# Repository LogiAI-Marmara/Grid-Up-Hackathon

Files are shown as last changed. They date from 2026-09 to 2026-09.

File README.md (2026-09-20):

# Grid-Up — Pano İçi Anomali Erken Uyarı Sistemi

**ADM & GDZ Elektrik — Grid Up Hackathon (2026)**  
*OG Hücreleri ve AG Dağıtım Panolarında Çok Kanallı Durum İzleme ve Uçtan Uca Anomali Erken Uyarı Platformu*

---

## 📌 Proje Özeti

Elektrik dağıtım şebekesindeki orta gerilim (OG) hücreleri ve alçak gerilim (AG) panolarında meydana gelen yangın, ekipman hasarı ve enerji kesintilerinin büyük bölümü (gevşek klemens, aşırı yük, faz dengesizliği, yoğuşma, yalıtım kaybı); **kritik arıza gerçekleşmeden önce ısınma, nem artışı ve akım dengesizlikleriyle sinyal verir.**

**Grid-Up**, pano içine yerleştirilen endüstriyel sınıf sensör modülü tasarımıyla başlayıp, saha gateway'i üzerinden şirket içi (**on-premise**) sunucuya ulaşan, çok katmanlı istatistiksel anomali tespit motoruyla arızayı kök nedeninde yakalayan ve operatörlere **SCADA (Modbus TCP)**, **Web İzleme Arayüzü** ile yerel ağdaki **Android SMS Gateway** üzerinden SMS bildirimi ileten uçtan uca, çalışan bir erken uyarı sistemidir.

> **Önemli Kısıtlar & Mimari İlkeler:**
> 1. **%100 On-Premise:** Şartname gereği **Public Cloud (AWS, Azure, GCP vb.) kesinlikle kullanılmamıştır.** Tüm veri saklama, analiz, arayüz ve alarm servisleri yerel ağda tek bir `docker-compose` komutuyla izole çalışır.
> 2. **Endüstriyel Donanım Tasarımı:** Şartname uyarınca fiziksel satın alma ve pano montajı yapılmamış; ancak TEDAŞ-MLZ/2003-06.B şartnamesine tabi **1600 kVA AG Dağıtım Panosu** referans alınarak −40…+85 °C endüstriyel sınıf bileşenlerle eksiksiz CAD (Fusion 360) ve EDA (KiCad) tasarım dokümantasyonu üretilmiştir.
> 3. **Gerçekçi Yazılım & Sentetik Veri:** Donanım üretilmediği için veri sentetik üreteçle fizik kurallarına uygun simüle edilmiş; yazılım tarafının tamamı (veri toplama, veritabanı, anomali motoru, REST API, Modbus TCP, alarm servisi, frontend) **gerçek ve çalışır durumdadır.**

---

## 🏛️ Uçtan Uca Sistem Mimarisi

Sistem, fiziksel pano içi donanımdan merkezi operasyon yüzüne kadar birbirine sıkı sözleşmelerle bağlı 3 ana katmandan oluşur:

```
┌──────────────────────── PANO İÇİ ─────────────────────────┐
│                                                           │
│  Sensörler: SHT31 (Sıcaklık/Nem) + MLX90640 (Termal Dizi) │
│  Akım: Enerji Analizörü (Modbus) veya Split-core CT ×4    │
│  Ark: ABB TVOC-2 (RS-485 Modbus Okuma)                    │
│                                │                          │
│                                ▼                          │
│               [ MODÜL: ESP32-S3-WROOM-1U-N8 ]             │
│               (230V İç İhtiyaç + Süperkapasitör)          │
│                                │                          │
│                                ▼                          │
│               Dış Anten (Panel SMA / 2.4 GHz)             │
└────────────────────────────────┼──────────────────────────┘
                                 │ Kablosuz (Wi-Fi)
                      ┌──────────▼──────────┐
                      │    SAHA GATEWAY     │ (Trafo binası içi, 230V)
                      └──────────┬──────────┘
                                 │ Mevcut Saha Altyapısı (HTTP)
        ═════════════════ ON-PREMISE SUNUCU ═════════════════
        │                                                   │
        │  ① Toplama Servisi (FastAPI :8000) ──► PostgreSQL │
        │                                            │      │
        │  ② Anomali Motoru (4 Katmanlı Medyan+MAD) ◄┘      │
        │         │                                         │
        │         ├──► ③ Okuma API'si (FastAPI :8080)       │
        │         │           │                             │
        │         │           ├─► ④ Web İzleme UI (nginx:80)│
        │         │           └─► ⑤ Modbus TCP (:5020/SCADA)│
        │         │                                         │
        │         └──► ⑥ Alarm Servisi                      │
        │                 ├─► Android SMS Gateway (LAN)     │
        │                 └─► Telegram (seçmeli, kapalı)    │
        ═════════════════════════════════════════════════════
```

Uçtan Uca Sistem Mimarisi
*Pano içi modülden saha gateway'ine, merkezi veritabanından analiz motoru, SCADA, web izleme arayüzü ve alarm servisine uçtan uca sistem mimarisi.*

---

## 📋 Teslimat Kalemleri Matrisi (T1 – T7)

Yarışma şartnamesindeki tüm teslimat kalemleri projemizde eksiksiz karşılanmıştır:

| Kod | Kalem | Karşılığı Olan Çıktılar & Konum |
|---|---|---|
| **T1** | **Kabin İçi Modül / Prototip Tasarımı** | [`docs/track-a/01-blok-sema.md`](docs/track-a/01-blok-sema.md) · [`02-bom.md`](docs/track-a/02-bom.md) · [`04-mekanik-yerlesim.md`](docs/track-a/04-mekanik-yerlesim.md) · [`06-montaj-proseduru.md`](docs/track-a/06-montaj-proseduru.md) · CAD Modelleri ([`cad/`](docs/track-a/cad/)) |
| **T2** | **Elektronik Tasarım Dokümantasyonu** | [`docs/track-a/03-pinout.md`](docs/track-a/03-pinout.md) · [`03-baglanti-semasi.svg`](docs/track-a/03-baglanti-semasi.svg) · KiCad EDA Projesi ([`eda/`](docs/track-a/eda/)) · [`02-pcb-yerlesimi.svg`](docs/track-a/02-pcb-yerlesimi.svg) |
| **T3** | **Yazılım Mimarisi** | [`docs/track-a/07-yazilim-akis.md`](docs/track-a/07-yazilim-akis.md) · [`08-sistem-mimarisi.svg`](docs/track-a/08-sistem-mimarisi.svg) · [`firmware/`](firmware/) · [`modul-sim/`](modul-sim/) · [`analiz/`](analiz/) · [`arayuz/`](arayuz/) |
| **T4** | **Monitoring (İzleme) Platformu** | [`arayuz/`](arayuz/) (Nginx üzerinde Web Dashboard, Isı Haritası, Canlı Metrikler) · [`modbus/`](modbus/) (SCADA Modbus TCP Sunucusu) |
| **T5** | **Ölçeklenebilirlik & Kaynak Kullanımı** | [`analiz/`](analiz/) (100 modül eşzamanlı ingest ve anomali tarama testi, kaynak tüketim raporu) · [`modul-sim`](modul-sim/) (`--modul 100`) |
| **T6** | **On-Premise / Özel Altyapı** | [`deploy/docker-compose.yml`](deploy/docker-compose.yml) (Public Cloud bağımsızlığı, tek komutla yerel orkestrasyon) |
| **T7** | **Alarm ve Acil Bildirim Mekanizması** | [`alarm/`](alarm/) (Android SMS Gateway yerel sunucu kipi, olay bazlı tekrar önleme, bekleyen kuyruğu ve kalıcı durum; Telegram bulut hizmeti olduğu için varsayılan kuralda yok — bkz. `alarm/README.md`) |

---

### 📐 Donanım ve Saha Tasarımı Çıktıları (T1 – T2)

PCB Yerleşimi
*ESP32-S3, MLX90640 termal dizi, SHT31, RAC05 güç modülü ve süperkapasitör içeren 110×70 mm 2 katmanlı endüstriyel modül PCB yerleşimi.*

Modül Bağlantı Şeması
*Besleme, I²C sensör hattı, RS-485 Modbus arayüzü ve anten bağlantı şeması.*

Pano İçi Mekanik Yerleşim Krokisi
*1600 kVA AG dağıtım panosu içinde modülün mekanik montaj konumu ve bara/klemens termal görüş açısı.*

Montaj Adımları Prosedürü
*Enerji kesintisi gerektirmeyen 7 adımlı standart pano içi montaj ve doğrulama prosedürü.*

---

## 📊 Sonuçlar ve Kanıt

Sistemin donanım maliyetleri ve bağımsız alt servislerin çalışır durumdaki test çıktıları aşağıda sunulmuştur:

### 1. Modül ve Pano Donanım Birim Maliyeti (T1 / T2)

TEDAŞ şartnamesine uygun endüstriyel sınıf (−40…+85 °C) bileşenlerle hazırlanan modül ve pano ölçeği maliyetleri:

| Senaryo | Birim Maliyet | Not |
|---|---|---|
| **Panoda analizör VARSA** (akım Modbus'tan okunur) | **$85,81 ≈ ₺4.175** | CT gerekmez — **hedef senaryo** |
| **Panoda analizör YOKSA** (4× split-core CT) | **$95,41 ≈ ₺4.642** | CT tanesi ~$2,40 (OEM liste fiyatı) |

| Ölçek | Tutar |
|---|---|
| **Demo (9 modül)** | **~$772 ≈ ₺37.575** |
| **100 modül (T5 senaryosu)** | **~$8.581 ≈ ₺417.500** |

*Komut: `python -c "import re; open('docs/track-a/02-bom.md', encoding='utf-8').read()"` (Bölüm 2.3, Kur: 1 USD = 48,66 TL, Fiyat tarihi: 2026-09-14).*

### 2. Doğrulama ve Test Sonuçları

Repodaki servislerin yerel ortamda koşturulan otomatik test ve doğrulama çıktıları:

| Servis / Bileşen | Test Kapsamı | Sonuç | Çalışma Süresi |
|---|---|---|---|
| **Sözleşmeler (`sozlesmeler/`)** | JSON Şema ve Enum sözlük tutarlılığı | **Başarılı (OK)** | 0.3s |
| **Modül Simülatörü (`modul-sim/`)** | 7 arıza senaryosu sinyal ve etiket doğrulaması | **39 passed** | 32.88s |
| **Alarm Servisi (`alarm/`)** | Teslim takibi, tekrar önleme, SMS Gateway, kalıcılık | **62 passed (OK)** | 0.087s |
| **İzleme Arayüzü (`arayuz/`)** | UI-01 – UI-08 Sözleşme ve veri akışı testleri | **8 passed** | 0.366s |
| **İzleme Arayüzü (`arayuz/`)** | UI-01 – UI-07 Kabul kriterleri ve hata izolasyonu | **21 passed** | 0.383s |
| **Toplama Servisi (`toplama/`)** | HTTP paket ingest API uç nokta testi | **5 passed** | 2.20s |

*Komutlar: `python sozlesmeler/dogrula.py`, `pytest modul-sim/tests/`, `python alarm/test.py`, `node --test arayuz/tests/test_arayuz_sozlesme.mjs`, `node --test arayuz/tests/test_arayuz_kabul.mjs`, `pytest toplama/tests/test_ingest.py`.*

---

## 🗂️ Repo Düzeni ve Katmanlar (İş İzleri)

Takım çalışması ve sözleşme sınırları 3 bağımsız iş izine bölünmüştür:

```
├── sozlesmeler/               # İzler arası ortak sözleşmeler (JSON şemaları ve Enum sözlüğü)
├── gridup-proje-karar-kaydi.md# Projenin üst karar kaydı
│
├── docs/                      # Jüriye sunulan nihai teknik dokümanlar
│   ├── track-a/               # İZ A: T1 & T2 donanım, mekanik, şema ve montaj dokümanları (01–09)
│   │   ├── cad/               # Fusion 360 modelleri (.f3d, .step) ve projeksiyon script'leri
│   │   └── eda/               # KiCad 10 şematiği (.kicad_sch), netlist ve sembol kütüphaneleri
│   ├── izb-karar-kaydi.md     # İZ B: Analiz katmanı ve dedektör mimarisi karar kaydı
│   └── operasyon-yuzu-dokumantasyonu.md # İZ C: Arayüz, alarm ve Modbus mimari dokümanı
│
├── modul-sim/                 # İZ A: 7 arıza senaryolu sentetik veri üreteci ve modül mantığı
├── toplama/                   # İZ A: FastAPI veri toplama servisi (:8000) ve PostgreSQL migrasyonları
├── firmware/                  # İZ A: ESP32-S3 sembolik firmware iskeleti (PlatformIO/C++)
│
├── analiz/                    # İZ B: İstatistiksel anomali tespit motoru, kör test ve Okuma API'si (:8080)
│
├── arayuz/                    # İZ C: Web tabanlı SCADA/Monitoring arayüzü (HTML5/Vanilla JS/Nginx :80)
├── modbus/                    # İZ C: SCADA entegrasyonu için Modbus TCP sunucusu (:5020)
├── alarm/                     # İZ C: Dayanıklı alarm dağıtım servisi (Android SMS Gateway, LAN)
└── deploy/                    # İZ C: On-Premise Docker Compose dağıtım yapılandırması
```

---

## 🚀 Hızlı Başlangıç (Tek Komutla Çalıştırma)

Tüm sistemi şirket içi (on-premise) ortamda ayağa kaldırmak için:

### 1. Ön Koşullar
- Docker ve Docker Compose (`docker compose version` ≥ 2.20)
- Python 3.11+ (Geliştirme ve birim testler için)

### 2. Tek Komutla Başlatma
```bash
# (İsteğe bağlı) SMS gateway adresi/kimlik bilgileri için ortam dosyası;
# yoksa da yığın kalkar, kritik alarmlar teslim edilene kadar kuyrukta bekler
cp deploy/.env.example deploy/.env

# Tüm servisleri arka planda ayağa kaldırın
docker compose -f deploy/docker-compose.yml up -d
```

### 3. Canlı Servis Portları ve Erişim

| Servis | Adres / Port | Açıklama |
|---|---|---|
| **Monitoring Dashboard** | `http://localhost:80` | Web arayüzü (Pano hiyerarşisi, canlı grafikler, termal ısı haritası) |
| **Toplama (Ingest) API** | `http://localhost:8000` | Gateway/Modül veri alım uç noktası (`POST /paket`, `GET /saglik`) |
| **Okuma API'si (Analiz)** | `http://localhost:8080` | İz B REST API (`/sahalar`, `/moduller`, `/anomaliler`, Swagger `/docs`) |
| **Modbus TCP Sunucusu** | `localhost:5020` | SCADA/RTU PLC entegrasyonu için Sözleşme ④ register haritası |
| **PostgreSQL Veritabanı** | `veritabani:5432` *(Docker ağı içi)* | Merkezi zaman serisi ve anomali deposu (güvenlik için dış host portu kapalıdır) |

### 4. Duman Testini Koşturma
Servislerin birbirleriyle uçtan uca haberleştiğini doğrulamak için:
```bash
python duman_testi_kosturucu.py
```

---

## 📡 Sözleşmeler ve Ortak Sözlükler

İzler arasındaki sınır ve entegrasyon `/sozlesmeler` altındaki standartlarla korunur:

- **① Ölçüm Kaydı (`olcum_kaydi.schema.json`):** Uzun-dar formatta zaman serisi ölçüm satırı (`modul_id, zaman, olcum_tipi, deger, kalite`).
- **② Modül Paketi (`modul_paketi.schema.json`):** Gateway'den sunucuya iletilen paket (`olcumler, termal_ozet, termal_kare, modul_durum`).
- **③ Anomali Çıktısı (`anomali.schema.json`):** Anomali motorunun tespit kaydı (`id, modul_id, skor, seviye, tip, gerekce, kanit, durum`).
- **④ Modbus Register Haritası (`sozlesme_4_modbus.json`):** Modül başına 20 register ayrılmış, SCADA uyumlu tamsayı haritası.
- **⑤ Okuma API'si:** İz C'nin İz B'den veri çektiği standart REST+JSON arayüzü.

### Simüle Edilen 7 Arıza Senaryosu
1. **Gevşek Klemens:** Akım sabitken tek noktada (klemens) temas direnci artışı ve aşırı ısınma.
2. **Aşırı Yük:** Tüm faz akımlarının anma değerini aşması ve genel kabin sıcaklığının yükselmesi.
3. **Faz Dengesizliği:** Faz akımları arasındaki dengesizlik ve nötr hattından akım akması.
4. **Nem Yükselmesi:** Pano içi bağıl nemin artması ve çiğ noktası yaklaşımıyla yoğuşma/yalıtım riski.
5. **Ark Olayı:** Optik ark koruma rölesinden (ABB TVOC-2) tetiklenme sinyalinin yakalanması.
6. **Sensör Arızası:** Ölçümün donması veya geçersiz değerler üretmesi (`kalite: supheli/yok`).
7. **Modül Sağlığı:** Şebeke enerjisi kesintisi (`besleme: yedek`), RF sinyal zayıflığı ve saat kayması.

---

## 🧪 Testler ve Doğrulama

Projeye dahil tüm bileşenler kapsamlı otomatik testlerle donatılmıştır:

```bash
# Şema ve sözleşme tutarlılık denetimi
python3 sozlesmeler/dogrula.py

# İZ A modül simülatörü ve toplama servisi testleri
pytest modul-sim/tests/ toplama/tests/

# İZ B anomali motoru ve kör test doğrulayıcı testleri
pytest analiz/tests/

# İZ C alarm servisi, Modbus sunucusu ve web arayüz sözleşme testleri
cd alarm && python3 -m unittest test && cd ..
python3 modbus/test_modbus_service.py
npm test --prefix arayuz                    # sözleşme + kabul testleri, node:test
sh arayuz/dogrulama/docker_dogrula.sh       # imaj + Nginx vekil yolu (Docker gerekir)

# Donanım EDA şematik bağlantı (netlist) doğrulaması ve mimari üreteci
python3 docs/track-a/eda/verify_netlist.py docs/track-a/eda/GridUp-Modul.net
python3 docs/track-a/eda/gen_mimari.py
```

---

## 👥 Takım (LogiAI Marmara)

- **Efe Özan (thozoz):** İZ A — Veri Yolu, Donanım Tasarım Dokümantasyonu, Sentetik Veri Simülatörü, Toplama Servisi.
- **İsmail Efe (ism00efe):** İZ B — Analiz Katmanı, İstatistiksel Anomali Motoru, Okuma API'si, Ölçeklenebilirlik Testi.
- **Onur Demir (onurdemir123456):** İZ C — Operasyon Yüzü, Web İzleme Arayüzü, Modbus TCP Sunucusu, Alarm Servisi, On-Prem Kompozisyon.

---
*Proje lisansı: [Apache License 2.0](LICENSE)*

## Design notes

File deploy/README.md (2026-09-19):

# Yerel entegrasyon

Depo kökünden tek komutla bütün zinciri başlatın:

```powershell
docker compose -f deploy/docker-compose.yml up -d --build --wait
```

PowerShell için `./baslat.ps1 -Build`, Windows komut istemi için `baslat.bat`
aynı kompozisyonu başlatır. Başlatıcılar bir servis sağlıklı duruma gelmezse
hata koduyla çıkar. Arayüz `http://localhost/`, okuma API'si
`http://127.0.0.1:8080`, toplama servisi `http://127.0.0.1:8000` ve Modbus TCP
`localhost:5020` üzerindedir. PostgreSQL yalnız Docker ağı içinden
`veritabani:5432` adresiyle erişilir. Telegram değişkenleri isteğe bağlıdır;
`deploy/.env` dosyası gerekmez. Alarm imleci kalıcı `gridup_alarm_durum`
volume'unda tutulur.

Entegrasyon duman testini depo kökünden çalıştırın:

```powershell
python duman_testi_kosturucu.py
```

Koşturucu kendi geçici Compose projesini ve `gridup_smoke` veritabanını kurar.
İZ A simülatöründen bir paketi toplama servisine gönderir ve İZ B okuma API'sinde
göründüğünü doğrular. Sonra İZ B'nin bilinen senaryo fikstürünü aynı test
veritabanına yazar; temiz modül, gevşek klemens, besleme kaybı ve seviye geçişi
kontrollerini `analiz.duman` ile çalıştırır. Her durumda yalnız kendi geçici
projesini ve volume'larını siler. Var olan `gridup` veritabanına bağlanmaz.

Sistemi durdurmak için:

```powershell
docker compose -f deploy/docker-compose.yml down
```

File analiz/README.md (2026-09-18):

# /analiz — İZ B, the analysis layer

Owns one question: **how does an anomaly come out of the data?**

Reads the measurement and thermal tables track A writes. Produces anomaly
episodes that track C reads. Touches no other track's code — decision K1's whole
point is that the only contact surface between A and B is a set of database
tables.

Authoritative specification: [`../docs/izb-karar-kaydi.md`](../docs/izb-karar-kaydi.md).
Every design decision below is from it; section numbers in the code refer to it.
The **integration-phase decisions** (episode model for contract ③, `modul_durum`,
binary thermal frames at every instant, the clock-drift table, the global
`/gecisler` feed) supersede the older documents where they differ; see
[Entegrasyon aşaması](#entegrasyon-aşaması--neler-değişti) below.

---

## What is here, and what is not

| Delivered |
|---|
| Package skeleton, config, entry point |
| Database layer, track B's own tables |
| Scan loop, cursor, manual rewind (K1) |
| Evaluation-window fetcher |
| All four detector layers (K2) |
| Score, severity, `gerekce` production |
| Episode lifecycle and journal (K3) |
| Fixtures: 7 scenarios + clean + hard negatives |
| **Read API — contract ⑤, including `/anomaliler/{id}/gecisler` and the global `/gecisler` feed** |
| **Label file format** (a contract track A must satisfy) |
| **Blind-test evaluation tool — four metrics** |
| **Load test and resource report (T5)** |
| **Smoke-test checks** (`analiz.duman`) — the entry point track C's runner calls |

Track B is complete; the integration-phase adaptation (items 6–14 of the
integration task) is on this branch.

---

## Quick start

```bash
cd analiz
pip install -e '.[api,test]'

createdb gridup
export GRIDUP_ANALIZ_VERITABANI_DSN=postgresql:///gridup

python -m analiz sema          # track A's migrations, then track B's
python -m analiz tara          # run the scan loop
python -m analiz durum         # cursor and episode state
python -m analiz geri-al -24h  # rewind, re-scan the last day
```

**Where the shared schema and vocabularies come from.** Track B defines none of
the shared tables and none of the shared enums. `python -m analiz sema` applies
`toplama/migrations/*.sql` (track A's, in file-name order) and then
`analiz/migrations/100_analiz.sql` (track B's own tables and indexes);
`analiz.sozlesme` imports `sozlesmeler/enums.py`. Both are found relative to
the repository root by default, and can be pointed elsewhere:

| Variable | Meaning | Default |
|---|---|---|
| `GRIDUP_TOPLAMA_MIGRASYON_DIZINI` | directory holding track A's `*.sql` | `<repo>/toplama/migrations` |
| `GRIDUP_SOZLESMELER_KOK` | directory that *contains* `sozlesmeler/` | `<repo>` |

On a checkout without `toplama/` and `sozlesmeler/` (this branch, before track
A's PR is on main), export them once — outside the repo — and point at the copy:

```bash
git archive origin/feature/track-a toplama/migrations sozlesmeler | tar -x -C /tmp/track-a
export GRIDUP_TOPLAMA_MIGRASYON_DIZINI=/tmp/track-a/toplama/migrations
export GRIDUP_SOZLESMELER_KOK=/tmp/track-a
```

The read API, as its own process:

```bash
python -m analiz.api --dsn postgresql:///gridup --port 8080
# or: python -m analiz sunucu --port 8080
# OpenAPI schema at /openapi.json, browsable docs at /docs
```

Everything end to end against the scenario set, leaving the database to inspect:

```bash
createdb gridup_dogrulama
python -m analiz.dogrulama --dsn postgresql:///gridup_dogrulama
```

Blind test (see [the protocol](#kör-test-protokolü)):

```bash
python -m analiz.kortest dondur      --dsn postgresql:///gridup --cikti cikti.json
python -m analiz.kortest degerlendir --etiket etiket.json --cikti cikti.json
```

Load test (T5):

```bash
python -m analiz.yuk --dsn postgresql:///gridup_yuk --moduller 10,50,100
```

Smoke-test checks against a live API (see [Duman testi](#duman-testi--iz-cnin-çağıracağı-giriş-noktası)):

```bash
python -m analiz.duman --api http://127.0.0.1:8080 --senaryolar duman.json
```

Tests (needs a PostgreSQL 14+ the current user can `createdb` on; the two
variables above if `toplama/` is not in the checkout):

```bash
python -m pytest -q
```

---

## Layout

```
analiz/
  sozlesme.py       re-exports sozlesmeler/enums.py; only B-specific helpers
  termal.py         the binary frame: int16 LE, 0.1 °C, 1536 bytes <-> 768 °C
  ayar.py           every threshold and window — configuration, not constants
  db.py             connection; applies toplama/migrations/*.sql then 100
  migrations/
    100_analiz.sql    anomali, anomali_gecis, tarama_imleci, B's indexes
  depo.py           the scan cursor                                     K1
  tarama.py         the scan loop                                       K1
  pencere.py        evaluation-window fetcher
  dedektor/
    istatistik.py     median, MAD, robust z, slope
    katman0_sensor.py sensor health — runs first, can veto a channel
    katman1_mutlak.py absolute limits, baseline-free
    katman2_taban.py  baseline deviation: magnitude and trend
    katman3_iliski.py relationships, and false-alarm suppression
    motor.py          runs the layers in order, merges findings
  skor.py           magnitude -> (severity, score)
  gerekce.py        the sentence the operator reads
  olay.py           episode lifecycle and the journal                   K3
  api.py            contract ⑤, served as its own process
  etiket.py         the label file format — the blind test's answer key
  kortest.py        blind-test evaluation: freeze, then four metrics
  yuk.py            load test and resource report                        T5
  fikstur.py        contract-shaped row writer
  senaryolar.py     the labelled set: 7 scenarios + clean + hard negatives
  dogrulama.py      end-to-end harness, and the turn-by-turn replay
  duman.py          smoke-test checks against a live API (track C calls it)
```

---

## The three decisions, as implemented

### K1 — periodic scan, cursor, rewindable

A background job. Every `tarama.periyot_sn` (default 30 s — see [T5](#t5--ölçeklenebilirlik-raporu)
for why it is not section 3.7's 10 s) it asks what has
arrived since its cursor, works out which modules those rows belong to,
evaluates **each of those modules once**, writes findings, advances the cursor.

Two implementation choices worth knowing about, both in `ayar.TaramaAyari`:

**The cursor tracks `alindi_zaman`, not `zaman`.** This is what makes section
3.6's "late data is caught for free" actually true. A module that loses its
uplink for five minutes and then sends 300 rows stamps them with *old*
measurement times; a cursor on `zaman` would already have moved past them and the
batch would be lost silently. Arrival time is monotonic per row, so a cursor on
it cannot skip. Tested in `test_tarama.py::test_tek_turda_gelen_hicbir_satir_dusmez`.

**The evaluation instant is per module, not per turn.** Derived from the newest
measurement that arrived for that module. Without this, a backlog and a
historical re-scan would both anchor their windows on the present and evaluate
empty windows — which would make the rewind feature silently useless, and rewind
is section 3.4's first argument for polling over push.

A module that has gone *silent* produces no rows and so can never appear in a
row-driven set. A separate sweep adds those modules, judged at the turn's own
instant. That is scenario 7.

### K2 — four layers, no machine learning

Run in order; the order is not cosmetic.

| | Looks at | Fires on |
|---|---|---|
| **0** sensor health | `kalite`, frozen values, impossible values, silence, clock drift, backup power, weak signal | `sensor_arizasi`, `modul_saglik` |
| **1** absolute limits | the value alone | `sicak_nokta`, `ortam_sicaklik_yuksek`, `nem_yuksek`, `faz_dengesizligi`, `ark` |
| **2** baseline deviation (fast, hours) | median + MAD magnitude, capped at `izle` (D2); trend is informational text only | `sicak_nokta`, `ortam_sicaklik_yuksek` |
| **2** normalized heating (slow, days–weeks, D1) | (hot spot − ambient) / current^n vs its own early-window level, mapped to FIST 4-13 bands | `akim_sicaklik_sapmasi` |
| **3** relationships | current↔temperature, phase↔phase, pixel↔frame, module↔module | `akim_sicaklik_sapmasi`, `faz_dengesizligi`, `sicak_nokta` |

**Post-review correction (decisions D1–D3, this PR):** layer 2's trend half
(the old `egilim_izle/uyari/kritik`-driven finding) no longer sets a severity
on its own — see [D2](#d2--severity-is-an-action-not-a-forecast) below — and a
second, slower evaluation now runs alongside the original 6-hour window for
exactly the multi-day fault the fast window structurally cannot see. Layer 3's
current-vs-temperature check no longer substitutes 0 °C for a missing ambient
channel (D3). Layer 0's physical-range check now runs before, not after, the
minimum-sample gate (D3).

Layer 0 runs first because everything after it assumes the numbers are real, and
its veto is **per channel** — a dead humidity sensor must not blind the thermal
detector on the same module. Layer 3 runs last because it is the only layer
allowed to take something back.

**The detector never judges a single sample.** Section 3.6 says it never looks at
"the current value", and `Seri.temsil()` is where that holds: layers judge the
median of the newest `pencere.temsil_ornek` samples. Judging the latest reading
would turn every noise spike into a work order — see the `gurultulu_*` modules in
the scenario set, which exist to catch exactly that regression.

**Baseline poisoning** (section 5's design note) is the failure mode that would
make layer 2 quietly useless: a sliding baseline absorbs a slow fault as fast as
it grows, learns it as the new normal, and goes silent exactly when it should
not. Three defences, all in `PencereGetirici._tabanlar` where the samples are
selected:

1. the baseline window is far longer than the detection window (14 d vs 6 h);
2. it stops `taban_bosluk_sn` short of the present, so a value is never judged
   against itself;
3. it is **frozen at onset** while an episode is open, and stretches inside past
   episodes are excluded.

**Layer 3 reduces false alarms rather than adding them.** On a hot afternoon
every panel on a site warms, layer 2 sees every module leave its band at once,
and alone it would raise one alarm per module. The module-to-module comparison
returns a suppression instead. The `ortak_isinma_*` modules test this.

Two departures from a literal reading of the record, both because the literal
version does not survive contact with real data:

- **Current-vs-temperature is posed as an I²R residual, not as "is the current
  flat?"** Over a six-hour window the current is never flat — a panel's load
  follows a daily profile, so a flatness test fires reliably at 4 a.m. and never
  in the afternoon. A joint dissipates I²R, so the rise the load explains is
  *computable*; what is left over needs R to have changed, which is the fault.
  It also gets the overload case right in the other direction: when the current
  really did double, I² explains more than the observed rise and the test stays
  correctly silent. `katman3_iliski._akim_sicaklik` has the full argument.
- **A specific diagnosis absorbs the generic finding it explains.** One loose
  terminal legitimately trips several tests; as separate episodes they are
  separate work orders for one repair. The survivor takes the *worse* of the two
  severities, so an absolute safety limit can never be quietly downgraded by a
  diagnosis. `motor._ozgulluk`.

No machine learning anywhere, for section 4.3's reasons — the decisive one being
that `gerekce` cannot be produced from a model score, and `gerekce` is mandatory.

### K3 — episode model plus journal

Section 6.2's arithmetic: a three-day fault at a 10 s period is 25,920 turns. A
row per turn would be 25,920 anomaly rows for one loose screw, and `durum` would
mean nothing because there would be no single row to acknowledge.

So the same `modul_id` + the same `tip`, not yet closed, is the **same episode** —
enforced by a partial unique index, not by convention, so two concurrent turns
cannot both open it. Repeated findings update it.

`gridup.anomali_gecis` is the journal: one permanent row per state or severity
transition, following ISA-18.2's split between an alarm status table and an alarm
journal. Not for display — for the audit trail. A severity change is a
transition; a score moving 0.81 → 0.83 inside `uyari` is not.

Episodes close after `olay.histerezis_sn` (default 30 min) without the condition.
Without hysteresis a value sitting on a threshold opens and closes an episode all
afternoon, and every open is an alarm.

---

## API kararları (sözleşmenin sessiz kaldığı yerler)

Contract ⑤ fixes the paths, the query parameter names and the field names. It
says nothing about pagination, error shapes or status codes. These are the
choices this implementation made; **track C needs all of them.**

### Sayfalama

`GET /anomaliler` pages by **keyset on `sira`**, not by offset:

```
GET /anomaliler?limit=50            -> {"veriler": [...], "sonraki": 1234, "limit": 50}
GET /anomaliler?limit=50&sonra=1234 -> the next page
```

`sonraki` is `null` on the last page. Section 7.2 puts a monotonic sequence on
the anomaly table precisely so the alarm service can ask for "everything after
the last id I handled" and be certain it missed nothing — offset paging cannot
make that promise, because an episode opening between two requests shifts every
later row by one and the caller silently skips an alarm.

`GET /moduller` uses `limit`/`ofset` and returns `toplam`. The module list is
bounded by the size of the fleet and does not change under the reader.

### Hata biçimi

One shape for every failure, so track C writes one handler:

```json
{"hata": {"kod": "bulunamadi", "mesaj": "Anomali bulunamadı: an_00412", "kimlik": "an_00412"}}
```

`kod` is a stable slug to branch on. `mesaj` is Turkish, because it can end up
in front of an operator. Extra keys are error-specific and additive.

| Kod | Durum | Ne zaman |
|---|---|---|
| `bulunamadi` | 404 | unknown module, anomaly or frame id |
| `gecersiz_zaman` | 400 | `bas` / `bit` is not ISO 8601 |
| `gecersiz_aralik` | 400 | `bit` precedes `bas` |
| `gecersiz_aralik_adi` | 400 | `aralik` outside the accepted set |
| `cok_fazla_nokta` | 400 | the series would exceed `azami_seri_noktasi` |
| `onaylanamaz` | 409 | acknowledging an episode that is not `acik` |
| `veritabani_erisilemez` | 503 | `/saglik` cannot reach the database |
| — | 422 | FastAPI enum/validation failure (e.g. an unknown `olcum_tipi`) |

### Diğer kararlar

**`durum` on `/moduller` is the MODULE's state**, with the vocabulary
`aktif | sessiz | pasif` — *not* the anomaly lifecycle's
`acik | onaylandi | kapandi`. The contract lists the column under that name and
the collision is the easiest thing to get wrong here. `sessiz` means no
measurement for longer than `katman0.sessizlik_sn`.

**The series endpoint refuses rather than truncates.** Over
`azami_seri_noktasi` (default 5000) it returns `cok_fazla_nokta` naming the
remedy. A chart quietly missing its last three days looks fine and is wrong, and
the caller cannot tell.

**A bucketed series carries `asgari` and `azami` beside `ort`.** `aralik` accepts
`10s | 1m | 5m | 15m | 1h | 1d`. A mean alone hides exactly the spike an operator
is looking for — a bucket averaging 46 °C may have touched 130.

**`/saglik` reports the scan cursor's lag**, not just liveness. Section 8 names a
detector falling behind its scan period as the real scaling limit, so a green
light over a stale anomaly table would be a lie. Watch `imlecler[].gecikme_sn`.

**`/saglik` also reports the data-delay metric, `veri_gecikmesi`.** Late
(backfilled) data is not an anomaly — see the clock-drift table below — so it is
exposed here instead: over rows that arrived in the last
`api.veri_gecikme_pencere_sn` (15 min), `azami_sn` / `p50_sn` / `p95_sn` of
`alindi_zaman − zaman`, `geciken_satir` above `katman0.saat_kaymasi_sn`, and the
modules responsible in `geciken_moduller[]`.

**`GET /moduller/{id}` carries `besleme` and `sinyal`** — the newest
`modul_durum` row's values (`sebeke | yedek`, dBm) and `durum_zaman`, when it
was reported. All three `null` for a module that has never sent a status packet.

**`GET /termal/kare/{id}` returns 768 °C numbers, as before.** Storage is
binary now (`bytea`, int16 LE, 0.1 °C, 1536 bytes); the API decodes. `birim`
is `"C"`.

**`GET /gecisler?sonra=<id>&limit=<n>` is the global transition feed:**

```json
{
  "veriler": [
    {"id": 1841, "anomali_id": "an_00412", "zaman": "2026-09-09T06:40:00Z",
     "alan": "seviye", "onceki": "izle", "yeni": "uyari", "aktor": "sistem"}
  ],
  "sonraki": 1841,
  "limit": 100
}
```

Keyset on the journal's own `id`, ascending, same pattern as `/anomaliler`:
pass the last `id` you handled as `sonra` and nothing between two polls can be
skipped. `alan` is only `durum` or `seviye`; `onceki` is `null` on an episode's
first transition; `aktor` is `sistem` for the detector and the operator identity
for an acknowledgement. One difference from `/anomaliler`, deliberate: `sonraki`
is the `id` of the last row returned (or `null` only when the page is empty), so
a poller stores it blindly and resumes from it — a feed has no last page.

**Timestamps are always UTC ISO 8601 with a literal `Z`.** Offsets are never
emitted.

**The anomaly body is exactly contract ③'s episode shape:** `id, sira,
modul_id, tip, seviye, maks_seviye, skor, ilk_gorulme, son_gorulme, durum,
gerekce, kanit`. The single-`zaman` shape is invalid since the integration
phase and the `zaman` alias this API used to emit is gone. Detector-internal
extras (`katman`, `kapanma_zaman`) travel inside `kanit`.

**Writes.** The API is read-only except `POST /anomaliler/{id}/onayla`, which
requires `aktor` and goes through `OlayDeposu` rather than issuing its own
UPDATE — so the episode tables keep exactly one writer and the acknowledgement
lands in the journal with who and when.

---

## Etiket dosyası formatı

> **İZ A için.** The blind-test tool cannot compute lead time without this file,
> and lead time is the project's headline claim. This section is the spec.

A blind set is data plus a label file. The data goes into the database; the label
file **stays with the producer** until the detector's output has been frozen
(section 4.4). It is JSON, UTF-8, and `analiz.etiket` parses it strictly.

```json
{
  "surum": 1,
  "tohum": 20260915,
  "uretim_zamani": "2026-09-15T09:40:00Z",
  "kapsam": { "bas": "2026-08-31T09:40:00Z", "bit": "2026-09-15T09:40:00Z" },
  "senaryolar": [
    {
      "senaryo_id": "senaryo_01",
      "modul_id": "TR041-P01-M1",
      "senaryo": "gevsek_klemens",
      "baslangic": "2026-09-08T14:00:00Z",
      "kritik_esik": "2026-09-10T03:00:00Z",
      "aciklama": "L2 çıkış klemensi gevşetildi"
    }
  ],
  "temiz_moduller": ["TR041-P01-M2", "TR052-P01-M1"]
}
```

| Alan | Zorunlu | Anlamı |
|---|---|---|
| `surum` | evet | Format version. Currently `1`. A reader refuses a version it was not built for rather than guessing. |
| `senaryolar[].modul_id` | evet | Which module the scenario was injected into. |
| `senaryolar[].senaryo` | evet | Which of the seven. Fixed vocabulary, below. |
| `senaryolar[].baslangic` | evet | When the injection began — the first moment anything was wrong. |
| `senaryolar[].kritik_esik` | hayır | When the fault reached its critical state. **Lead time is computed from this.** Omit only for a fault that does not escalate. |
| `senaryolar[].senaryo_id` | hayır | A label for the report. Defaults to `senaryo_01`, `senaryo_02`, … |
| `senaryolar[].beklenen_tip` | hayır | Pins the accepted anomaly `tip`(s). Normally omitted — see below. |
| `temiz_moduller` | evet | Modules deliberately left untouched. May be empty only if the set genuinely has none, and then the false-alarm rate cannot be measured at all. |
| `kapsam` | hayır | Observation window. The denominator of the per-module-day false-alarm rate. |
| `tohum`, `uretim_zamani`, `aciklama` | hayır | Provenance. |

**`senaryo` vocabulary** — section 7.6's seven, and no others:

```
gevsek_klemens | asiri_yuk | faz_dengesizligi | nem_yukselmesi |
ark_olayi | sensor_arizasi | modul_saglik
```

### İki nokta İZ A'nın dikkatine

**1. `kritik_esik` olmadan kazanılan süre hesaplanamaz.** Lead time is the
subtraction between the moment the detector first opened an episode and the
moment the fault became critical. The first number is in our database; the
second is known **only to the generator**. If it is not written down the metric
cannot exist, however good the detector is — and section 2.5 makes that metric
the project's actual product. For a ramp injection the end of the ramp is a
perfectly good answer; for an instantaneous event it is the event itself.

**2. `beklenen_tip` yazmayın — gerek yok.** Track A knows it injected a loose
terminal. Whether that surfaces as `akim_sicaklik_sapmasi` (the diagnosis) or
`sicak_nokta` (the observation) is track B's business, and both are correct
detections of the same screw. The mapping from scenario to acceptable `tip`
lives in `etiket.SENARYO_TIPLERI`, on this side. If track A pinned a single
expected `tip`, the evaluation would be measuring whether track B's naming
matched track A's guess about track B's naming, which is not a property of the
detector. `beklenen_tip` exists only for a set deliberately testing one specific
classification.

### Ayrıca

- Parsing is strict. An unknown scenario name, a missing field, a naive
  timestamp, a `kritik_esik` before its `baslangic`, or a module listed both
  clean and injected are all **errors**, never skipped rows. A half-parsed label
  file yields a detection rate computed over whatever survived parsing — which
  looks like a result, is not one, and is wrong in the flattering direction.
- Timestamps are UTC ISO 8601. A naive timestamp is rejected rather than assumed
  to be UTC: an unstated timezone shifts every lead time by the offset, silently
  and by hours.
- The fixture set emits this exact format (`senaryolar.etiket_uret`), so a real
  blind set drops straight into the tool with nothing to adapt.

---

## Kör test protokolü

Section 4.4, as commands:

```bash
# 1-2. track A generates the data and keeps the label file.
#      track B loads only the data.

# 3. the detector runs, and its output is FROZEN.
python -m analiz tara --tur 500
python -m analiz.kortest dondur --dsn postgresql:///gridup --cikti cikti.json

# 4. the key is opened and the four metrics are computed.
python -m analiz.kortest degerlendir --etiket etiket.json --cikti cikti.json
```

Freezing is a separate command on purpose. Section 4.4's second trap is that a
set stops being blind the moment a result is seen and the detector is re-tuned
against it. A frozen output file makes "this is what the detector said before
anyone looked at the answers" a checkable artefact rather than a promise.
Nothing in the freeze path reads the labels.

**The four metrics are reported together, always.** Any one alone is misleading:
a detector that alarms on everything scores a perfect detection rate, and one
that never fires a perfect false-alarm rate.

| Metrik | Nasıl hesaplanır |
|---|---|
| Tespit oranı | Per scenario, whether an episode of an accepted `tip` appeared on that module. |
| **Kazanılan süre** | `kritik_esik` − the earliest matching episode's `ilk_gorulme`. Positive means we warned that far ahead. |
| Yanlış alarm | Episodes on `temiz_moduller` ÷ (clean modules × observation days). |
| Sensör ayrımı | Share of `sensor_arizasi` / `modul_saglik` scenarios classified as such **and** producing no grid-fault episode. |

Judgement calls, each covered by a test:

- An extra episode on a genuinely faulty module is a **second true symptom, not
  a false alarm** — overload heats the cabinet as well as the busbar. False
  alarms are counted on the clean modules, where section 4.4 puts them.
- A scenario with no `kritik_esik` contributes to detection but is **excluded
  from the lead-time median** rather than counted as zero.
- With no clean modules the false-alarm rate is **undefined, not perfect**.
- Lead time uses the earliest matching episode **by measurement time**, not by
  episode id: the id is the order rows were written; the claim is about when we
  could first have told someone.
- A late detection yields a **negative** lead time rather than an absolute
  value, so a detector that is consistently late cannot look like one that is
  early.

### Kazanılan süre neden tur tur oynatmayı gerektirir

`dogrulama.kos` runs a couple of turns at the end of the fixture window. That is
enough to prove each scenario is found and **useless for saying when**: every
episode opens at the last measurement, so lead time reads ≈0 for everything.

`dogrulama.oynat` replays the loop turn by turn across the data the way the clock
passes in the field, so an episode opens on the turn where the evidence first
crossed a threshold — which is when a real deployment would have spoken. Any
lead-time number produced without it is meaningless.

---

## Entegrasyon aşaması — neler değişti

Integration task items 6–14, in the order they touch the code. The question the
phase answers is "does data flow end to end"; detector thresholds and trend
logic were not changed.

**No second copy of the contract (6, 6a, 7).** `migrations/000_sozlesme.sql` is
gone; `sema_kur` applies track A's `toplama/migrations/*.sql` and then
`100_analiz.sql`, which now also carries the three indexes track B needs on
track A's tables (`olcum_alindi_zaman_idx`, `termal_ozet_alindi_zaman_idx`,
`modul_durum_alindi_zaman_idx`). `sozlesme.py` imports `sozlesmeler/enums.py`
and defines only `AKIM_FAZLARI`, `SICAKLIK_KANALLARI`, `en_yuksek_seviye`. It
refuses to import if the shared `Tip` lacks `asiri_yuk`, naming the follow-up
(the `ASIRI_YUK = "asiri_yuk"` line in `sozlesmeler/enums.py`, to be applied
once main contains track A's PR). `asiri_yuk` is in the `anomali.tip` CHECK and
in `etiket.SENARYO_TIPLERI["asiri_yuk"]`; the detector does not yet emit it.

**Module status (8).** `gridup.modul_durum` (one row per packet: `besleme`,
`sinyal`, `yazilim_surumu`, `alindi_zaman`) is read into the window as
`Pencere.durumlar`. Layer 0 produces `modul_saglik` for:

| Cause | Rule | Configuration (`katman0`) |
|---|---|---|
| `besleme` | newest `besleme_yedek_ardisik` rows say `yedek` | `besleme_yedek_ardisik=2`, `besleme_seviye=uyari` |
| `sinyal` | median of newest `sinyal_ornek` rows below the floor | `sinyal_zayif_dbm=-100`, `sinyal_ornek=5`, `sinyal_seviye=izle` |

`kanit.neden` names the cause (`sessizlik | saat_kaymasi | besleme | sinyal`);
the engine keeps one episode per `tip`, so when several fire the worst wins and
`neden` says which. A `modul_durum` arrival is a "re-evaluate this module"
signal in the scan loop's range query, so a module sending only status is
still evaluated (`test_8_yalnizca_durum_gonderen_modul_yeniden_degerlendirilir`).

**Clock drift vs late data (9).** Per sample, gap = `alindi_zaman − zaman`:

| Observed in the window | Meaning | Output |
|---|---|---|
| a gap below `−ileri_tarih_tolerans_sn` (5 s) — measured after it was received | certain drift, clock ahead | `modul_saglik`, `kanit.yon = ileri` |
| **minimum** gap above `saat_kaymasi_sn` (120 s) — no reading is fresh | drift, clock behind | `modul_saglik`, `kanit.yon = geri` |
| minimum near zero, maximum high | late (backfilled) data | nothing; `/saglik` → `veri_gecikmesi` |

The previous rule judged the *maximum* gap and so called every backlog a broken
clock, contradicting section 3.6's "late data is caught for free". The fixture
set now has a backfilled hard negative (`gec_veri_01`) beside the drift scenario.

**Evidence frame at the event's time (10).** `kanit.kare_id` is the newest
frame at or before the module's evaluation instant, inside the detection
window — never a frame later than the instant, including on a historical
re-scan (`test_10_gecmis_yeniden_taramada_olayin_kendi_karesi_baglanir`). A
module with no frame in its window gets no `kare_id` rather than a stale one.

**Binary frame (11).** `termal_kare.piksel_verisi` is `bytea`: int16 signed,
little-endian, 0.1 °C, row-major, 768 values, exactly 1536 bytes. `termal.py`
is the codec; `GET /termal/kare/{id}` decodes; the fixtures encode. A full
frame now arrives at every measurement instant (30 s), same period as
`termal_ozet`; `/moduller/{id}/termal/son` reports the frame at the summary's
instant.

**Module detail (12), global feed (13).** See "API kararları" above.

**Smoke-test checks (14).** Next section.

---

## Duman testi — İZ C'nin çağıracağı giriş noktası

> **İZ C için.** The runner is yours: start the simulator, the collector, the
> detector and this API, then call this. The checks are ours. Exit 0 means every
> check passed; 1 means at least one failed (each failure is one line on
> stdout); 2 means the input was bad or the API could not be reached.

```bash
pip install -e 'analiz'                       # no extra dependency: stdlib HTTP
python -m analiz.duman --api http://127.0.0.1:8080 --senaryolar duman.json
# options: --azami-imlec-gecikme-sn 600   fail if the scan cursor is further behind
#          --json rapor.json              also write the report as JSON
#          --zaman-asimi-sn 30            per-request timeout
```

**Input — which module carries which scenario.** JSON, UTF-8. This is the
runner's knowledge (it told the simulator what to inject), so it is an input
to the checks, not something they infer:

```json
{
  "surum": 1,
  "bas": "2026-09-16T06:00:00Z",
  "moduller": {
    "TR041-P01-M2": "temiz",
    "TR041-P01-M1": ["gevsek_klemens", "seviye_gecisi"],
    "TR063-P02-M3": "besleme_kaybi"
  }
}
```

| Field | Required | Meaning |
|---|---|---|
| `surum` | yes | Format version, `1`. |
| `bas` | no | Only episodes with `ilk_gorulme ≥ bas` count. Set it to the run's start so a database that has seen earlier runs cannot pollute the result; omit for a fresh database. UTC, literal `Z`. |
| `moduller` | yes | `modul_id` → one scenario name or a list. `temiz` cannot be combined with another. |

**Scenario vocabulary and what each asserts** (everything through contract ⑤):

| Name | Passes when |
|---|---|
| `temiz` | the module has **no** episode of any type (since `bas`) |
| `gevsek_klemens`, `asiri_yuk`, `faz_dengesizligi`, `nem_yukselmesi`, `ark_olayi`, `sensor_arizasi`, `modul_saglik` | an episode whose `tip` is one the label format accepts for that scenario (`etiket.SENARYO_TIPLERI`). When it carries `kanit.kare_id`, `GET /termal/kare/{id}` must return 768 numbers — the frame decodes end to end |
| `besleme_kaybi` | a `modul_saglik` episode with `kanit.neden = besleme`, or the module detail reporting `besleme = yedek` |
| `sinyal_zayif` / `saat_kaymasi` / `sessiz` | a `modul_saglik` episode with `kanit.neden` = `sinyal` / `saat_kaymasi` / `sessizlik` |
| `seviye_gecisi` | one of the module's episodes has a `seviye` transition between two non-normal severities (e.g. `izle → uyari`), in its own journal **and** reachable through `GET /gecisler?sonra=<id-1>` |

Always run, regardless of input: `/saglik` answers with `durum = calisiyor`,
at least one scan cursor exists and is no further behind than
`--azami-imlec-gecikme-sn`, `veri_gecikmesi` is present, and `/gecisler`
answers. Required coverage for the phase — one clean module, one loose
terminal, one power loss, one severity transition, and the clean module having
opened nothing — is the first four rows of the table plus the global checks.

Scenario data comes from track A's simulator. The same checks pass on this
package's own fixture set (`tests/test_duman.py::FIKSTUR_SENARYOLARI` is a
complete example input), which is how they are tested here.

---

## Contract mismatches found on `feature/track-a`

Read-only inspection of PR #1, as found before the integration phase. Kept for
the record; the status of each is noted.

**1. `anomali.schema.json` has not caught up with the amendment in section 7.2 of
the İZ B record.** The schema still lists `zaman` as required and sets
`additionalProperties: false`. Section 7.2 replaces `zaman` with the pair
`ilk_gorulme` / `son_gorulme` and adds `maks_seviye`, and records that the lead
approved it. As things stand, a correctly-formed track B anomaly record **fails
validation** against the track A schema on two counts: a missing required
property, and three additional ones. Track B implements the amended shape,
because the decision record is authoritative for this track. The schema needs the
corresponding edit before the contract check can pass on both sides.

**2. (Resolved by the integration decisions: `gridup.modul_durum`, one row per
packet. Track B reads it — item 8.) `modul_durum.besleme` and `modul_durum.sinyal` are accepted and then
discarded.** Contract ② declares both, `modul_paketi.schema.json` requires them,
and `toplama/toplama/kayit.py` persists only `yazilim_surumu` and `son_gorulme`
into `gridup.modul`. There is no table holding either field, current or
historical. Consequence for this layer: scenario 7 is "besleme kaybı, sinyal
zayıflığı, saat kayması", and only the third is detectable. `modul_saglik` is
therefore implemented on silence and clock drift alone. Loss of supply — which
section 7.3 describes as the entire reason the module carries a backup store — is
not visible to the detector. Wiring it up is a few lines in
`katman0_sensor._modul_sagligi` once somewhere to read it from exists.

**3. (Still true on track A's side; the index now lives in `100_analiz.sql`.) No index supports the scan loop's main query.** `gridup.olcum` is indexed on
`(modul_id, olcum_tipi, zaman)` and on `zaman DESC`; the scan loop's range query
is on `alindi_zaman`, which track A never queries by. Without an index every turn
is a sequential scan of the partition. Track B's migration adds
`olcum_alindi_zaman_idx` — additive, changing no column and no constraint, so it
is safe on a shared schema.

**4. Item 3 of section 11.1 is now implemented, on track B's side.** The
monotonic sequence and time index the alarm service needs in order not to miss an
episode are `gridup.anomali.sira` (drawn from the same sequence as `id`, so their
orderings cannot disagree) and `anomali_son_gorulme_idx`.

**5. (Found during this review's local setup, not on track A's branch text
itself — recorded here because it fits this section, not because a code
change was made anywhere shared.) The exported `toplama/migrations/003_termal.sql`
this checkout's own setup instructions point at (`git archive
origin/feature/track-a toplama/migrations sozlesmeler`) still declares
`termal_kare.piksel_verisi JSONB`, while this file's own §11 ("Binary frame
(11)") and `fikstur.py`/`api.py` have always treated it as `bytea` (int16 LE).
A local, uncommitted patch to the exported copy (never to the shared
migration itself) was needed to run this delivery's test suite end to end
against a real database. Whether track A's actual current schema already
has the bytea column and this export is simply stale, or whether the
migration genuinely still says jsonb, was not otherwise determined — flagged
for track A to confirm, not fixed here.**

Nothing else diverged. Column names, types, enum values, the `[sutun, satir]`
pixel order, the 768-value row-major frame layout and the `kalite`/`deger`
relationship all match what this layer was built against.

**Since the integration phase** the schema and vocabularies are no longer
restated here at all, so this list cannot grow the same way: a divergence now
shows up as `tests/test_sozlesme.py` failing against track A's own files.

---

## Post-review corrections (D1–D5)

A technical review of PR #3 after it merged found real bugs and a design gap
in severity handling. This section records what changed, why, and — for D4 —
every threshold this package uses, its numeric value, where it comes from,
and where it is read. It does not touch `docs/izb-karar-kaydi.md`; these are
implementation corrections downstream of that record, not amendments to it.

### D1 — multi-time-scale detection

The original detection window (`PencereAyari.tespit_sn`, 6 hours) is right for
a sudden rise and structurally cannot see a fault that grows too slowly to
accumulate `Katman2Ayari.asgari_delta` worth of rise inside any given 6-hour
slice — a terminal drifting 45 → 60 °C over 10 days moves about 0.06 °C in any
six hours of that, which never clears the gate no matter how far the fault has
actually come by day 10.

A second, independent evaluation now runs alongside the fast one:
`Katman2YavasAyari` / `dedektor.katman2_taban._yavas_isinma`. It reads
`Katman2YavasAyari.pencere_sn` (21 days by default) of **daily SQL
aggregates** (`PencereGetirici._yavas_ozetler`, `date_trunc('day', ...)` +
`avg`/`max` — never raw samples pulled into Python), computes normalized
heating `(hot spot − ambient) / current^n` per day, fits a **Theil-Sen**
(median-of-pairwise-slopes) trend across those daily points — robust to a
single corrupted day-bucket, unlike an ordinary least-squares fit — and
compares the module's CURRENT normalized-heating level against ITS OWN level
from the EARLIEST few qualifying daily buckets in that same window.

**Why not a sliding baseline, and why an early-anchored one instead — the
crux of D1.** The existing 14-day sliding median/MAD
(`PencereAyari.taban_sn`/`taban_bosluk_sn`) is exactly the trap the slow path
exists to avoid: fed a 10-day linear drift, it absorbs the drift as the new
normal (verified as a regression test,
`tests/test_zaman_olcekleri.py::test_yavas_isinma_taban_cizgisi_yutulur` —
median ends up dragged toward the drifted value, robust z stays under the
fast path's own `izle` threshold). The slow path's reference is instead the
median of the OLDEST few qualifying buckets inside the SAME window being
evaluated, recomputed fresh every time rather than carried and updated turn
to turn. It cannot be poisoned by a fault developing WITHIN the window because
it never slides forward to re-absorb one. A fault already fully established
before the window even opens is a real, acknowledged limitation of any
window-based reference — not unique to this one — which is why the window
defaults to 21 days rather than the 14-day floor D1 asked for: more runway for
the early reference to predate a real fault's onset.

Missing ambient, missing/insufficient current data, or layer 0 having vetoed
either channel: the slow path is skipped for that module that turn, silently
— no default substituted (see D3 for why that specific failure mode matters).

**Performance.** An unbounded per-turn re-run of this query measurably broke
the T5 budget (see T5 below) — recomputing a days-scale trend every 30 s buys
nothing, so `PencereGetirici` now caches each module's slow-path result in
process memory and only re-queries after `Katman2YavasAyari.yenileme_sn` (1
hour default) has passed for that module.

### D2 — severity is an action, not a forecast

`izle` = keep watching, `uyari` = plan maintenance, `kritik` = act now.
Severity must read off the PRESENT, load-normalized condition; a forecast may
only appear as *text* inside `gerekce`, never as the reason a `Bulgu` carries
the severity it does.

- **Layer 2's own-history deviation** (`_sapma`, robust z) is capped at
  `izle` (`skor.esikle_tavanli`) — being unusual for ITS OWN history is not,
  alone, grounds for more. `Katman2Ayari.z_uyari`/`z_kritik` are kept to
  shape the score curve within the capped band, not removed.
- **Layer 2's trend** (`_egilim`, the OLS slope) no longer produces its own
  finding or severity at all. It survives as `_egilim_bilgisi`: text folded
  into an already-firing magnitude finding's `gerekce`, gated by the same
  `asgari_delta`/`asgari_egilim_ornek` as before. `egilim_izle` is now purely
  the "worth mentioning" floor; `egilim_uyari`/`egilim_kritik` only word the
  sentence and play no part in `esikle`.
- **Excess heating over ambient, load-normalized** (layer 3's
  `_akim_sicaklik`, and the slow path above) is mapped onto FIST 4-13's own
  bands: 1–10 K not reported, 11–20 → `izle`, 21–40 → `uyari`, >40 → `kritik`.
- **Difference vs a similar component** (phase-to-phase, pixel-vs-frame,
  module-vs-peers) is the same FIST 4-13 category, bands 1–3 K not reported,
  4–15 K → `uyari`, >15 K → `kritik`. Applied where the units allow it
  (Kelvin comparisons); phase-to-phase stays a current fraction and is NOT
  force-converted — see the threshold table below for the honest sourcing on
  each.
- **A configurable persistence delay** (`OlayAyari.bekleme_sn`, `olay.py`)
  now gates OPENING a new episode: a qualifying condition must recur across
  MEASUREMENT-time-advancing turns for `bekleme_sn` (15 minutes default,
  measured against detector/turn time — see `OlayDeposu._acilmaya_hazir`'s
  docstring for why turn time and not measurement time) before a fresh
  episode opens; an already-open episode is unaffected. The arc
  (`OlayAyari.bekleme_muaf`) is exempt and opens immediately, unchanged —
  the TVOC-2 is SIL-2 and has already decided.

### D3 — two fixes

1. **Layer 3's current-vs-temperature check** (`_akim_sicaklik`) used to
   credit a missing ambient channel with 0 °C, which (combined with an
   extreme current ratio) could report a critical `akim_sicaklik_sapmasi` for
   a module carrying nothing but a pure overload with no ambient sensor.
   It now returns no finding at all when the ambient channel is absent or
   layer-0-vetoed. Acceptance test A6
   (`tests/test_zaman_olcekleri.py::test_a6_...`) reproduces the scenario.
2. **Layer 0's physical-range check** used to run after the minimum-sample
   early return, so a channel with fewer than `Katman0Ayari.asgari_ornek`
   samples — one of them physically impossible — was waved through as merely
   "unjudged". The range check now runs first, unconditionally.
   `tests/test_katmanlar.py::test_kanal_sagligi_aralik_disi_az_ornekle`.

### D5 — new labelled scenarios

`senaryolar.py` gained one slow-developing loose-terminal scenario
(`senaryo_08_gevsek_klemens_yavas`, days-scale, current and ambient steady —
the same fault as scenario 1, driven by `Uretec.uret`'s new `yavas_bozucu`
hook rather than the fast `bozucu` one) and two hard negatives: ambient
rising over days with the surface following it (load-normalized heating
stays flat), and a sustained ~40% load increase over days with the
temperature rise consistent with I² (`asiri_yuk`'s own fault, not a loose
terminal — must never surface as `akim_sicaklik_sapmasi`). These are the
labelled/regression set (section 2.7); metrics from it are reported as
"labelled set", never "blind test" — see the [Kör test protokolü](#kör-test-protokolü)
section for the difference.

### D4 — threshold traceability

Every threshold, window and exponent in `ayar.py`, its default, its basis,
and where it is used. Basis is one of: **FIST 4-13** (U.S. Bureau of
Reclamation, infrared inspection of electrical equipment), **vendor
example** (a manufacturer's published model, not a standard), or
**engineering default, unverified** (a deliberate, documented choice with no
external citation — never invented as one).

**`VeritabaniAyari`**

| Field | Value | Basis | Used in |
|---|---|---|---|
| `sorgu_zaman_asimi_ms` | 30000 | engineering default, unverified | every DB cursor |

**`TaramaAyari` (K1, the scan loop)**

| Field | Value | Basis | Used in |
|---|---|---|---|
| `periyot_sn` | 30 s | engineering default — set from T5's own measurement, not a spec value | `tarama.py` |
| `emniyet_payi_sn` | 1 s | engineering default, unverified | `tarama.py._aralik_sonu` |
| `ilk_imlec_geri_sn` | 3600 s | engineering default, unverified | cold-start cursor |
| `azami_aralik_sn` | 6 h | engineering default, unverified | catch-up cap |

**`PencereAyari` (evaluation windows)**

| Field | Value | Basis | Used in |
|---|---|---|---|
| `tespit_sn` (fast detection window) | 6 h | decision record's worked example (section 5) | all four layers |
| `taban_sn` (fast baseline window) | 14 days | engineering default — "far longer than the detection window" per the poisoning defence, section 5 | `katman2_taban._sapma` |
| `taban_bosluk_sn` | 6 h | engineering default, unverified | poisoning defence part 2 |
| `asgari_taban_ornek` | 20 | engineering default, unverified | layer 2 cold-start gate |
| `komsu_sn` | 6 h | engineering default, unverified | layer 3 module-vs-module |
| `temsil_ornek` | 5 | engineering default, unverified | "representative value" median everywhere |

**`Katman0Ayari` (sensor health)**

| Field | Value | Basis | Used in |
|---|---|---|---|
| `kalite_orani` | 0.5 | engineering default, unverified | quality-flag test |
| `asgari_ornek` | 6 | engineering default, unverified | minimum-sample gate |
| `donuk_ardisik` | 12 | engineering default — "two minutes at the contract's 10 s cadence" | frozen-sensor test |
| `donuk_tolerans` | 1e-6 | sensor quantisation floor, unverified | frozen-sensor test |
| `sessizlik_sn` | 900 s | engineering default, unverified | silence finding |
| `saat_kaymasi_sn` | 120 s | engineering default, unverified | clock-drift finding |
| `ileri_tarih_tolerans_sn` | 5 s | NTP-scatter allowance, unverified | future-dated test |
| `besleme_yedek_ardisik` | 2 | engineering default, unverified | backup-power finding |
| `sinyal_zayif_dbm` | −100 dBm | LoRa/NB-IoT link-budget rule of thumb, unverified as a citation | weak-signal finding |
| severities (`kalite`/`donuk`/`aralik_disi`/`sessizlik`/`besleme` = `uyari`; `saat_kaymasi`/`sinyal` = `izle`) | — | engineering default — "a sensor fault is a maintenance ticket, not a grid emergency" | layer 0 |

**`Katman1Ayari` (absolute limits) — audited, not changed by D2**

| Field | Value | Basis | Used in |
|---|---|---|---|
| `termal_izle`/`uyari`/`kritik` | 70 / 90 / 130 °C | decision record cites TEDAS spec + material limits; 130 °C is the record's own worked-scenario insulation limit — **not independently verified against the TEDAS document by this review** | layer 1 hot-spot |
| `ortam_izle`/`uyari`/`kritik` | 45 / 55 / 65 °C | engineering default, unverified | layer 1 ambient |
| `nem_izle`/`uyari`/`kritik` | 75 / 85 / 95 % | engineering default (condensation risk), unverified | layer 1 humidity |
| `faz_izle`/`uyari`/`kritik` | 10 / 20 / 30 % | NEMA-style imbalance percentage, unverified as a specific citation | layer 1 phase |
| `faz_asgari_akim` | 20 A | engineering default, unverified | phase-imbalance noise floor |
| `ark_esik` | 0.5 | pass-through of the TVOC-2's own certified decision, not this system's threshold | arc finding |

**`Katman2Ayari` (fast baseline deviation)**

| Field | Value | Basis | Used in |
|---|---|---|---|
| `z_izle`/`z_uyari`/`z_kritik` | 3.5 / 6.0 / 10.0 | robust-z convention (comparable to a standard-deviation count); **D2: capped at `izle`, `uyari`/`kritik` now only shape the score curve** | `_sapma` |
| `asgari_mad` | 0.3 | ~1 sensor quantisation step, unverified | MAD floor |
| `egilim_izle`/`uyari`/`kritik` | 0.5 / 1.5 / 4.0 °C/h | engineering default, unverified; **D2: no longer set severity — `izle` is a "worth mentioning" floor, `uyari`/`kritik` only word the sentence** | `_egilim_bilgisi` |
| `asgari_delta` | 5.0 | engineering default, unverified | trend total-rise gate |
| `asgari_egilim_ornek` | 8 | engineering default, unverified | trend sample-count gate |

**`Katman2YavasAyari` (slow path, new in D1)**

| Field | Value | Basis | Used in |
|---|---|---|---|
| `pencere_sn` | 21 days | D1 asked for "at least 14 days"; 21 chosen for early-reference runway, engineering default | slow window |
| `kova_sn` | 24 h | engineering default — thermal lag itself is hours long, an hourly bucket mostly re-measures it | SQL bucket width |
| `asgari_akim` | 5 A | mirrors `Katman3Ayari.akim_asgari` | normalized-heating noise floor |
| `yuk_ustel` (n) | 2 | I²R, physics-derived | normalization exponent |
| `asgari_kova` | 10 | engineering default, unverified | slow-path cold-start gate |
| `temsil_kova` | 3 | mirrors `PencereAyari.temsil_ornek` | robust current/reference level |
| `asiri_isinma_izle`/`uyari`/`kritik` | 11 / 21 / 40 °C | **FIST 4-13**, same bands as `Katman3Ayari.aciklanamayan_*` | slow-path severity |
| `yenileme_sn` | 3600 s | engineering default — see T5 below for the measurement that set it | `PencereGetirici`'s slow-path cache |

Note on `yuk_ustel`: ABB publishes a vendor thermal model using **n = 1.6**
for some busbar/connector geometries — a vendor example, not a standard, and
not adopted here. 2 (the I²R physics model, also used by layer 3) is the
default.

**`Katman3Ayari` (relationships)**

| Field | Value | Basis | Used in |
|---|---|---|---|
| `sicaklik_artis_esigi` | 10 °C | aligned to FIST 4-13's own "not reported" floor below | worth-checking gate |
| `aciklanamayan_izle`/`uyari`/`kritik` | 11 / 21 / 40 °C | **FIST 4-13** ("excess heating over ambient") — corrected in D2 from the previous unsourced 8/15/30 | `_akim_sicaklik` |
| `akim_asgari` | 5 A | engineering default, unverified | I² ratio noise floor |
| `faz_sapma_izle`/`uyari`/`kritik` | 0.08 / 0.15 / 0.25 (fraction) | **engineering default, unverified — deliberately NOT converted to FIST's Kelvin bands**: this is a current-imbalance fraction, not a temperature difference, and forcing a Kelvin citation onto it would misrepresent the source | `_faz_faz` |
| `notr_orani` | 0.20 | engineering default, unverified | neutral-current corroboration |
| `piksel_ayrisma_izle`/`uyari`/`kritik` | 6 / 8 / 15 °C | **FIST 4-13 shape** (1–3 not reported / 4–15 uyari / >15 kritik), `izle`/`uyari` raised above FIST's literal 4 K specifically for noise-floor robustness — verified against this project's own noisy-healthy fixture during validation; `kritik` at FIST's literal 15 K. Corrected from the previous unsourced 8/15/25 | `_komsu_piksel` |
| `piksel_kararlilik_orani` | 0.6 | engineering default, unverified | hot-pixel stability gate |
| `modul_ayrisma_izle`/`uyari`/`kritik` | 6 / 8 / 15 °C | same as `piksel_ayrisma_*` above, same reasoning | `_modul_modul` |
| `asgari_komsu` | 2 | engineering default, unverified | peer-count gate |
| `komsu_kapsami` | "saha" | operational choice, not a threshold | peer scope |
| `ortak_hareket_delta` | 3.0 °C | engineering default, unverified | common-movement suppression |
| `ortak_hareket_orani` | 0.6 | engineering default, unverified | common-movement suppression |

**`OlayAyari` (episode lifecycle)**

| Field | Value | Basis | Used in |
|---|---|---|---|
| `histerezis_sn` | 30 min | decision record, section 6.5 ("about 30 minutes") | closing hysteresis |
| `bekleme_sn` (new in D2) | 15 min | engineering default — comfortably above the 30 s scan period, comfortably below the hours-to-weeks fault timescales this system targets | opening delay-on |
| `bekleme_muaf` | `{ark}` | section 3.5 — the TVOC-2 is SIL-2 and has already decided | delay-on exemption |

**`ApiAyari`** — no detection thresholds; page sizes and pool bounds are
operational, not physical, and not included above.

---

## T5 — ölçeklenebilirlik raporu

```
python -m analiz.yuk --moduller 10,50,100 --tur 10
```

**Donanım:** 4 fiziksel / 4 mantıksal çekirdek, 16.5 GB RAM,
Intel(R) Xeon(R) Processor @ 2.10GHz, cgroup CPU sınırı yok.
PostgreSQL 16 aynı makinede.

Scan period **30 s** (the default), 15 days of baseline history per module,
detection window sampled at the contract's 10 s cadence, 15% of each fleet
carrying an injected fault.

```
 modül  veri satırı   tur ort      p95  satır/tur  çekirdek-sn  ms/modül    bellek  doluluk  mod/çekirdek  yetişiyor
    10      311,610    2.029s   2.705s        270         2.08       208    164.0M       9%           144       evet
    50    1,558,050   11.177s  14.541s       1350        11.45       229    464.5M      48%           131       evet
   100    3,116,100   19.449s  22.687s       2700        19.89       199    758.6M      76%           151       evet
```

`çekirdek-sn` is CPU core-seconds per turn, **detector process plus PostgreSQL
backends**. The queries run in separate server processes and their cost never
appears in the detector's own `cpu_times()`, so a CPU figure that counted only
the Python side would be roughly half the real bill.

### Sonuç: 100 modül 30 saniyelik periyotta yetişiyor

p95 turn duration 22.7 s against a 30 s period — **76% duty, with headroom but
not a lot of it.** Section 7.7's 100-module target is met on default settings.

At the previous 10 s default the same fleet did not keep up: 19.9 core-seconds
of work per turn against a 10 s budget is ~199% duty, and the detector falls
permanently behind. That is why the default moved (see `ayar.TaramaAyari`).

### Kapasite: çekirdek başına ~151 modül

Stated per core rather than as a duration, because a turn duration is only true
of the machine it was measured on:

| | |
|---|---|
| modül başına çekirdek zamanı | **199 ms** (10/50/100 modülde 208 / 229 / 199 ms) |
| 30 sn periyotta çekirdek başına kapasite | **~151 modül** |
| 10 sn periyotta çekirdek başına kapasite | ~50 modül |

Per-module cost is flat across a tenfold range in fleet size (208 → 229 → 199
ms), which is what the design predicts: the work is a per-module window fetch
and a per-module baseline, and neither depends on how many other modules exist.
That flatness is what makes the capacity figure usable — it extrapolates because
the underlying cost does not change with scale.

Carrying it to other hardware is one ratio: a core 1.5× faster carries ~1.5×
as many modules.

### Tek çekirdek — varsayım değil, ölçüm

The previous run showed process CPU close to wall time, which *suggests* serial
work but does not establish it: the detector's process CPU excludes the
PostgreSQL backends it waits on, so a turn that was half Python and half SQL on
two different cores would show the same ratio. So the harness measures
system-wide CPU across the window instead.

```
Ortalama meşgul çekirdek: 1.16 / 4   (sistem geneli CPU ÷ duvar saati)
Tur içi paralellik:       1.02×      (19.89 çekirdek-sn ÷ 19.45 sn duvar saati)
```

**1.02× means essentially nothing overlaps.** The detector is one process, one
thread, evaluating modules in a loop; while a query runs, Python waits. Three of
the four cores on this box are idle during a turn.

The consequence for scaling advice is the point: **adding cores does not shorten
a turn.** A 16-core machine runs this at the same speed as a 4-core one. What
buys capacity is a longer period, or more detector processes.

### Nerede gidiyor

At 100 modules, ~6.7 s of the 19.4 s is SQL and the remaining ~12.7 s is Python:

| | ms/tur |
|---|---|
| pencere: ölçüm serileri | 2417 |
| taban çizgisi (medyan + MAD) | 2309 |
| pencere: son ölçüm | 1613 |
| pencere: termal özet | 353 |
| olay yazımı (33 çağrı) | 27 |
| tur aralık sorgusu | 4.8 |

The Python side is dominated by materialising the evaluation window: 6 hours at
10 s across 9 channels is ~19,000 samples per module, and each becomes a `Nokta`.
The detector layers themselves are cheap by comparison.

**İndeks etkisi.** The range query that opens every turn — a sequential scan over
3.1 million rows without it — costs **4.8 ms** at 100 modules. That is
`olcum_alindi_zaman_idx` doing its job; it is the index track A's migrations do
not have, because track A never queries by `alindi_zaman` (mismatch 3 above).

### Sınırı ötelemenin yolları

Not implemented — this delivery measures, it does not tune. In rough order of
return:

1. **Shard modules across processes.** The measured 1.02× says this is the only
   lever that uses the hardware already present. The cursor is per named cursor
   and the layers are pure functions of a window, so two detectors on disjoint
   module sets share nothing but the tables. Four processes on this box would
   carry ~600 modules at 30 s.
2. **Raise the period further.** Configuration (`tarama.periyot_sn`), and
   section 3.5 already argues the events we detect run on scales of minutes to
   hours. 60 s doubles capacity to ~300 modules per core.
3. **Stop building `Nokta` objects for the whole window.** The layers consume
   medians, slopes and endpoints; most of that could be computed in SQL, as the
   baseline already is. This is the largest single cost.
4. **Drop the `son ölçüm` query** (1.6 s/turn) in favour of `modul.son_gorulme`,
   which the contract maintains for exactly this question. Track B reads from
   `olcum` instead because `son_gorulme` only exists if track A's collector wrote
   it, and track B has to run standalone — so this one is a trade, not a free win.

---

## Düzeltme — P1'in kazanılan süre notu yanlıştı

The first delivery's README said, under "Extension points", that lead time could
not be computed because it "needs the injection's true onset — precisely what a
blind set withholds".

**That was wrong.** A blind set withholds the labels *while the detector runs*,
not while the evaluation runs. Section 4.4's protocol is explicit: the output is
frozen at step 3, the key is opened at step 4, and every metric is computed then
with the labels in hand. Lead time is computable and is now computed —
`kortest.SenaryoSonucu.kazanilan_sure_sn`.

What the earlier note got right, buried under the wrong conclusion, is that the
onset and critical times have to **come from the generator**, because nothing in
our database knows when an injected fault became critical. That is why
`kritik_esik` is a required part of the label format rather than something the
tool infers.

Measured on the labelled fixture set, with the loop replayed turn by turn: median
lead time **+4.0 hours**, from +5.8 h (overload) down to −0.1 h for the arc. The
negative one is correct and worth keeping visible — an arc is instantaneous, and
no monitoring system can warn ahead of it. The TVOC-2 trips in under a
millisecond and we relay the record.

---

## Conventions

Turkish for identifiers that mirror the contract (`olcum_tipi`, `seviye`, `tip`,
`kalite`, `durum`) because those values are on the wire, and for module names to
match the rest of the repository. English for comments. Turkish for `gerekce`,
because an operator reads it.

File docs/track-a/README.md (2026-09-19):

# İZ A — Veri Yolu ve Saha Tarafı · Donanım Tasarım Dokümantasyonu

Bu klasör, Grid Up Hackathon'unda **İZ A**'nın donanım tarafındaki teslimat karşılığıdır:
**T1** (kabin içi modül tasarımı, bileşen seçimi) ve **T2** (elektronik tasarım dokümantasyonu:
kart yapısı, giriş-çıkış bağlantıları, bağlantı şemaları, temel bileşenler).

> **Tasarım dokümanıdır, ürün değildir.** Hackathon kapsamında fiziksel donanım üretilmez ve
> satın alınmaz (karar kaydı §1.4). Bu belgeler modülün nasıl inşa edileceğini tanımlar; veri
> sentetik olarak üretilir, yazılım tarafı gerçek ve çalışır durumdadır.

---

## Dokümanlar

| # | Doküman | İçerik | Karşıladığı teslimat |
|---|---|---|---|
| 1 | [Modül blok şeması](01-blok-sema.md) | Sensörler, mikrodenetleyici, radyo, besleme, yedek depo; arayüzler | T1, T2 |
| 2 | [Bileşen listesi (BOM) ve birim maliyet](02-bom.md) | Parça, adet, işlev, yaklaşık fiyat, modül birim maliyeti + [kart yerleşimi](02-pcb-yerlesimi.svg) | T1, T2 · değerlendirme kriteri 8 |
| 3 | [Bağlantı ve pinout tablosu](03-pinout.md) | Hangi bileşen hangi arayüzle bağlı (I²C, SPI/UART, RS-485, besleme) + [bağlantı şeması](03-baglanti-semasi.svg) | T2 |
| 4 | [Mekanik yerleşim ve görüş hattı](04-mekanik-yerlesim.md) | Kutu ölçüsü, panodaki konum, kadraj krokisi ([yerleşim](04-yerlesim-krokisi.svg) · [kutu](04-kutu-krokisi.svg)), sabitleme | T1, T2 |
| 5 | [Saha koşulları gerekçesi](05-saha-kosullari.md) | Sıcaklık, nem, IP, manyetik alan, kısa devre darbesi, yabancı cisim | T1, T2 · kriter 3 |
| 6 | [Montaj prosedürü](06-montaj-proseduru.md) | 7 adım, süre, "kesinti yok" gerekçesi + [adım akışı](09-montaj-adimlari.svg) | T1 · kriter 3 |
| 7 | [Modül yazılım akış diyagramı](07-yazilim-akis.md) | Uyan → oku → özetle → paketle → gönder; kod: `/modul-sim` (Python, test edilmiş) + [`/firmware`](../../firmware/README.md) (ESP32-S3 C++, derlenir) | T3 (modül kısmı) |
| 8 | [**Sistem mimarisi / uçtan uca veri akışı**](08-sistem-mimarisi.svg) | Pano içi → saha gateway → on-prem sunucu: üç izin gerçek servisleri, sözleşme ①–⑤ şeridi, ortak sözlük, hedef/gerçek durum notu | Demo beklentisi "sistem mimarisi", T4/T6/T7 bağlamı · kriter 4 |
| — | [**Kaynakça**](KAYNAKCA.md) | Dokümanlarda geçen her dış teknik değerin kaynağı, doküman no/sayfa/URL ve **doğrulama durumu** (okundu / özet / atıf / seçim) | — |

---

## Çizim kaynakları (elle SVG yok)

- **Fusion 360 zinciri** [`cad/`](cad/README.md): `02-pcb-yerlesimi`, `04-kutu-krokisi`, `04-yerlesim-krokisi` —
  modeller (`.f3d` / `.step`), model script'leri, projeksiyon/kesit üreteci ve SVG kompozisyon script'leri.
- **KiCad zinciri** [`eda/`](eda/README.md): `03-baglanti-semasi` — `gen_sch.py` → `.kicad_sch` → `kicad-cli` ERC +
  netlist (`verify_netlist.py`, 103 kontrol) → SVG (`build.py`).
- **Mimari üreteci** [`eda/gen_mimari.py`](eda/gen_mimari.py): `08-sistem-mimarisi` — kutu içerikleri repodaki servislerden,
  PIL ile metin taşma denetimi.
- `09-montaj-adimlari` elle çizilmiş tek SVG'dir (06 §6.1 tablosuna bağlı).

Elle düzenleme yerine script'i değiştirip yeniden üretin.

---

## İzlenebilirlik — her doküman hangi karara dayanıyor

Bu tablo, "bu doküman neden böyle yazılmış" sorusunun cevabıdır. Atıflar
[`gridup-proje-karar-kaydi.md`](../../gridup-proje-karar-kaydi.md) bölümlerinedir.

| Doküman | Dayandığı kararlar | Bağlayıcı şartlar |
|---|---|---|
| 1. Blok şema | §7.1 ölçüm kümesi · §7.3 besleme · §7.4 haberleşme | **Genişleme payı** ifadesi (§7.1 satır 237) |
| 2. BOM | §7.5 kutu ve bileşen sınıfı · §7.1 kapsama | Bileşenler −40…+85 °C endüstriyel sınıf (§7.5 satır 318) |
| 3. Pinout | §7.1 (akım: CT veya analizör) · §7.4 | Analizör varsa akım için ek sensör gerekmez |
| 4. Mekanik yerleşim | §7.5 kutu/konum/sabitleme · §7.1 kapsama hesabı | **Sabitleme metni** (§7.5 satır 331) · **IR pencere** (§7.5 satır 323) |
| 5. Saha koşulları | §2.3 TEDAŞ Tablo 1 · §2.2 kısa devre dayanımı · §7.5 | Şartnameye atıflı olmak zorunda |
| 6. Montaj prosedürü | §7.5 satır 343–351 | 7 adım birebir, kesinti yok, ~15–20 dk |
| 7. Yazılım akışı | §7.2 örnekleme · §7.4 veri politikası | Diyagram **koddan** türetilir, tahminle değil |

### Karar kaydının birebir şart koştuğu ifadeler (atlanamaz)

1. **Genişleme payı** (§7.1 satır 237): *"modül ek ölçüm kanalları için genişletilebilir arayüz taşır"*
   — PD/akustik fark katmanı ertelendiği için zorunlu.
2. **Enerji hasadı varyantı** (§7.3 satır 284): yardımcı besleme devresi olmayan sahalar için
   alternatif olarak konumlandırılacak.
3. **Sabitleme metni** (§7.5 satır 331–333): yeni delik açılmadan; mıknatıs yalnız konumlandırma için.
4. **Kızılötesi pencere** (§7.5 satır 323): cam/plastik IR'yi geçirmez → sensör kutunun yüzeyinde,
   dışa bakar halde.
5. **Mıknatıs + CT uyarısı** (§7.5 satır 337): güçlü mıknatıs akım trafolarının yakınına konmaz.
6. **Örnekleme tablosu** (§7.2): akım 1–5 sn (10 sn ort.), termal özet 10–30 sn, tam kare yalnız
   anomali anında, ortam/nem 30–60 sn, ark olay bazlı. **Entegrasyon kararıyla (17 Eyl, madde 2)
   değişti:** paket ve termal 30 sn, tam kare her pakette; karar kaydı henüz güncellenmedi, kod ve
   [7. doküman §7.2–7.3](07-yazilim-akis.md) yeni değeri taşır.
7. **Ark tespiti iddiası yok** (§7.1 satır 230): ark algılamayı biz yapmıyoruz; TVOC-2 kaydını
   okuyoruz. "Tespit" diye yazmak yanlış beyan olur.

---

## Ortak sözlüklere bağlılık

Bileşen adları, ölçüm tipleri, birimler ve zaman biçimi
[`/sozlesmeler`](../../sozlesmeler) altındaki sözleşmelerle aynı olmak zorundadır:

- `olcum_tipi`: `ortam_sicaklik`, `nem`, `akim_l1`, `akim_l2`, `akim_l3`, `akim_notr`,
  `termal_maks`, `termal_ort`, `ark_olay`
- `kalite`: `iyi`, `supheli`, `yok`
- `modul_durum.besleme`: `sebeke` | `yedek`
- `modul_id`: `{saha}-{pano}-{modul}` → örn. `TR041-P01-M1`
- Zaman: UTC, ISO 8601 (`YYYY-MM-DDTHH:MM:SSZ`)
- Birimler: DB'de gerçek birimde ondalıklı (°C, A, %)

Dokümanlarda bir modülden söz edilirken bu kimlik biçimi kullanılır; hiyerarşi (saha → pano →
modül) kimliğin içinde taşındığı için hem izleme arayüzündeki ağaç hem de 100 modüllük yük
testindeki gruplama kendiliğinden oluşur.

**Sözleşme değişikliği bu klasörün yetkisinde değildir.** Bir değişiklik gerekiyorsa takım
liderine iletilir ve üç ize birden duyurulur (§0 değişiklik kuralı).

---

## Termal dizi seçiminin karar kaydıyla bağı

Termal sensör olarak **MLX90640 (110°×75° görüş açılı, BAA kodu)** seçilmiştir.

- §7.1 satır 232: *"Pano derinliği 450 mm; kapak içine konan sensör hedefe ~40 cm mesafededir.
  Geniş açılı versiyon bu mesafeden kabaca **114 × 61 cm** görür."* — kaydın kendi hesabı 400 mm
  varsayımıyla tutarlıdır (40 cm'de tan hesabı 1143 × 614 mm verir).
- **Gerçek model bunu kesinleştirdi:** Fusion 360 montajında kutu 50 mm + klips 5 mm olduğundan
  sensör → montaj plakası **377 mm**'dir. NH ayırıcı ön yüzü ise baralar üzerinde durur ve öne
  çıkar: plakadan 221,5 mm (mesnet izolatörü 50 mm + bara grubu 30 mm + NH derinliği 141,5 mm;
  kaynaklar [4. doküman §4.3](04-mekanik-yerlesim.md)'te) → sensör → NH **155,5 mm**. Buna göre kapsama
  **1077 × 579 mm** (plaka) ve **444 × 239 mm** (NH) olur.
- MLX90640'ın geniş açılı varyantı tam olarak **110° × 75°**'dir (Melexis datasheet, device
  marking: `A` = 110°, `B` = 55°).

Yani karar kaydındaki hesap, bu parçanın geniş açılı varyantını zaten varsaymıştır. Kayıt mesafeyi
*"~40 cm"* diye **yaklaşık** vermişti; model kesin ölçüyü verdi ve kapsama buna göre küçüldü.
**Çelişki yok, sözleşme değişikliği yok** — parça seçimi (110°×75°) **değişmemiştir**: dar açılı
varyant (55°×35°) 377 mm'de yalnızca ~39 × 24 cm görür ve klemens sırasını hiç kapsamaz.

**Kapsama sınırı (dürüstçe):** Pano 160 × 150 cm olduğundan tek sensör tamamını görmez. Plaka
düzleminde kritik genişliğin **%90**'ını, NH gibi öne çıkan yüzeylerde ise yalnızca **%37**'sini
kapsar. Kritik bölgenin tamamını kaplamak için plaka düzleminde **2**, NH düzleminde **9 modül**
gerekir (§7.1 satır 232 ve §7.5 satır 339). Karar kaydının *"1 modül baz senaryo"* ifadesi, tek
modülün **en kritik noktaya hizalanması** olarak uygulanır.

---

## Terimler

- **Modül:** panonun içine yerleştirilen, bu dokümanlarda tanımlanan elektronik kutu.
- **Saha gateway'i:** trafo binası içinde, modüllerden veriyi toplayıp merkeze ileten ara cihaz.
  Bu dokümanların kapsamı **dışındadır** (İZ C).
- **Merkez / on-prem sunucu:** şirket içi sunucu; toplama servisi, anomali motoru, arayüz,
  Modbus sunucusu ve alarm servisi burada çalışır (İZ B ve İZ C).
- **Tedarikçi / distribütör adları:** yalnız fiyat ve teknik veri **kaynağı** olarak geçer;
  hackathon kapsamında sipariş verilmez.

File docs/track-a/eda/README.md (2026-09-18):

# EDA kaynağı ve şema üreteçleri

`docs/track-a/03-baglanti-semasi.svg` bu klasördeki **KiCad şematiğinden** üretilir: gerçek bir `.kicad_sch`
(ERC'den geçmiş, netlist'i 03-pinout §3.1 ile otomatik doğrulanmış) → `kicad-cli` → gömülebilir SVG.
`cad/` klasörüyle aynı felsefe: **elle çizim yok, kaynak model var.** (Önceki elle yazılmış SVG git geçmişinde: `f5bf9be` ve öncesi.)

`docs/track-a/08-sistem-mimarisi.svg` bu klasördeki **`gen_mimari.py`** ile üretilir (karar kaydı §8 mimari + §9 sözleşmeler;
Pano → Gateway → On-prem zinciri; T3 + T4 + T6 + T7). Kutu içerikleri üç izin repodaki gerçek servislerinden alınmıştır
(toplama/, analiz/README.md, PR #2 operasyon-yuzu-dokumantasyonu.md, modul-sim/). Kutular `box()` yardımcısıyla
içerikten boyutlanır; her metin Arial metriğiyle (PIL) ölçülür, kutudan taşan varsa üretim hata verir. Düzenleme
script'te yapılır, SVG'ye elle el değmez.

## Dosyalar

| Dosya | İçerik |
|---|---|
| `gen_sch.py` | Şema üreteci. Sembolleri KiCad kütüphanesinden (`share/kicad/symbols`) okuyup `lib_symbols`'a gömer, `extends` sembolleri düzleştirir; pin uçlarını kütüphane geometrisinden hesaplar; tel / etiket / güç sembolü / NC / not yerleşimi burada. Kütüphanede olmayan MLX90640 için özel sembol (`GridUp.kicad_sym`). |
| `GridUp-Modul.kicad_sch` / `.kicad_pro` | Üretilen şema (tek sayfa, özel 340 × 300 mm kâğıt; SVG'de çerçeve atılır) ve proje. `sym-lib-table` / `fp-lib-table` proje-yerel (`${KICAD10_SYMBOL_DIR}` / `${KICAD10_FOOTPRINT_DIR}`); KiCad GUI'de doğrudan açılır. |
| `GridUp-Modul.net` | `kicad-cli sch export netlist` çıktısı (mutlak yol ve zaman damgası temizlenmiş, deterministik) — doğrulamanın girdisi, commit'li. |
| `verify_netlist.py` | Netlist'i beklenen bağlantılarla karşılaştırır: 103 kontrol (GPIO atamaları, güç rayları, D1/D2 yönü, süperkap zinciri + boost, 120 Ω, EN RC, V_bias, CT kanalları). Tek başına: `python verify_netlist.py GridUp-Modul.net`. |
| `svg_min.py` | kicad-cli SVG'sini gömülebilir yapar (2 MB → ~280 KB): çizgi-font yollarını atar, KiCad'in yazdığı gizli `<text>`'i Arial/Helvetica ile görünür yapar (renk = grubun stroke rengi), viewBox'ı içeriğe kırpar, koordinatları yuvarlar, tarih damgasını siler (deterministik). |
| `build.py` | Zincir: `gen_sch.py` → ERC → netlist + `verify_netlist.py` → SVG → `svg_min.py`. |
| `gen_mimari.py` | 08 üreteci: bölge / kutu / ok yardımcıları + taşma denetimi → `../08-sistem-mimarisi.svg`. Tek başına: `python gen_mimari.py [CIKTI]`. |
| `erc-raporu.txt` | Son ERC çıktısı (`--severity-all`): 0 hata, 0 uyarı. |
| `../03-baglanti-semasi.svg` | Çıktı (dokümandaki şema). `build.py --out=PATH` ile başka yere de yazılabilir. |

## Üretim zinciri

```
gen_sch.py → GridUp-Modul.kicad_sch → kicad-cli sch erc → kicad-cli sch export netlist → verify_netlist.py
                                     → kicad-cli sch export svg (çerçevesiz, atlama yaylı) → svg_min.py → ../03-baglanti-semasi.svg
```

```
python build.py                    # KiCad 10 (winget KiCad.KiCad) varsayılan yolda; yoksa --kicad-cli=PATH
```

## Şema içeriği (03-pinout.md §3.1–3.6 ile birebir)

- **U1 ESP32-S3-WROOM-1U** (kütüphane sembolü `ESP32-S3-WROOM-1`, aynı pinout): I²C GPIO8/9; CT GPIO4–7 (ADC1_CH3–6);
  besleme algılama GPIO1 (ADC1_CH0); UART1 GPIO17/18 + DE/RE GPIO21; genişleme GPIO10/11; USB D∓ ve UART0 servis
  başlığına; EN 10 k + 1 µF + reset; strapping / flash pinleri NC.
- **U2 MLX90640** (0x33, 100 nF), **U3 SHT31-DIS** (0x44, ADDR → GND, nRESET → 3V3), 2× 4,7 kΩ pull-up.
- **CT ön ucu ×4**: klemens → R_burden + V_bias (2× 100 k + 10 µF) → 1 kΩ / 100 nF RC → CT_L1…CT_N.
- **U4 MAX3485**: RO/DI ↔ UART1, RE+DE ↔ GPIO21, A/B → klemens + 120 Ω.
- **Besleme**: L/N/PE → F1 + MOV → **U5 RAC05-05SK/277** → 5V_RAW (100 k / 47 k → VSENSE) → **D1** Schottky (OR) → +5V rayı
  → **U6 AP7361C-33E** (1 A, dropout ≈0,3 V; SOT-223, layout: tab altı ≥ 1 cm² bakır + termal via — 04 §4.6) → +3V3; yedek yolu **R_şarj → C32 + C33 (2× Eaton HV1030 10 F / 2,7 V seri, R53/R54 dengeleme) → U7 TPS61099 boost 4,6 V → D2 → +5V**
  (float ≈4,7 V = 5 V − D1, 02-bom §2.5; +85 °C derate 4,6 V = 2,3 V/hücre; ~50 J → ~5 dk @ 50 mA). PWR_FLAG'ler yalnız ERC için (dış kaynaklar; SW pini kütüphanede power_in).
- Anten: SMA panel konnektörü (U.FL pigtail RF, şemada net değil). Genişleme 2×5: 3V3 / 5V / GND / SDA / SCL / GPIO10 / 11.

## Yerleşim ve okunurluk (gömme için tasarım)

- **Sinyal akışı soldan sağa:** sol sütun girişler — CT ön ucu üstte (ESP üst pinleri IO4–7), I²C sensörler altta
  (IO8–9) → besleme telleri kesişmeden ESP'ye girer; orta ESP32-S3; sağ sütun çıkışlar (servis başlığı, RS-485,
  anten, genişleme); altta besleme zinciri.
- **Ana hatlar tel:** I²C bus (SDA/SCL dikey), CT_L1…N (kesişmesiz merdiven), UART1 ↔ MAX3485 (çip `mirror x` ile
  aynalı → pin sırası ESP ile aynı, tek kesişme). Güç netleri sembol; VSENSE, V_BIAS, 5V_RAW ve servis/genişleme
  başlıkları etiket (aynı ad = aynı net). Kaçınılmaz kesişmeler `--draw-hop-over` ile atlama yayı.
- **Renk kodu** (tel + etiket): 3V3 kırmızı, 5 V/230 V koyu kırmızı, GND/PE gri, I²C mavi, UART/RS-485 mor, analog
  turuncu; her blok açık tonlu dolgu + renkli başlık; lejant sağ üstte.
- **Yazı boyutu:** etiket 2,0 mm, not 1,8, başlık 2,2, pin adı 1,6; içerik ~305 × 252 mm → dokümana 1200 px
  genişlikte gömülünce etiket ≈ 8 px, not ≈ 7 px (eski elle SVG: 8–9,5 px). Çerçeve/başlık bloğu export'ta atılır,
  viewBox içeriğe kırpılır.
- **Elle SVG'den KiCad'e geçiş gerekçesi:** elle SVG'de metin kutularından taşmalar ve doğrulanmamış bağlantılar
  vardı; KiCad şematik tek doğruluk kaynağı (03-pinout §3.1 → `verify_netlist.py`), ERC + netlist kanıtı, her
  değişiklik script'te ve deterministik. Eksisi: KiCad sembol dili (NC pinler dahil büyük ESP32 dikdörtgeni), not
  yerleşimi daha az özgür, 21 KB → ~280 KB.

## Kurallar / notlar

- Net adları KiCad kısıtı gereği boşluksuz (`CT_L1`, `DE_RE`, `5V_RAW`); mm cinsinden 1,27 grid.
- Kavramsal şema — üretim çizimi değildir (karar kaydı §1.4); pasif değerler tipik başlangıç değerleri.
- Ayak izleri (footprint) sembol eşleşmesi için atanmıştır, PCB tasarımı yoktur (`02-pcb-yerlesimi.svg` Fusion'dandır).
- Font: SVG çıktısı Arial/Helvetica (`svg_min.py`); KiCad GUI kendi fontunu kullanır.

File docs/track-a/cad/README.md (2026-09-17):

# CAD kaynakları ve çizim üreteci

`docs/track-a` altındaki üç kroki (`02-pcb-yerlesimi.svg`, `04-kutu-krokisi.svg`, `04-yerlesim-krokisi.svg`)
elle çizilmez; **Fusion 360 modellerinden** üretilir. Bu klasör kaynak modelleri ve üretim zincirini taşır.

## Modeller

| Dosya | İçerik | Koordinat |
|---|---|---|
| `GridUp-Kutu.f3d` / `.step` | Modül kutusu 120 × 80 × 50: gövde (2 mm duvar, R4), kapak 4 mm, IR yuva Ø23 / pencere Ø15, vent M6, LED, 4 × M3 köşe direği Ø7, 4 × PCB dikmesi Ø6, alt yüz soldan sağa RS-485 PG7 / SMA / CT PG7 / 230 V PG7 (PCB klemens sırasıyla hizalı), DIN klips, oval M5 yuvalar, mıknatıs cepleri | X sağ, Y yukarı, Z ön yüz normali (kapak Z 46–50) |
| `GridUp-PCB.f3d` / `.step` | Kart 110 × 70 × 1,6 + 36 parça gövdesi (ön: MLX90640 TO-39, SHT31, LED, pasifler / arka: ESP32, RAC05 31,7 × 26,7 × 21,8, 2× süperkap HV1030 Ø10,5 × 31,5 yatık, boost + L, klemensler — **230 V giriş klemensi 3 kutup L/N/PE 5,08 = 15,24 mm**, MAX3485, …); M3 delikler (7,7) vb.; köşelerde Ø8 direk boşluğu; 1 mm izolasyon yarığı | kart köşesi orijin; **PCB koordinatı = kutu koordinatı − 5 mm** |
| `GridUp-Kutu-Montaj.f3d` / `.step` | Kutu + PCB (PCB kutuda (5, 5, 39,4)); yan kesit ve iç görünüş buradan | kutu koordinatı |
| `GridUp-Pano.f3d` / `.step` | 1600 kVA AG pano 1600 × 1500 × 450 (2 mm sac, 20 mm montaj plakası, 22 mm kapak), 36 NH ayırıcı + klemens + T1/kontrol/kumanda/modem blokları, montaj kapak iç yüzünde (IR merkezi 650, 692,5) | X sağ, Y yukarı, Z öne; kapak iç yüzü Z = 0, plaka Z = −430 |

`.f3d` dosyaları thozoz hub / Default Project'teki bulut belgelerinin arşivleridir (montaj arşivi referansları içermez;
tam geometri için `.step`).

## Üretim zinciri

```
model_*.py  →  Fusion belgesi  →  proj.py + cfg_*.json  →  views/*-views.json  →  compose_*.py + svgkit.py  →  SVG
```

1. **Model script'leri** (`model_kutu.py`, `model_pcb.py`, `model_montaj.py`, `model_pano.py`): Fusion API ile geometriyi
   sıfırdan kurar. Fusion içinde çalışır (MCP `fusion_mcp_execute` script veya *Utilities → Scripts*). Türkçe karakter
   içeren gövde adları `chr()` ile verilir (MCP metni latin-1 okuyor).
2. **`proj.py`**: aktif tasarımdan ortografik projeksiyon. Kenarlar + silindir siluetleri; görünürlük
   `Component.findBRepUsingRay` ile parça parça test edilir (gizli çizgi ayıklama); `clip` ile yarım-uzay,
   `section` ile `TemporaryBRepManager.planeIntersection` kesit poligonları. Görünüşler `cfg_*.json` içinde
   (`d` bakış vektörü, `u` yukarı, `include/exclude(_prefix)`, `clip`, `section`). Çıktı mm cinsinden polyline
   listesi (`y` aşağı). Fusion'da:
   ```python
   globals()['CFG_PATH'] = r'<repo>/docs/track-a/cad/cfg_kutu.json'
   exec(compile(open(r'<repo>/docs/track-a/cad/proj.py', encoding='utf-8').read(), 'proj.py', 'exec'), globals())
   ```
   Hangi cfg hangi belgede: `cfg_kutu` → GridUp-Kutu, `cfg_pcb` → GridUp-PCB, `cfg_montaj` → GridUp-Kutu-Montaj,
   `cfg_pano` → GridUp-Pano (montajı açmadan önce *referansları güncelle*).
3. **`compose_*.py`** (Fusion gerekmez, düz Python 3): `views/*.json` + etiket/ölçü/not → SVG.
   ```
   python compose_kutu.py ../04-kutu-krokisi.svg
   python compose_pcb.py  ../02-pcb-yerlesimi.svg
   python compose_pano.py ../04-yerlesim-krokisi.svg
   ```
   `views/` klasörü commit'lidir; Fusion'a erişim olmadan da SVG yeniden üretilebilir (etiket düzeltmesi vb.).

## Kurallar

- Ölçüler mm; SVG ölçekleri: kutu 1 mm = 4 birim, PCB 1 mm = 8, pano 1 mm = 1.
- Font Arial/Helvetica; ayraç " / "; LF satır sonu (`newline=''`).
- Kutu ↔ PCB senkronu: ön yüz özellikleri (IR pencere, vent, LED) kutu koordinatında tanımlı; PCB'de aynı parça
  −5 mm. PCB dikmeleri kutu (12,12)/(108,12)/(12,68)/(108,68) = PCB (7,7)/(103,7)/(7,63)/(103,63).
- Kavramsal tasarım — üretim çizimi değildir (karar kaydı §1.4).

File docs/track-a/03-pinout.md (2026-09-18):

# 3. Bağlantı ve Pinout Tablosu

**Teslimat karşılığı:** T2 (giriş-çıkış bağlantıları, bağlantı şemaları)
**Dayandığı kararlar:** §7.1 ölçüm kümesi · §7.4 haberleşme
**Biçim notu:** Karar kaydı satır 626 *"çizim olmak zorunda değil, tablo da olabilir"* der; ancak
organizatörün açılış sunumu (transkript 735 s) *"bir tasarımınız varsa bunun bağlantı şemalarını görmek
isteriz"* diyerek şemayı açıkça istedi. Bu nedenle tabloların yanında **bağlantı şeması** da verilmiştir.
Arayüz özeti ve blok şema için bkz. [1. doküman](01-blok-sema.md).

---

## 3.0 Bağlantı şeması

Modül bağlantı şeması — ESP32-S3 etrafında tüm hatlar

*(Şema §3.1 pin tablosunun birebir görsel karşılığıdır: sol sütunda CT ön ucu (üst) ve I²C sensörler (alt), ortada
ESP32-S3, sağ sütunda servis/RS-485/anten/genişleme, altta besleme zinciri. Ana hatlar tel (I²C bus, CT kanalları,
UART1 ↔ RS-485), güç netleri sembol, aynı adlı etiketler aynı net; tel kesişmeleri atlama yayıyla gösterilir.
Tabloda olmayan tek ekleme **GPIO1 besleme algılama** girişidir — aşağıdaki tabloya işlenmiştir. Pasif değerler tipik
başlangıç değerleridir; üretim çizimi değildir, §1.4. Parçaların kart üzerindeki yeri: [02-pcb-yerlesimi.svg](02-pcb-yerlesimi.svg).)*

*Kaynak: KiCad şematik [eda/GridUp-Modul.kicad_sch](eda/GridUp-Modul.kicad_sch) — [ERC 0 hata / 0 uyarı](eda/erc-raporu.txt),
[netlist](eda/GridUp-Modul.net) 103 kontrolle §3.1 ile birebir doğrulanmış; bu SVG `eda/build.py` ile o şemadan üretilir
(elle çizim yok). Üretim zinciri: [eda/README.md](eda/README.md).*

---

## 3.1 Arayüzler ve kullanılan pinler (öneri)

> **Durum:** Aşağıdaki pin atamaları **tasarım önerisidir**, PCB yerleşimi sırasında
> doğrulanacaktır. Pin numaraları Espressif datasheet'inden (ESP32-S3-WROOM-1U, v1.8)
> doğrulanmış **kısıtlara** uyacak şekilde seçilmiştir; atamanın kendisi bu dokümanın kararıdır.

| Arayüz | Sinyal | GPIO | Gerekçe / kısıt |
|---|---|---|---|
| **I²C (paylaşımlı)** | SDA | GPIO8 | Strapping değil, USB değil, flash değil — serbest |
| | SCL | GPIO9 | Aynı; I²C hattı iki sensör tarafından paylaşılır |
| **Akım kanalı A** | CT L1 | GPIO4 | **ADC1_CH3** — Wi-Fi ile birlikte kullanılabilir |
| **Akım kanalı B** | CT L2 | GPIO5 | **ADC1_CH4** |
| **Akım kanalı C** | CT L3 | GPIO6 | **ADC1_CH5** |
| **Akım kanalı D** | CT nötr | GPIO7 | **ADC1_CH6** |
| **Modbus hattı** | UART TX | GPIO17 | Datasheet: `U1TXD` |
| | UART RX | GPIO18 | Datasheet: `U1RXD` |
| | DE/RE (yön) | GPIO21 | RS-485 alıcı-verici yön kontrolü |
| **Besleme algılama** | 5 V sense | GPIO1 | **ADC1_CH0** — RAC05 çıkışı (OR diyotu öncesi) 100k/47k bölücüyle okunur; `modul_durum.besleme` = `sebeke`/`yedek` ayrımı bu pinden gelir (§7.3, sözleşme ②) |
| **Genişleme payı** | (ayrılmış) | GPIO10, GPIO11 | Kullanılmıyor; PD/akustik için ayrıldı (§7.1 satır 237) |
| **Anten** | U.FL | — | GPIO değil; `1U` varyantının harici konnektörü |
| **Besleme** | 3V3 / GND | — | Kart LDO çıkışı (AC/DC modül 5 V verir, LDO 3,3 V'a düşürür — §3.4) |
| **Reset** | EN | — | Kart üzerinde RC + buton |

### ⚠️ Kritik teknik kısıt — ADC2 Wi-Fi ile kullanılamaz

ESP32-S3'te **ADC2 kanalları, Wi-Fi aktifken kullanılamaz** (Wi-Fi radyosu ADC2'yi paylaşır).
Modülümüz sürekli Wi-Fi üzerinden veri gönderdiği için, 4 akım kanalının **tamamı ADC1'e**
atanmak zorundadır.

- ✓ ADC1_CH3…CH6 → GPIO4, GPIO5, GPIO6, GPIO7 (L1, L2, L3, nötr) — **seçilen**
- ✗ ADC2 kanalları — haberleşme aktifken güvenilir okunamaz, bu nedenle kullanılmaz

Bu kısıt, "analizör yoksa 4 split-core CT" senaryosunda tasarımı doğrudan belirler.
**Not:** Bu senaryoda harici bir ADC çipi (I²C/SPI üzerinden) kullanmak **değerlendirilmiş bir
alternatiftir**, ancak **BOM'da kalem olarak yer almaz** — seçilen tasarım ESP32-S3'ün dahili
ADC1 kanallarını kullanır. Harici ADC, analizörsüz senaryoda ölçüm kalitesi yetersiz kalırsa
başvurulacak yedek yoldur (prototip ölçümleriyle karar verilir).

### Kullanılmayan / kaçınılan pinler

| Pin | Neden kullanılmıyor |
|---|---|
| **GPIO0, GPIO3, GPIO45, GPIO46** | **Strapping pinleri** — açılış davranışını belirler. GPIO0/46 boot modu, GPIO3 JTAG kaynağı, GPIO45/46 VDD_SPI gerilimi. Sensör/aktüatör bağlanmaz. |
| **GPIO19, GPIO20** | USB D−/D+ — seri debug/olası firmware güncellemesi için ayrılır |
| **GPIO43, GPIO44** | U0TXD/U0RXD — seri konsol/debug için ayrılır |
| **GPIO26–GPIO32** | Modül içindeki QSPI flash / (varsa) PSRAM tarafından kullanılır, modül pinlerinde yoktur |
| **GPIO35–GPIO37 (modül pin 28–30)** | **Octal PSRAM'li varyantlarda** (ESP32-S3**R8**/**R16V**) bu pinler Octal SPI PSRAM'e bağlıdır ve başka amaçla kullanılamaz. **Bizim seçtiğimiz N8 varyantında PSRAM yoktur → bu pinler serbesttir.** Yine de NC bırakılır: gereksinim yok ve pin 28–30'a bağlanacak bir sinyal tanımlı değil |

> **Neden bunu yazma gereği duyduk:** Strapping pinine yanlışlıkla sensör bağlamak, cihazın
> açılış modunu bozar ve sahada "rastgele çalışmayan modül" olarak görünür — teşhisi zor bir hata
> türüdür. Bu yüzden yasak pinler açıkça listelenmiştir.

---

## 3.2 Sensör bağlantıları

| Bileşen | Arayüz | Adres / yapılandırma | Ortak hat |
|---|---|---|---|
| **MLX90640** (termal dizi) | I²C | **Adres 0x33** (datasheet) | SDA=GPIO8, SCL=GPIO9 |
| **SHT31** (sıcaklık+nem) | I²C | **Adres 0x44** (ADDR pini GND'ye; VDD'ye bağlanırsa 0x45) | SDA=GPIO8, SCL=GPIO9 |
| **Enerji analizörü** (varsa) | RS-485 | Modbus slave adresi + seri parametreler analizörden ayarlanır | A/B hattı → UART1 |
| **TVOC-2** (varsa) | RS-485 | Modbus slave adresi ayarlanır | Aynı A/B hattı → UART1 |
| **Split-core CT ×4** (analizör yoksa) | Analog | Burden direnci + yarımsal önyargı | ADC1_CH3…CH6 |

**Adres çakışması yok:** 0x33 (termal) ve 0x44 (SHT31) farklı adreslerdir, bu nedenle tek I²C
hattı ikisini taşıyabilir.

### I²C hattı gerekçesi

I²C, kısa mesafeli (kart üzeri) sensör bağlantısı için uygundur ve her iki sensör de I²C'dir.
**Tek hat kullanılmasının sebebi:** kablo ve pin tasarrufu; modül içindeki mesafe birkaç santim
olduğundan I²C'nin mesafe sınırı sorun değildir.

**Termal dizi için ayrı dikkat:** MLX90640 ham verisi 768 değerdir ve okuması birkaç ardışık
register transferi gerektirir. I²C hızı bu nedenle **400 kHz (fast mode)** veya üzeri
yapılandırılmalıdır; aksi halde 10–30 sn'lik termal özet çevrimi gecikebilir (§7.2).
Datasheet I²C hızını 1 MHz'e kadar desteklendiğini belirtir.

---

## 3.3 RS-485 / Modbus hattı

```
   Modül (master)                    Panodaki cihazlar (slave)
   ┌──────────────
   │  UART1       │
   │  TX  GPIO17 ────┐
   │  RX  GPIO18 ─┼───┤
   │  DE/RE GPIO21┼─┐ │
   └──────────────┘ │ │
                    │ │   ┌─────────────┐
              ┌─────▼─▼───┤ RS-485      │
              │  transceiver│ A/B  ─────────> Enerji analizörü
              ─────────────┘           │
                                        └────> TVOC-2
```

| Özellik | Değer / karar |
|---|---|
| Protokol | Modbus RTU |
| Fiziksel katman | RS-485, yarıçift yönlü (half-duplex) |
| Yön kontrolü | DE/RE pini (GPIO21) TX sırasında sürülür |
| Hat sonlandırma | Hattın iki ucunda 120 Ω sonlandırma direnci |
| Cihaz adresleri | Analizör ve TVOC-2 farklı Modbus slave adreslerine sahip olmalı |

**Neden RS-485:** Pano içi mesafe birkaç metre ve elektromanyetik gürültü yüksektir (baralar,
anahtarlama). RS-485 diferansiyel sinyalleşme kullandığından bu ortamda güvenilirdir.

**Neden ek sensör yerine okuma:** §7.1 satır 229 — panoda analizör varsa akım için yeni sensör
ve kablo gerekmez. Bu, brief'in "kablo kalabalığı" şikâyetine doğrudan cevaptır.

**Ark kanalı önemli not:** TVOC-2'den **yalnızca trip/diagnostik kaydı okunur.** Modül ark
algılamaz; ilgili register haritası `1SFC...TVOC-2_Modbus_Manual.pdf` dosyasındadır
(trip 100–149, diagnostik 200–225, hata 300+). Bu kanal hiçbir yerde "ark tespiti" olarak
adlandırılmaz (§7.1 satır 230).

---

## 3.4 Besleme bağlantısı

```
   230 V iç ihtiyaç
   devresi (ilgili sigorta)
        │
        ▼
   ┌────────────────┐  5 V   D1        5 V rayı                   3V3 rayı
   │ AC/DC modül    ├──────►|────────────┬──────┤ LDO 3.3 V ├────┬──► ESP32-S3
   │ RAC05-05SK/277 │                    │                       ├──► MLX90640 / SHT31
   └────────────────┘                    │ R_şarj 22 Ω           └──► RS-485, CT bias
                                          │
                                          ├──/\/\──┤ Süperkap ├─┐
                                          │   (2S, float ≈4,7 V) │
                                          │                      ▼
                                          │                 ┌──────────┐
                                          │                 │  BOOST   │
                                          │                 │ TPS61099 │→ 4,6 V
                                          │                 └────┬─────┘
                                          │                      │ (bobin 2,2 µH)
                                          └──────────────────────┤
                                                                 ▼
                                                              ►|── D2 ──► 5 V rayı

   kesintide: süperkap → BOOST (4,6 V) → D2 → 5 V rayı (→ LDO → 3V3)
   D1 = OR diyotu (Schottky): süperkaptan şebekeye ters akışı keser;
        şebeke algılama (GPIO1) D1 ÖNCESİNDEN ölçülür
```

| Hat | Kaynak | Hedef | Not |
|---|---|---|---|
| 230 V AC | Pano iç ihtiyaç devresi | AC/DC modül girişi | Yalnız ilgili yardımcı devrenin sigortası çekilir; abonelere giden elektrik kesilmez (§7.3) |
| 5 V DC | AC/DC modül | Kart rayı / süperkapasitör float şarjı | Şarj `R_şarj 22 Ω` üzerinden; float gerilimi ≈4,7 V (D1 sonrası ray) |
| 3V3 | Kart LDO regülatörü (BOM #12) | ESP32, sensörler, RS-485 | |
| Kesinti hattı | Süperkapasitör → **boost (TPS61099, 4,6 V)** → D2 | 5 V rayı (→ LDO) | Boost, süperkapı 1 V'a kadar sömürür; D2 yönü rayı besler |

**Kaçınılacak bağlantı:** Enerji hasadı (CT'den enerji çekme) **varyanttır**, ana tasarım değildir.
§7.3 satır 279'daki red gerekçeleri: akım yokken modül tamamen susar (tam da izlenmesi gereken
anda cihaz ölür), elde edilen güç birkaç yüz mW, CT ucu açık kalırsa tehlikeli gerilim oluşur,
tasarım yükü yüksektir.

---

## 3.5 Anten bağlantısı

| Öğe | Detay |
|---|---|
| Modül konnektörü | U.FL (ESP32-S3-WROOM-**1U**'nun harici anten konnektörü) |
| Kablo | U.FL → panel tipi SMA pigtail, kısa |
| Anten | Panel montajlı harici anten, panonun dış yüzünde |
| Kablo geçişi | Panonun **mevcut kablo giriş noktası** kullanılır (§7.4 satır 296) |

**Neden dış anten:** Pano metal muhafazadır; iç antenle sinyal dışarı çıkmaz ve bu, "modülden veri
gelmiyor" biçiminde **sessiz bir arıza** olarak görünür — fark edilmesi en zor arıza türüdür.

**Neden U.FL:** Modül seçimi (`1U`) zaten harici konnektör için yapılmıştır; anten kablosu
panonun dışına çıkarılırken modül kartında lehim/konektör karmaşası oluşmaz.

**Montaj notu:** Anten kablosu **menteşe yakınında kıvrım payı bırakılarak** yönlendirilir (§7.5).

---

## 3.6 Genişleme arayüzü (bağlayıcı şart)

§7.1 satır 237 zorunlu kılar: *"modül ek ölçüm kanalları için genişletilebilir arayüz taşır."*

| Ayrılan kaynak | Amaç |
|---|---|
| I²C hattına ek adres alanı | Yeni I²C sensör doğrudan eklenebilir (hattın kendisi zaten var) |
| GPIO10, GPIO11 | Dijital/UART genişleme |
| ADC1_CH9 (GPIO10) | Ek analog kanal |
| Yazılımda ayrılmış ölçüm kanalı | `olcum_tipi` enum'ı yeni değer kabul eder; ölçüm kaydı uzun formatta |

**Ekleme maliyeti neden düşük (§7.1 satır 236):** `olcum_tipi` ve `tip` enum olarak tanımlı,
ölçüm kaydı uzun (dar) formatta tutuluyor ve dedektör arayüzü sabit — bu nedenle yeni bir ölçüm
eklemek **şema değişikliği gerektirmez**. Ekleme maliyeti: üretece bir kanal, bir dedektör,
dokümana bir blok.

**Ertelenen fark katmanı:** PD (kısmi deşarj) — 17 mV/mA, 50 Ω yük, 1–60 MHz (§2.5) — ve
akustik (40 kHz bandı) adaylarından biri seçilecek. İkisi birlikte yapılmıyor: aynı arıza
sınıfına bakıyorlar, öğrenme yükü yüksek ve savunulamayan her kanal tüm sistemin güvenilirliğini
düşürür (§7.1 satır 240).

---

## 3.7 Bağlantı özeti (tek tablo)

| # | Bileşen | Arayüz | Pin(ler) | Yön | Not |
|---|---|---|---|---|---|
| 1 | MLX90640 | I²C | GPIO8 (SDA), GPIO9 (SCL) | Çift yönlü | 0x33, 3.3 V, <23 mA |
| 2 | SHT31 | I²C | GPIO8, GPIO9 (paylaşımlı) | Çift yönlü | 0x44 |
| 3 | CT L1 | ADC | GPIO4 (ADC1_CH3) | Giriş | Burden + önyargı |
| 4 | CT L2 | ADC | GPIO5 (ADC1_CH4) | Giriş | |
| 5 | CT L3 | ADC | GPIO6 (ADC1_CH5) | Giriş | |
| 6 | CT nötr | ADC | GPIO7 (ADC1_CH6) | Giriş | |
| 7 | RS-485 transceiver | UART | GPIO17 (TX), GPIO18 (RX), GPIO21 (DE/RE) | Çift yönlü | Modbus RTU |
| 8 | Genişleme | I²C/UART/ADC | I²C hattı + GPIO10, GPIO11 | — | Ayrılmış, boş |
| 9 | Anten | RF | U.FL konnektör | Çıkış | Panel SMA, dış |
| 10 | Besleme | Güç | 3V3, GND, EN | — | AC/DC 5 V → LDO 3V3; süperkapasitör kesintide |

---

## 3.8 Doğrulama listesi (PCB öncesi kontrol)

- [x] Strapping pinlerinden (GPIO0, 3, 45, 46) hiçbirine sensör/aktüatör bağlanmadı mı?
- [x] Akım kanallarının tamamı **ADC1**'de mi (Wi-Fi aktifken ADC2 çalışmaz)?
- [x] I²C adresleri çakışıyor mu (0x33 vs 0x44 — çakışma yok)?
- [x] I²C hattında pull-up dirençleri var mı (tipik 4,7 kΩ)?
- [x] RS-485 hattında 120 Ω sonlandırma var mı?
- [x] Anten kablosu için menteşe yakınında kıvrım payı bırakıldı mı?
- [x] Genişleme pinleri (GPIO10, GPIO11) boş bırakıldı mı ve dokümanda belirtildi mi?
- [x] Süperkapasitör **float** şarj devresine bağlı mı (ana kaynak değil)?
- [x] Güçlü mıknatıs akım trafolarından uzak mı (§7.5 satır 337 uyarısı)?

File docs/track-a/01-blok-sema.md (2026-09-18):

# 1. Modül Blok Şeması

**Teslimat karşılığı:** T1 (kabin içi modül tasarımı) · T2 (elektronik tasarım dokümantasyonu)
**Dayandığı kararlar:** §7.1 ölçüm kümesi · §7.3 besleme · §7.4 haberleşme
**Bağlayıcı şart:** Genişleme payı ifadesi — §7.1 satır 237

---

## 1.1 Blok şema

```mermaid
flowchart TB
    subgraph PANO["PANO İÇİ — modül kutusu"]
        subgraph SENSOR["Sensör katmanı"]
            T["Termal dizi<br/>MLX90640 (32×24, 110°×75°)<br/>I²C · 3.3 V · &lt;23 mA"]
            TH["Sıcaklık + nem<br/>SHT31<br/>I²C · 3.3 V"]
            EXT["Genişleme arayüzü<br/>(boş — PD / akustik için)"]
        end

        subgraph OLCUM["Ölçüm katmanı (pano tarafı)"]
            AN["Enerji analizörü<br/>(panoda mevcutsa)<br/>RS-485 / Modbus"]
            CT["Split-core CT ×4<br/>(analizör yoksa)<br/>L1 / L2 / L3 / nötr"]
            ARC["Ark dedektörü TVOC-2<br/>(panoda mevcutsa)<br/>RS-485 / Modbus"]
        end

        MCU["Mikrodenetleyici<br/>ESP32-S3-WROOM-1U-N8<br/>Wi-Fi + BLE · harici anten<br/>−40…+85 °C"]
        RX["RS-485 alıcı-verici<br/>(Modbus)"]

        subgraph GUC["Besleme"]
            PSU["AC/DC modül<br/>RECOM RAC05-05SK/277<br/>230 V → 5 V · −40…+90 °C*"]
            SC["Yedek depo<br/>2× süperkapasitör seri<br/>(float şarjlı)"]
            BST["Boost çevirici<br/>TPS61099 → 4,6 V<br/>(yalnız kesintide)"]
            LDO["3.3 V regülatör<br/>(LDO — MCU ve sensörler)"]
        end

        ANT["Dış anten konnektörü<br/>U.FL → panel SMA"]
    end

    subgraph DISI["PANO DIŞI"]
        GWA["Saha gateway'i<br/>(trafo binası içi)<br/>— İZ C kapsamı"]
    end

    T -->|"I²C 0x33"| MCU
    TH -->|"I²C"| MCU
    EXT -.->|"ayrılmış I²C/UART<br/>(genişleme payı)"| MCU
    AN -->|"RS-485"| RX
    ARC -->|"RS-485"| RX
    CT -->|"analog / burden"| MCU
    RX -->|"UART"| MCU

    PSU -->|"5 V"| LDO
    PSU -->|"float şarj"| SC
    SC -.->|"kesintide"| BST
    BST -.->|"D2 → 5 V rayı"| LDO
    LDO -->|"3.3 V"| MCU

    MCU -->|"U.FL kablosu"| ANT
    ANT -.->|"kablosuz (2.4 GHz)"| GWA

    classDef sensor fill:#e3f2fd,stroke:#1565c0,color:#000
    classDef olcum fill:#fff3e0,stroke:#ef6c00,color:#000
    classDef mcu fill:#c8e6c9,stroke:#2e7d32,color:#000
    classDef guc fill:#fce4ec,stroke:#ad1457,color:#000
    classDef disi fill:#eeeeee,stroke:#616161,color:#000
    class T,TH,EXT sensor
    class AN,CT,ARC olcum
    class MCU,RX mcu
    class PSU,SC,BST,LDO,ANT guc
    class GWA disi
```

> **Şemanın metin hali:** panonun içindeki modül kutusunda termal dizi ve sıcaklık/nem sensörü
> doğrudan mikrodenetleyiciye I²C ile bağlıdır. Akım ve ark verisi ya panoda bulunan enerji
> analizörü ve TVOC-2'den RS-485/Modbus ile, ya da analizör yoksa split-core CT'lerden analog
> olarak alınır. Mikrodenetleyici veriyi işler ve panonun dışına çıkarılan anten üzerinden saha
> gateway'ine gönderir. Modül, 230 V iç ihtiyaç devresinden beslenir; süperkapasitör float
> durumda şarjlı bekler ve yalnızca besleme kesildiğinde devreye girer.

> **\\* AC/DC modülün sıcaklık sınıfı — dipnot.** Datasheet 5 V çıkış için **tam yükte
> −40…+75 °C** verir; **+90 °C** yalnız **derating grafiğiyle** (düşük yükte) ulaşılır. Modülümüzün
> çekişi 5 W anma gücünün ~%15–40'ı olduğundan derating eğrisinde +85…+90 °C bölgesi
> kullanılabilir — şartname karşılanır. Bkz. [KAYNAKÇA.md §1.5](KAYNAKCA.md).

---

## 1.2 Blok blok gerekçeler

### Termal dizi — MLX90640 (32×24, 110°×75°)

**Ne yapar:** 768 pikselden aynı anda yüzey sıcaklığı okur. Fotoğraf değil, sıcaklık matrisi üretir.

**Neden bu ölçüm kritik:** Ortam sıcaklığı *"kabin ısındı"* der; termal dizi *"7 numaralı klemens
ısındı"* der. En yaygın arıza nedeni olan gevşek klemensi **nokta bazında** yakalayan tek ölçüm
budur ve projenin erken uyarı iddiasını gerçek kılan ölçüm budur (§7.1 satır 227).

**Neden 110°×75°:** Modül kapağa takılıp klemenslere **377 mm** (montaj plakası) / **155,5 mm** (NH
ayırıcı ön yüzü) mesafeden bakar; bu mesafelerde kapsama **1077 × 579 mm** ve **444 × 239 mm** olur
(§7.1 satır 232 kayıt hesaplamasını *"~40 cm, kabaca 114 × 61 cm"* diye yaklaşık vermişti; gerçek
model bunu kesinleştirdi — ayrıntı [4. doküman §4.3](04-mekanik-yerlesim.md)). Geniş açı, tan
hesabıyla 110°×75°'ye denk gelir. Dar açılı (55°×35°) varyant aynı mesafeden yalnızca ~39 × 24 cm
görür ve klemens sırasını hiç kapsamaz.

**Piksel ölçeği:** 377 mm'de piksel başına yaklaşık **3,4 × 2,4 cm**, 155,5 mm'de **1,4 × 1,0 cm**
düşer. Klemens adımı ~20–25 mm olduğundan, NH düzlemindeki piksel her klemensi kendi pikselinde
görür — *"gevşek klemensi nokta bazında yakala"* iddiasının dayanağı budur.

**Duyarlılık:** NETD 0,1 K RMS @1 Hz (komşu noktalar arasındaki 0,1 °C farkı ayırt eder). Mutlak
doğruluk ±1–2 °C'dir. Tespit için önemli olan **çözünürlük ve göreli fark**tır; *"bu klemens
komşularından 15 °C daha sıcak"* demek yeterlidir.

**⚠️ Bilinen sınırlama — yayma katsayısı (emissivity):** Kızılötesi ölçüm yüzeyin yayma katsayısına
bağlıdır. Cilalı bakırın yayma katsayısı çok düşüktür (~0,03), buna karşılık elektrik klemensleri
yaklaşık 0,60'tır. Bu nedenle **cilalı bakır baraların yüzey sıcaklığı bu yöntemle güvenilir
ölçülemez**; modül, yayma katsayısı uygun olan **klemens bağlantı noktalarını** hedefler ki bu
zaten projenin asıl hedef bölgesidir. Yayma katsayısı sensörün EEPROM'unda tutulmaz, yazılımda
belirtilir (Melexis datasheet §11.2.2.5.4).

### Sıcaklık ve nem — SHT31

**Ne yapar:** Kabin içi havanın sıcaklığını ve bağıl nemini ölçer.

**Neden gerekli:**
- **Referans çizgisi:** Kabinin ısınmasının anormal olup olmadığı ancak dış ortamla karşılaştırılarak
  anlaşılır (§7.1 satır 219). Bu ölçüm olmadan termal dizinin bulduğu sıcak noktanın "yaz günü
  normal" mi "arıza" mı olduğu ayırt edilemez.
- **Yoğuşma ve yalıtım riski:** Nem, ikinci arıza sınıfının (nem yükselmesi) doğrudan ölçümüdür (§7.1).

**Bileşen sınıfı:** −40…+125 °C, I²C, 3.3 V.

### Mikrodenetleyici — ESP32-S3-WROOM-1U-N8

**Ne yapar:** Sensörleri okur, örnekleme takvimini işletir, 768 değerlik termal kareyi özetler,
özet + kareyi paketler ve gönderir. Ayrıca RS-485 hattında Modbus master olarak analizör ve
TVOC-2'yi sorgular.

**`1U` — harici anten konnektörü:** Pano metal bir muhafazadır ve içindeki anten çalışmaz. Antenin
kablo ile panonun dışına çıkarılması gerekir; bu nedenle PCB anteni yerine harici konnektörlü
varyant seçilmiştir (§7.4 satır 296: *"Panodan çıkış: Dış anten"*).

**`N8` — PSRAM'siz varyant, sıcaklık sınıfı nedeniyle zorunlu:** ESP32-S3-WROOM-1U'nun PSRAM'li
varyantları (R8/R16V, Octal SPI PSRAM) **−40…+65 °C** aralığında çalışır; PSRAM'siz varyantlar
**−40…+85 °C**'dir. Karar kaydı bileşenler için −40…+85 °C endüstriyel sınıf şart koştuğundan
(§7.5 satır 318) PSRAM'siz varyant seçilmiştir. 768 değerlik termal kare yaklaşık 3 KB olduğundan
PSRAM'e ihtiyaç yoktur; kısıt ek maliyet getirmez.

**Neden gerekli:** Modül sensörleri kendi takviminde okur, MLX90640'ın 768 ham değerini
kalibre edip özetler, Modbus sorgularını yürütür, `modul_durum`'u (besleme, sinyal) üretir ve
paketi Wi-Fi ile gönderir; bunların hiçbiri pasif bir sensör düğümüyle yapılamaz. Karar kaydı
§7.4 satır 304'teki *"modülün anomaliyi kendi başına tanıması"* şartı entegrasyon kararıyla
kalktı (tam kare her pakette gider; [7. doküman §7.3](07-yazilim-akis.md)); işlemci gereksinimi
bundan bağımsızdır.

### Enerji analizörü / split-core CT — akım kanalı

**İki yol var, ikisi de geçerli:**

| | Panoda analizör varsa | Analizör yoksa |
|---|---|---|
| Yöntem | RS-485 / Modbus okuma | Split-core CT (pense tipi halka) |
| Ek sensör | **Gerekmez** | 4 adet (L1/L2/L3/nötr) |
| Ek kablo | **Gerekmez** — mevcut haberleşme hattı kullanılır | CT başına bağlantı |
| Gerekçe | §7.1 satır 229: *"Panoda analizör varsa akım için yeni sensör ve kablo gerekmez."* | Panoda analizör yoksa |

**Neden bu esneklik önemli:** Brief'in *"yeni eklenecek sensörler kablo kalabalığını kaotik hale
getirebilir"* şikâyetine doğrudan cevaptır. Analizör yolu, panoya **hiçbir yeni sensör eklemeden**
akım kanalını açar.

**Split-core tercihinin sebebi:** Pense gibi açılır, canlı panoya **elektrik kesmeden** takılır.
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

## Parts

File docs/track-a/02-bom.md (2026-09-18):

# 2. Bileşen Listesi (BOM) ve Modül Birim Maliyeti

**Teslimat karşılığı:** T1, T2 · **Değerlendirme kriteri 8** ("maliyet ve sağlanan fayda")
**Dayandığı kararlar:** §7.5 (bileşen sınıfı) · §7.1 (ölçüm kümesi)
**Bağlayıcı şart:** Bileşenler **endüstriyel sıcaklık sınıfı −40…+85 °C** (§7.5 satır 318)

> **Bu bir satın alma listesi DEĞİLDİR.** Hackathon kapsamında fiziksel donanım üretilmez ve
> satın alınmaz (§1.4). Bu tablo, *"bu iş hangi parçalarla yapılır, neden bunlar, ne kadar tutar,
> karşılığında ne kazanılır"* sorusunun cevabıdır. Distribütör adları yalnızca **fiyat ve teknik
> veri kaynağı** olarak geçer.

**Kur:** 1 USD = 48,66 TL (13.09.2026 serbest piyasa satış kuru — doğrulanmış)
**Fiyat tarihi:** 2026-09-14 · Fiyatlar **1 adet** (prototip) içindir.

---

## 2.1 Ana bileşenler

| # | Bileşen | Parça kodu | Adet | Birim $ | Birim ₺ | İşlevi | Sıcaklık sınıfı | Kaynak |
|---|---|---|---|---|---|---|---|---|
| 1 | **Termal dizi** | `MLX90640ESF-BAA-000-TU` | 1 | 28,62 | 1.393 | 32×24 nokta sıcaklık; nokta bazında erken tespit | −40…+85 °C | Mouser |
| 2 | **Mikrodenetleyici + radyo** | `ESP32-S3-WROOM-1U-N8` | 1 | 5,66 | 275 | Okuma, termal özet, paketleme, Modbus master, Wi-Fi/BLE, harici anten | −40…+85 °C | DigiKey |
| 3 | **Sıcaklık + nem** | `SHT31-DIS-B2.5KS` | 1 | 4,50 | 219 | Referans çizgisi + yoğuşma riski | −40…+125 °C | DigiKey |
| 4 | **AC/DC güç modülü** | `RECOM RAC05-05SK/277` | 1 | 10,25 | 499 | 230 V → 5 V, izoleli | −40…+90 °C *(5 V tam yükte +75 °C; +90 °C derating ile — yükümüz %15–40, sınır içi)* | Link Electronics |
| 5a | **Yedek depo — süperkapasitör** | `Eaton HV1030-2R7106-R` (10 F / 2,7 V) **×2 seri** | 2 | ~2,40 | ~117 | 5 F / 5,4 V (4,6 V derate) yedek depo; kesintide birkaç dk | −40…+65 °C; **−40…+85 °C** (2,3 V/hücre derate) | DigiKey / Mouser |
| 5b | **Yedek depo — boost çevirici** | `TPS61099` (WSON-6, 0,7–5,5 V giriş → 4,6 V çıkış) | 1 | ~3,48 | ~169 | Süperkapı 1 V'a kadar sömürür; 4,6 V → D2 → +5 V rayı → LDO. Bobin: **2,2 µH** (datasheet §7.3: L 0,7/2,2/2,86 µH) | −40…+125 °C (TJ) | DigiKey |
| 6 | **Anten + kablo** | Panel tipi harici anten + U.FL pigtail | 1 | ~5,00 | ~243 | Panodan dışarı sinyal | — | DigiKey / Data Alliance |
| 7 | **RS-485 alıcı-verici** | Yarıçift yönlü 3,3 V transceiver (MAX3485 sınıfı) | 1 | ~1,50 | ~73 | Modbus hattı fiziksel katmanı | Endüstriyel sınıf seçilecek | — |
| | | | | **63,81** | **3.105** | **Aktif bileşen ara toplamı** | | |

## 2.2 Destek kalemleri

| # | Kalem | Adet | Birim $ | Birim ₺ | Not |
|---|---|---|---|---|---|
| 8 | PCB (110 × 70 mm, 2 katman) | 1 | ~3,00 | ~146 | Kart yerleşimi: [02-pcb-yerlesimi.svg](02-pcb-yerlesimi.svg) (bkz. 2.2a) |
| 9 | Kutu (IP54, 120 × 80 × 50 mm) | 1 | ~8,00 | ~389 | Nihai ölçü — bkz. [4. doküman](04-mekanik-yerlesim.md) |
| 10 | Kızılötesi açıklık / pencere | 1 | ~3,00 | ~146 | Malzeme kararı [4. doküman](04-mekanik-yerlesim.md) |
| 11 | Klemens, kablo, konnektör | — | ~5,00 | ~243 | |
| 12 | Regülatör + pasif bileşenler | — | ~3,00 | ~146 | |
| | | | **22,00** | **1.071** | **Destek ara toplamı** |

**Fiyat güvenilirliği:** 1–4 ve 7 numaralı kalemler **distribütör liste fiyatıdır** (doğrulanmış).
5, 6 ve 8–12 numaralı kalemler **tahmindir** (~ işaretiyle gösterilmiştir) ve BOM kesinleştirilirken
tedarik araştırması gerektirir.

---

### 2.2a Kart yerleşimi (T2 "PCB/kart yapısı")

PCB yerleşimi — 110 × 70 mm, ön yüzden bakış

*(Fusion 360 modeli `GridUp-PCB.f3d`'den projeksiyon, 1 mm = 8 birim. Ön yüz kutu penceresine bakar: MLX90640, SHT31, LED ve pasifler;
arka yüzde ESP32, RAC05, süperkapasitör (2 × Ø10,5 × 31,5 mm maks. zarf, yatık), boost çevirici, klemensler
(230 V giriş klemensi **3 kutup L/N/PE, 5,08 mm adım → 15,24 mm**, X 84–99,25). 230 V birincil bölge sağ şeritte, ≥ 6 mm creepage
ve yarıkla ayrılmış. Kart kutu içinde (5, 5) mm ofsetlidir. **Koordinat konvansiyonu: model (kutu) koordinatı esas alınır** —
[04-kutu-krokisi.svg](04-kutu-krokisi.svg) ile aynı; SVG çizimleri `y` aşağı olduğu için görüntüde ters görünür. Örnek: MLX90640
kutu koordinatı (55, 37,5), IR pencere (60, 42,5). Hatlar
[03-baglanti-semasi.svg](03-baglanti-semasi.svg) ile aynıdır.)*

---

## 2.3 Modül birim maliyeti

| Senaryo | Birim maliyet | Not |
|---|---|---|
| **Panoda analizör VARSA** (akım Modbus'tan okunur) | **$85,81 ≈ ₺4.175** | CT gerekmez — **hedef senaryo** |
| Panoda analizör YOKSA (4× split-core CT) | $95,41 ≈ ₺4.642 | CT tanesi ~$2,40 (OEM liste fiyatı, düşük güvenilirlik) |

**Ölçek karşılığı (bilgi amaçlı):**

| Ölçek | Tutar |
|---|---|
| Demo (9 modül) | ~$772 ≈ ₺37.575 |
| 100 modül (T5 senaryosu) | ~$8.581 ≈ ₺417.500 |

> **Dikkat — tam sistem maliyeti bundan fazladır.** Bu tablo yalnız **modül** maliyetidir. Saha
> gateway'i, on-prem sunucu ve yazılım altyapısı ayrıca değerlendirilir (İZ C kapsamı). 100 modül
> birden fazla sahaya dağıldığı için saha başına en az bir gateway gerekir (§7.4 satır 306).

---

## 2.4 Maliyet ve sağlanan fayda (kriter 8'in karşılığı)

### Baskın kalem ve neden savunulabilir

**Termal sensör, aktif bileşen maliyetinin %45'i, toplam modül maliyetinin %33'üdür.**
Bu, "tek pahalı parça" eleştirisinin hedefidir — ve cevabı şudur:

| Yaklaşım | Maliyet | Sorun |
|---|---|---|
| **Termal dizi (seçilen)** | 1 sensör, $28,62 | — |
| Nokta sıcaklık sensörleriyle aynı kapsama | Her klemense bir sensör | Onlarca klemens × sensör + her birine kablo → **brief'in "kablo kalabalığı kaotik hale gelir" şikâyeti** (§7.1 satır 229) |
| Ölçüm yok, sadece akım | ~$0 | **Arızanın yerini söyleyemez** — *"akım arttı"* der ama *"hangi klemens"* diyemez |

**Kritik içgörü:** Projenin en yaygın arıza nedeni olan gevşek klemens, **akım sabitken** tek noktada
ısınma olarak kendini gösterir (§7.6 senaryo 1). Akım ölçümü bunu **görmez**. Termal dizi, bu
senaryoyu yakalayan tek ölçümdür. Yani $28,62'lik kalem, projenin **ana iddiasının maliyetidir**;
onu çıkarmak sistemi "akım izleme"ye indirger ve ayırt edici değeri ortadan kaldırır.

### Karşılığında ne kazanılıyor

| Kazanılan | Dayanak |
|---|---|
| Nokta bazında tespit (hangi klemens) | §7.1 satır 227 |
| Akım-sıcaklık korelasyonu: *akım artmadan sıcaklık artıyorsa bağlantı direnci artıyor* | §7.1 satır 228 — projenin en savunulabilir teknik iddiası |
| Kanıt niteliğinde tam kare (operatöre "görsel" kanıt) | §7.4 satır 298 |
| Genişleme payı sayesinde sonradan PD/akustik eklenebilir | §7.1 satır 237 |

### Analizör senaryosunun maliyet etkisi

Panoda **zaten analizör varsa** ($10 tasarruf ve 4 CT bağlantısı ortadan kalkar):

- Akım için **yeni sensör gerekmez** (§7.1 satır 229)
- Panoya **hiçbir yeni kablo** eklenmez — brief'in şikâyetine doğrudan cevap
- Modül kurulumu sadeleşir, montaj süresi kısalır

**Tasarım kararı:** Her iki senaryo da desteklenir; analizör varlığı sahaya göre değişebilir.
Bu esneklik **ek maliyet getirmez** çünkü yazılım aynı ölçüm tipini (`akim_l1`…) farklı kaynaktan
doldurur.

---

## 2.5 Yedek depo bileşen seçimi — **karara bağlandı**

Karar kaydı §7.3 satır 268 seçimi izime bırakmıştır (*"süperkapasitör **veya** küçük hücre"*).
**Seçim: süperkapasitör — Eaton HV serisi, 2 × 10 F seri (5 F / 5,4 V) + boost çevirici.**

### Aday karşılaştırması

| Aday | Sıcaklık aralığı | Sonuç |
|---|---|---|
| Panasonic EECF5R5H105 (1 F / 5,5 V) | **−25…+85 °C** | ✗ −40 °C şartını karşılamıyor |
| Panasonic NF / EEC-S5R5 (1–1,5 F) | −25…+70 °C | ✗ Aynı |
| Kamcap SE serisi | −25…+70 °C | ✗ Aynı |
| Eaton PM serisi (5,0 V / 1 F modül) | −40…+60 °C; genişletilmiş **−40…+85 °C** | △ Ama enerji yetersiz (aşağıya bak) |
| **Eaton HV serisi (2,7 V / 10 F hücre)** | −40…+65 °C; genişletilmiş **−40…+85 °C** | ✓ **Seçildi** |

**Gerçek durum:** *"5,5 V + −40…+85 °C"* kombinasyonu **tek parçada yoktur** — −40 °C'ye inen seriler
+85 °C'de gerilim derating ister. Bu yüzden seçim **enerji bütçesiyle** yapılmıştır.

### Kararı belirleyen hesap

E = ½C(V₁²−V₂²). Yedek modda (`dusuk_guc`) termal dizi ve radyo birlikte beslenemez; yalnızca
*"besleme kaybı"* paketi gönderilir → ~50 mA @ 3,3 V ≈ 165 mW.

> **Float gerilimi — devredeki gerçek değer.** Süperkap **5 V rayından**, `R_şarj = 22 Ω` üzerinden
> şarj olur ve **gerilim sınırlayıcı yoktur**; bu yüzden float gerilimi raya yaklaşır:
> 5 V − D1 (Schottky) ≈ **4,7 V**. Dolayısıyla **5,4 V (2S anma) ile hesaplanan 70 J devrede
> ulaşılamaz** — gerçekçi üst sınır **≈4,7 V ≈ 52 J ≈ ~5 dk**'dır. Tablonun ikinci satırı
> (+85 °C derate, 4,6 V → 50 J) bu gerçeğe zaten yakındır ve **kararın dayanağı odur**.

| Senaryo | Kullanılabilir enerji | 50 mA'da süre |
|---|---|---|
| ~~HV 2×10 F (5 F / 5,4 V) + boost~~ *(devrede ulaşılmaz — float 4,7 V)* | ~~70 J~~ | ~~~7 dk~~ |
| **HV 2×10 F, 4,7 V float (D1 sonrası ray) + boost** | **≈53 J** | **~5,3 dk** |
| **HV 2×10 F, +85 °C derate (4,6 V) + boost** | **50 J** | **~5 dk** |
| HV 2×10 F + LDO (3,6 V'ta durur) | 23 J *(4,7 V float)* | ~2,3 dk |
| Eaton PM 1 F + LDO | 8 J | ~50 sn |
| **Eaton PM 1 F, +85 °C derate (3,9 V) + LDO** | **1 J** | **~7 sn** ✗ |

**Üç sonuç:**
1. **HV, PM'den ~8,7× fazla enerji verir** — hücre voltajı 2,7 V olduğu için seri bağlandığında
   tüm pencere kullanılır; PM'in 5,4 V'lik modülü 3,6 V LDO dropout'una kadar iner.
2. **Boost şart:** LDO 3,6 V'ta dururken (~30 J, ≈90 sn) çöpe gider; boost süperkapı **1 V'a
   kadar** sömürür → **%74 daha fazla enerji** (4,7 V float'ta 23 J → 53 J).
3. **PM'in derating senaryosu çöker:** +85 °C'de PM 3,9 V'a derate olur, 3,6 V dropout'u kalır →
   pencere **0,3 V** → **~7 saniye.** Alarm paketini bile gönderemez. Bu, kararı tek başına verir.

**Karar kaydı §7.3 uyumu:** *"besleme kesildiğinde birkaç dakika yaşayıp 'besleme kaybı' alarmını
gönderebilmek"* — hedef 3–5 dk ≈ 30–50 J. Gerçek devre koşullarında (4,7 V float) HV + boost
**≈53 J ≈ 5,3 dk**; +85 °C'de **50 J ≈ 5 dk** — **karşılıyor**. PM 1 F (**8 J / 1 J**)
**karşılamıyor**.

**Ömür notu:** Ömür sürekli çalışma üzerinden hesaplanmaz — *"yılda kaç kesinti × birkaç dakika"*
üzerinden hesaplanır. Float durumda bekleyen depo, panonun bakım periyodundan uzun ömür verir
(§7.3 satır 282). Veri sayfası ömrü **1000 saat @ 65 °C** (tam anma geriliminde); bizim kullanım
(float + seyrek deşarj + derate) bunun çok altında.

**Kod tarafı etkisi:** Yok. `modul_durum.besleme` alanı `sebeke` | `yedek` değerlerini taşır; hangi
depo teknolojisinin kullanıldığı sözleşmeye yansımaz.

---

## 2.6 ⚠️ Tespit edilen kısıtlar (dokümana gerekçe olarak girecek)

| # | Kısıt | Sonuç |
|---|---|---|
| 1 | **MCU'nun PSRAM'li varyantı −40…+65 °C** — PSRAM'siz varyant −40…+85 °C | −40…+85 °C şartı için **PSRAM'siz N8 zorunlu**. Kısıt bedava: 768 değerlik kare ~3 KB, PSRAM gereksiz |
| 2 | **Standart 230 V AC/DC modüller −25 °C'de başlıyor** (RECOM RAC02, Mornsun LD03, Hi-Link HLK-PM01) | −40 °C için **277 VAC serisi** (RAC05-K/277, −40…+90 °C — 5 V tam yükte +75 °C, +90 °C derating ile) seçildi. Gerekçe dokümanda yazılır |
| 3 | **"5,5 V + −40…+85 °C" süperkapasitör yok** | Bkz. 2.5 — **HV serisi 2×10 F + boost** seçildi; enerji bütçesiyle gerekçelendi |
| 4 | **Termal sensör −40…+85 °C hedef sıcaklık −40…+300 °C** | ✓ Şartı karşılıyor |
| 5 | **Tedarik süresi:** MLX90640 Mouser'da *non-stocked*, **12–16 hafta** | Prototip üretimi planlanırsa erken sipariş gerekir. **Hackathon'u etkilemez** (fiziksel donanım üretilmiyor) |

---

## 2.7 Bileşen seçiminin gerekçeleri (özet)

| Bileşen | Neden bu | Reddedilen alternatif |
|---|---|---|
| **MLX90640 (110°×75°)** | Gerçek montaj derinliğinde (377 mm plaka / 155,5 mm NH yüzü) kapsama 1077 × 579 ve 444 × 239 mm; 32×24 = nokta başına ~3,4×2,4 cm (plaka) ve 1,4×1,0 cm (NH — klemens adımından küçük, nokta bazında tespit); −40…+85 °C | Dar açılı 55° varyant: 377 mm'de ~39×24 cm görür, klemens sırasını kapsamaz |
| **ESP32-S3-WROOM-1U-N8** | Harici anten konnektörü (`1U`) + −40…+85 °C (`N8`, PSRAM'siz); Wi-Fi/BLE dahili; I²C/UART/ADC mevcut | PSRAM'li varyant: −40…+65 °C'de kalır. PCB antenli varyant: metal panoda çalışmaz |
| **SHT31** | −40…+125 °C (ihtiyacın üzerinde), ±0,2 °C, I²C | — |
| **RECOM RAC05-05SK/277** | −40…+90 °C şartını karşılayan tek makul modül; 4,2 kVAC izolasyon; encapsulated | **5 V çıkışta tam yükte −40…+75 °C**; +90 °C'ye **yalnız derating grafiğiyle** (düşük yükte) çıkılır — bizim yük %15–40, sınır içinde. Standart 230 V modüller −25 °C'de başlar |
| **Süperkapasitör** | Float şarjlı bekler, döngü yükü yok, bakım yükü ~0 | **Ana kaynak olarak pil:** reddedildi — bakım gerektirir, termal dizi tüketimi pil ömrünü aylara indirir (§7.3 satır 280) |
| **Analizör okuma (varsa)** | Panoya yeni sensör/kablo eklemez — brief'in kablo kalabalığı şikâyetine cevap | Split-core CT: analizör yoksa kullanılır, pense tipi olduğu için kesintisiz takılır |
| **TVOC-2 okuma** | Ark algılama SIL-2 sertifikasyonu gerektirir; ark erken uyarıya uygun değil | Kendi ark dedektörümüzü yapmak: sertifikasyon + milisaniye ölçeği nedeniyle mümkün değil |

---

## 2.8 Sözleşmeye bağlılık kontrolü

- [x] Tüm bileşenler −40…+85 °C endüstriyel sınıfta mı (istisnalar gerekçeli mi)? → 2.5'te bir istisna var, gerekçeli
- [x] Ölçüm tipleri `olcum_tipi` enum'ıyla uyumlu mu? → [1. doküman §1.4](01-blok-sema.md)
- [x] `modul_durum.besleme` alanı `sebeke`/`yedek` değerlerini üretebiliyor mu? → Evet (süperkapasitör)
- [x] Genişleme payı hem donanımda hem BOM'da mı? → Ayrılmış pinler var, ek parça gerekmiyor
- [x] Anten panodan dışarı çıkabiliyor mu? → Evet, mevcut kablo girişi + U.FL pigtail

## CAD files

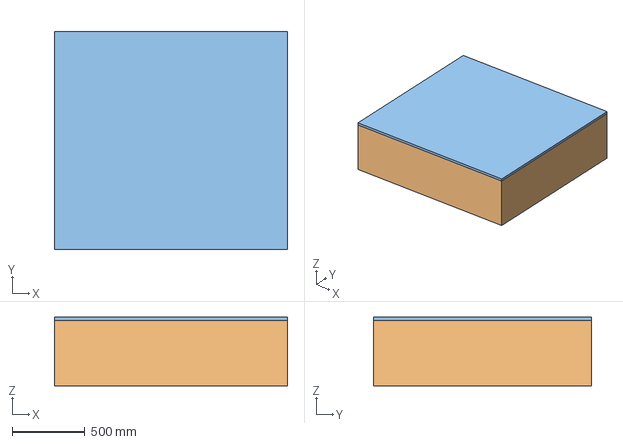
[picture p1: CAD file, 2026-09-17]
docs/track-a/cad/GridUp-Pano.step
1600.0 x 1500.0 x 472.0 mm

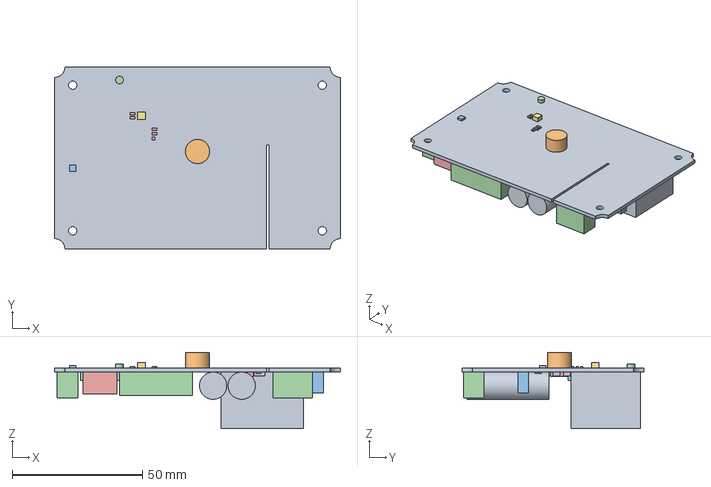
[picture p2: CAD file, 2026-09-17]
docs/track-a/cad/GridUp-PCB.step
110.0 x 70.0 x 29.4 mm

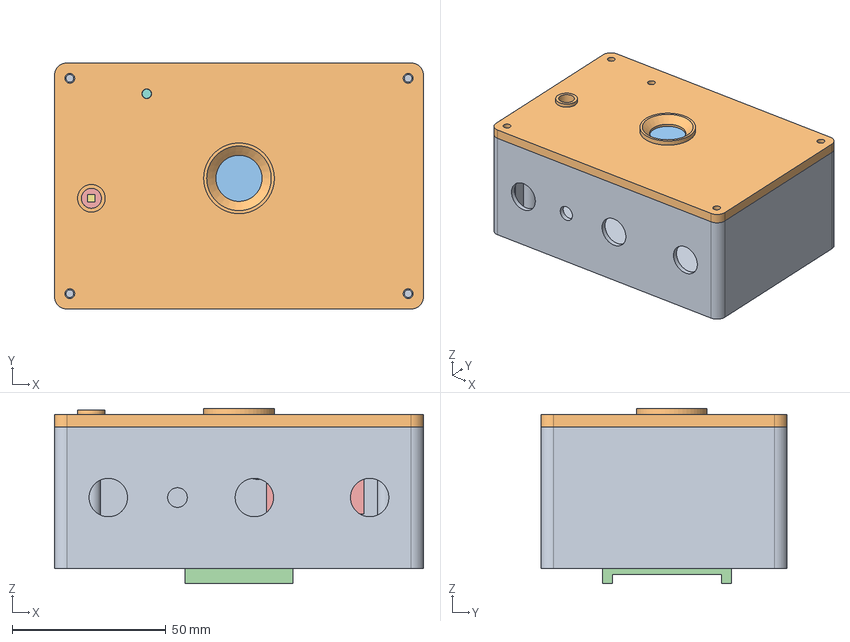
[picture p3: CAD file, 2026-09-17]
docs/track-a/cad/GridUp-Kutu-Montaj.step
120.0 x 80.0 x 57.0 mm

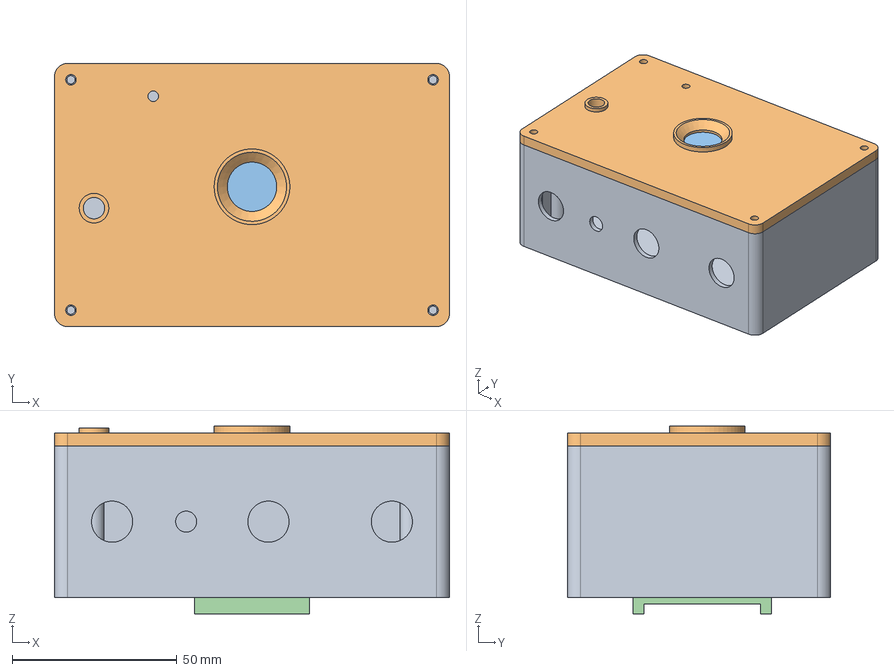
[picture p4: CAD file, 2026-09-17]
docs/track-a/cad/GridUp-Kutu.step
120.0 x 80.0 x 57.0 mm

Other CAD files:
docs/track-a/cad/GridUp-Kutu-Montaj.f3d
docs/track-a/cad/GridUp-Kutu.f3d
docs/track-a/cad/GridUp-PCB.f3d
docs/track-a/cad/GridUp-Pano.f3d

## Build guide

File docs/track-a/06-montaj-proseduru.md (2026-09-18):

# 6. Montaj Prosedürü

**Teslimat karşılığı:** T1 · **Değerlendirme kriteri 3** ("saha koşullarında uygulanabilirlik")
**Dayandığı kararlar:** §7.5 satır 341–351 (birebir 7 adım)
**Bağlayıcı şart:** Yedi adım, **kesinti yok** gerekçesi, tek teknisyen **~15–20 dakika**

---

## 6.0 Adım akışı

Montaj adımları — 7 adım, kesinti yok, tek teknisyen

*(Adım 1 ve 7 vurgulu: 1 = abonelere elektrik kesilmez, 7 = sessiz körlüğü önleyen zorunlu doğrulama.
Adım süreleri tahminidir; toplam ~15–20 dk.)*

---

## 6.1 Prosedür (karar kaydı satır 343–349, birebir)

§7.5 montaj prosedürünü yedi adım olarak sabitlemiştir. Aşağıda her adım, **sahada ne anlama
geldiği** ve **hangi riskin karşılandığı** ile birlikte verilmiştir.

| # | Adım | Sahada ne yapılır | Karşılanan risk |
|---|---|---|---|
| **1** | **Yardımcı devre sigortası çekilir** | Pano iç ihtiyaç devresinin sigortası çekilir. **Abonelere giden elektrik kesilmez.** | İş güvenliği + müşteri kesintisi önlenir |
| **2** | **Pano kapağı açılır** | Ön kapak açılır; iç klemens sıraları ve kablo yönlendirme alanı erişilebilir hale gelir | Fiziksel erişim |
| **3** | **Modül konumlandırılır, klemens sırasına hizalanır** | Modül, termal sensör klemenslere **dik bakacak** şekilde konumlandırılır; kadraj ayarı yapılır | Görüş hattı bütünlüğü (sessiz körlük) |
| **4** | **Besleme kablosu iç ihtiyaç klemensine bağlanır** | 230 V besleme, iç ihtiyaç devresinin klemensine bağlanır; PE panonun koruma iletkenine. Panoda analizör varsa RS-485 A/B çifti de bu adımda analizörün Modbus klemensine bağlanır (pano içi, kısa) | Enerji kaynağı (§7.3) |
| **5** | **Anten kablosu mevcut kablo giriş noktasından dışarı çıkarılır, anten dışa monte edilir** | U.FL pigtail panonun mevcut kablo girişinden geçirilir; panel anteni **dışa** monte edilir | Metal pano radyo kesintisi (sessiz arıza) |
| **6** | **Sigorta takılır, modül gateway'e kaydolur** | Yardımcı devre sigortası geri takılır; modül önyüklenip saha gateway'ine bağlanır. Kapaktaki durum LED'i (02 kart yerleşimi) gateway bağlantısı kurulunca sabit yeşil yanar; ilk paket merkeze `modul_id` ile düşer | Devreye alma |
| **7** | **Ekrandan kapsama doğrulanır** | Termal kadraj ekrandan kontrol edilir: klemens sırası görüş alanında mı? | **Montaj hatasının yakalanması** |

**Süre ve işgücü (satır 351, birebir):**
> **Tek teknisyen, ~15–20 dakika, kesinti yok.**

---

## 6.2 Neden kesintisiz — bu tasarımın ayırt edici iddiası

**Adım 1'in kritik yanı:** Yalnızca **yardımcı devrenin** sigortası çekilir. Abonelere giden
elektrik **kesilmez** (§7.3 satır 273).

**Şartname dayanağı:** TEDAŞ şartnamesinde panoda **üç ayrı yardımcı devre** tanımlıdır ve her
birinin **kendi sigortası** vardır (§7.3 satır 271):

| Yardımcı devre | Anma akımı | İşletme sınıfı |
|---|---|---|
| T.M. iç ihtiyaç devresi | 20 A | gG |
| İç ihtiyaç devresi | 6 A | gG |
| Ölçü devresi | 2 A | gG |

**Emsal — bu zaten yapılan bir şey:** Şartname panoda **modem kullanılabileceğini** belirtir ve
teknik çizimde **`Modem` kutusu** görünür (§2.2 not + EK-II/14 çizimi). Yani **iç ihtiyaç
devresinden beslenen bir haberleşme cihazı için mevcut ve kabul görmüş bir emsal vardır**
(§7.3 satır 271). Bu, jüriye verilecek en güçlü saha uygulanabilirliği cevabıdır.

**Neden bu kadar önemli:** Kesinti gerektiren bir kurulum, 5000 panoluk yaygınlaştırmada
savunulamaz — her panoyu ziyaret etmek ve müşteriyi kesmek gerekir. **Kesintisiz montaj**, projenin
ölçeklenebilirlik iddiasının (**T5**) ön koşuludur.

---

## 6.3 Adım 7 neden zorunlu — "sessiz körlük" riski

Adım 7, "iyi olur" değil **zorunlu** bir adımdır. Gerekçe §7.5 satır 335'te:

> *"termal sensörün değeri **nişan almasına** bağlıdır. Birkaç santim kayma veya hafif dönme,
> izlenen klemens sırasını kadraj dışına çıkarır ve sistem **sessizce kör olur** — fark edilmesi
> en zor arıza türü."*

**Bu neden en tehlikeli arıza türü:** Sistem çalışıyor görünür — veri akar, paketler gelir, arayüz
yeşil. Ama termal dizi artık klemenslere değil, panonun boş bir duvarına bakıyordur. Sonuç:
en önemli ölçüm kanalı **sessizce ölür** ve kimse fark etmez.

**Doğrulama yöntemi (Adım 7):** Montaj sırasında ekrandan termal görüntü canlı izlenir ve
klemens sırasının kapsama alanı içinde olduğu **teyit edilir**. Kapsama dışındaysa modül kaydırılır.

> **Not:** Bu, sistemin genel "sessizce ölmeme" felsefesiyle aynı çizgidedir — §7.6 senaryo 6
> (`sensor_arizasi`) ve senaryo 7 (`modul_saglik`) de aynı ilkeyi taşır: *sistemimiz sessizce
> ölmez* diyebilmek.

---

## 6.4 Montaj öncesi kontrol listesi

- [ ] Doğru yardımcı devre sigortası tespit edildi mi (20 A / 6 A / 2 A — hangisi kullanılacak)?
- [ ] Abonelere giden besleme çıkışlarının kesilmeyeceği teyit edildi mi?
- [ ] Modül konumu klemens sırasına **dik** olacak şekilde belirlendi mi?
- [ ] Güçlü mıknatıs akım trafolarından uzak mı (§7.5 satır 337)?
- [ ] Anten kablosu için **menteşe yakınında kıvrım payı** planlandı mı?
- [ ] Sabitleme **yeni delik açmadan** yapılabiliyor mu (DIN rayı / mevcut cıvata / kapak çerçevesi)?

## 6.5 Montaj sonrası kontrol listesi

- [ ] Modül saha gateway'ine kaydoldu mu (Adım 6)?
- [ ] **Termal kadraj doğrulandı mı** — klemens sırası görüş alanında mı (Adım 7)?
- [ ] Ortam sıcaklık/nem ölçümleri geliyor mu?
- [ ] Akım kanalı veri üretiyor mu (analizör Modbus veya CT)?
- [ ] `modul_durum` alanları anlamlı mı (`besleme: sebeke`, `sinyal` makul dBm aralığında)?
- [ ] Anten dışa monte edildi ve sinyal gücü yeterli mi?
- [ ] Kapak kapatıldığında kablolar sıkışmıyor mu?

---

## 6.6 Kapsam dışı

- Panonun enerjisiz bırakılması gerektiren işler — bu prosedür **kesintisiz** çalışır
- Yüksekte çalışma / iskele gerektiren özel kurulum — referans pano zemin tipidir
- Saha gateway'i kurulumu — İZ C kapsamı (§7.4)

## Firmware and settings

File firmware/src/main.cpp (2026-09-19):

// Grid-Up İZ A — pano içi modül firmware iskeleti (ESP32-S3-WROOM-1U-N8).
//
// Bu dosya modul-sim/modul_sim/modul.py'deki `Modul.ilerle()` akışının C++ karşılığıdır:
// aynı dokuz adım, aynı sırayla, aynı sabitlerle (include/ayar.h ↔ ayar.py). Simülatörde
// "dünya" ve "senaryo" sentetik olarak üretilir (adım 1–2); sahada fiziksel dünya okunur,
// o iki adım burada sensör okumasının içinde erir. Akış diyagramı: docs/track-a/07 §7.1.
//
// Politika (entegrasyon kararı madde 2, entegrasyon-gorev-dagilimi.md §2.4): her 30 sn'de
// bir paket; termal özet + 768 değerlik tam kare her ölçüm çevriminde, modül içi eşik yok.
// Tek istisna düşük güç modu (yedekte ≥ 3 dk): ölçüm çevrimi yapılmaz, yalnız modul_durum
// kalp atışı gider; modul.py adım 7 `if not b.dusuk_guc` ile aynı. Modül hüküm vermez;
// pakette seviye/tip yoktur (07 §7.4).
//
// Durum: PlatformIO'da derlenir. Fiziksel modül üretilmediği için (karar kaydı §1.4) donanım
// üzerinde doğrulanmadı; sensör sürücüleri üretici kütüphaneleri, Modbus register adresleri
// ayar.h'de varsayım olarak işaretli.

#include <Arduino.h>
#include <Wire.h>
#include <WiFi.h>
#include <HTTPClient.h>
#include <Adafruit_MLX90640.h>
#include <Adafruit_SHT31.h>
#include <ModbusMaster.h>
#include <time.h>
#include <math.h>

#include "ayar.h"
#include "pinler.h"

// ---------------------------------------------------------------------------
// Donanım nesneleri
// ---------------------------------------------------------------------------

static Adafruit_MLX90640 termalDizi;
static Adafruit_SHT31 kabinSensoru;
// Tek ModbusMaster örneği: RS-485 tek master, yarım dubleks; analizör ve TVOC-2 aynı hattan
// sırayla sorgulanır, `begin()` yalnız slave adresini değiştirir. Eşzamanlı sorgu tasarımda yok.
static ModbusMaster modbus;

static bool termalHazir = false;
static bool kabinHazir = false;

// ---------------------------------------------------------------------------
// Modül durumu (adım 9'un girdileri)
// ---------------------------------------------------------------------------

static uint32_t cevrimSayaci = 0;          // Modul._sayac
static uint32_t arkSayaci = 0;             // Modul._ark_sayaci: TVOC-2 kümülatif trip
static uint32_t sonTvocTrip = 0;
static bool arkBekleyen = false;           // trip görüldü ama paket gönderilemedi: satır sonraki pakete
static bool yedekte = false;               // şebeke kaybı görüldü mü
static uint32_t yedekBaslangicMs = 0;      // kaybın görüldüğü an (yedekte iken anlamlı)
static char yazBuf[20 * 1024];             // paket JSON'u (768 değer ≈ 5–6 KB)

// ---------------------------------------------------------------------------
// Yardımcılar
// ---------------------------------------------------------------------------

static float kirp(float v, float alt, float ust) {
    return v < alt ? alt : (v > ust ? ust : v);
}

static float yuvarla2(float v) { return roundf(v * 100.0f) / 100.0f; }

// UTC ISO 8601, literal Z (sözleşme ①/②). Saat SNTP ile kurulur; kurulmadıysa false.
static bool zamanYaz(char* hedef, size_t n) {
    time_t simdi;
    time(&simdi);
    struct tm t;
    gmtime_r(&simdi, &t);
    if (t.tm_year + 1900 < 2020) return false;   // SNTP henüz gelmedi
    strftime(hedef, n, "%Y-%m-%dT%H:%M:%SZ", &t);
    return true;
}

// Modbus yön pini: MAX3485 DE/RE, TX sırasında HIGH (03 §3.3).
static void modbusOnce() { digitalWrite(PIN_DE_RE, HIGH); }
static void modbusSonra() { digitalWrite(PIN_DE_RE, LOW); }

// ---------------------------------------------------------------------------
// Adım 3 — akım: CT ön ucu (analizör yoksa) veya Modbus analizör (varsa)
// ---------------------------------------------------------------------------

// Bir CT kanalının RMS akımı. V_bias etrafında salınan burden gerilimi 100 ms boyunca
// 2 kHz'de örneklenir, ortalama (bias) çıkarılır, RMS alınır, burden ve CT oranıyla ampere çevrilir.
static float ctRmsAmper(int pin) {
    const uint32_t bitis = millis() + CT_ORNEK_SURE_MS;
    double toplam = 0.0, kareToplam = 0.0;
    uint32_t n = 0;
    while (millis() < bitis) {
        const float mv = (float)analogReadMilliVolts(pin);
        toplam += mv;
        kareToplam += (double)mv * mv;
        n++;
        delayMicroseconds(CT_ORNEK_ARALIK_US);
    }
    if (n == 0) return NAN;
    const double ort = toplam / n;
    const double varyans = kareToplam / n - ort * ort;
    const float vrms = (float)sqrt(varyans > 0 ? varyans : 0) / 1000.0f;  // V
    return vrms / R_BURDEN_OHM * CT_ORAN;
}

struct Akimlar { float l1, l2, l3, notr; bool gecerli; };

static Akimlar akimOku() {
    Akimlar a{NAN, NAN, NAN, NAN, false};
    if (ANALIZOR_VAR) {
        modbus.begin(ANALIZOR_ADRES, Serial1);
        if (modbus.readHoldingRegisters(ANALIZOR_REG_AKIM_L1, 4) == modbus.ku8MBSuccess) {
            a.l1 = modbus.getResponseBuffer(0) * ANALIZOR_AKIM_CARPAN;
            a.l2 = modbus.getResponseBuffer(1) * ANALIZOR_AKIM_CARPAN;
            a.l3 = modbus.getResponseBuffer(2) * ANALIZOR_AKIM_CARPAN;
            a.notr = modbus.getResponseBuffer(3) * ANALIZOR_AKIM_CARPAN;
            a.gecerli = true;
        }
        return a;
    }
    a.l1 = ctRmsAmper(PIN_CT_L1);
    a.l2 = ctRmsAmper(PIN_CT_L2);
    a.l3 = ctRmsAmper(PIN_CT_L3);
    a.notr = ctRmsAmper(PIN_CT_N);
    a.gecerli = !(isnan(a.l1) || isnan(a.l2) || isnan(a.l3) || isnan(a.notr));
    return a;
}

// ---------------------------------------------------------------------------
// Adım 5 — ark sayacı: TVOC-2 sayar, biz okuruz (§7.1 satır 230). Tespit yok.
// ---------------------------------------------------------------------------

static uint32_t arkTetikOku() {
    if (!TVOC2_VAR) return 0;
    modbus.begin(TVOC2_ADRES, Serial1);
    if (modbus.readHoldingRegisters(TVOC2_REG_TRIP, 1) != modbus.ku8MBSuccess) return 0;
    const uint32_t simdiki = modbus.getResponseBuffer(0);
    const uint32_t fark = simdiki >= sonTvocTrip ? simdiki - sonTvocTrip : 0;
    sonTvocTrip = simdiki;
    return fark;
}

// ---------------------------------------------------------------------------
// Adım 7 — termal: 5 alt kare ortalaması, yuvarlama özetten ÖNCE (modul.py ile aynı sebep:
// toplayıcı maks_konum'un aldığı karenin en sıcak pikselini gösterdiğini doğrular).
// ---------------------------------------------------------------------------

static float kareToplam[TERMAL_PIKSEL];
static float kare[TERMAL_PIKSEL];
static float altKare[TERMAL_PIKSEL];
static uint32_t altKareSayisi = 0;

static void termalAltKareEkle() {
    if (!termalHazir) return;
    if (termalDizi.getFrame(altKare) != 0) return;   // okuma hatası: bu alt kare atlanır
    for (int i = 0; i < TERMAL_PIKSEL; i++) kareToplam[i] += altKare[i];
    altKareSayisi++;
}

struct TermalOzet { float maks; int sutun, satir; float bolge[4]; float ortalama; };

static bool termalKareBitir(TermalOzet& o) {
    if (altKareSayisi == 0) return false;
    int maksIdx = 0;
    double toplam = 0, bolgeToplam[4] = {0, 0, 0, 0};
    int bolgeSayi[4] = {0, 0, 0, 0};
    for (int i = 0; i < TERMAL_PIKSEL; i++) {
        kare[i] = yuvarla2(kirp(kareToplam[i] / altKareSayisi, ARALIK_TERMAL_MIN, ARALIK_TERMAL_MAX));
        if (kare[i] > kare[maksIdx]) maksIdx = i;
        toplam += kare[i];
        const int c = i % TERMAL_SUTUN, s = i / TERMAL_SUTUN;
        const int b = (s < TERMAL_SATIR / 2 ? 0 : 2) + (c < TERMAL_SUTUN / 2 ? 0 : 1);  // sol-üst, sağ-üst, sol-alt, sağ-alt
        bolgeToplam[b] += kare[i];
        bolgeSayi[b]++;
    }
    o.maks = kare[maksIdx];
    o.sutun = maksIdx % TERMAL_SUTUN;
    o.satir = maksIdx / TERMAL_SUTUN;
    for (int b = 0; b < 4; b++) o.bolge[b] = yuvarla2((float)(bolgeToplam[b] / bolgeSayi[b]));
    o.ortalama = (float)(toplam / TERMAL_PIKSEL);
    return true;
}

// ---------------------------------------------------------------------------
// Adım 9 — modül sağlığı
// ---------------------------------------------------------------------------

static bool sebekedeMi() {
    const float vsense = analogReadMilliVolts(PIN_VSENSE) / 1000.0f;
    return vsense / VSENSE_BOLUCU >= SEBEKE_ESIK_V;
}

// ---------------------------------------------------------------------------
// Paket kurma — sözleşme ② JSON'u, kütüphanesiz (sabit biçim, %.2f)
// ---------------------------------------------------------------------------

struct Yazici {
    char* p; size_t kalan; bool tasti;
    // vsnprintf `kalan` > 0 iken her zaman NUL yazar; sığmayan parça atılır ve `tasti`
    // işaretlenir, kesik JSON gönderilmez (tampon 20 KB, en kötü paket ~7 KB).
    void yaz(const char* fmt, ...) {
        va_list ap; va_start(ap, fmt);
        const int n = vsnprintf(p, kalan, fmt, ap);
        va_end(ap);
        if (n < 0 || (size_t)n >= kalan) { tasti = true; return; }
        p += n; kalan -= n;
    }
};

static void olcumSatiri(Yazici& y, bool& ilk, const char* tip, float deger, const char* birim,
                        const char* zaman, const char* kalite) {
    y.yaz("%s{\"modul_id\":\"%s\",\"zaman\":\"%s\",\"olcum_tipi\":\"%s\",", ilk ? "" : ",", MODUL_ID, zaman, tip);
    if (strcmp(kalite, "yok") == 0) y.yaz("\"deger\":null,");   // yalnız kalite=yok null taşır
    else y.yaz("\"deger\":%.2f,", (double)deger);
    y.yaz("\"birim\":\"%s\",\"kalite\":\"%s\"}", birim, kalite);
    ilk = false;
}

// ---------------------------------------------------------------------------
// setup / loop
// ---------------------------------------------------------------------------

void setup() {
    Serial.begin(115200);
    pinMode(PIN_DE_RE, OUTPUT);
    digitalWrite(PIN_DE_RE, LOW);
    analogReadResolution(12);

    // I²C bus: MLX90640 (0x33) + SHT31 (0x44), 400 kHz (03 §3.2)
    Wire.begin(PIN_SDA, PIN_SCL, I2C_HIZ_HZ);
    kabinHazir = kabinSensoru.begin(I2C_ADRES_SHT);
    termalHazir = termalDizi.begin(I2C_ADRES_MLX, &Wire);
    if (termalHazir) {
        termalDizi.setMode(MLX90640_CHESS);
        termalDizi.setResolution(MLX90640_ADC_18BIT);
        termalDizi.setRefreshRate(MLX90640_2_HZ);
    }
    Serial.printf("sensorler: MLX90640 %s, SHT31 %s\n", termalHazir ? "ok" : "YOK", kabinHazir ? "ok" : "YOK");

    // Modbus RTU: UART1 ↔ MAX3485 (03 §3.3)
    Serial1.begin(MODBUS_BAUD, SERIAL_8N1, PIN_UART_RX, PIN_UART_TX);
    modbus.preTransmission(modbusOnce);
    modbus.postTransmission(modbusSonra);

    // Radyo: dış anten (1U), saha gateway'inin Wi-Fi'ı (§7.4)
    WiFi.mode(WIFI_STA);
    WiFi.begin(WIFI_SSID, WIFI_SIFRE);
    for (int i = 0; i < 40 && WiFi.status() != WL_CONNECTED; i++) delay(250);
    Serial.printf("wifi: %s\n", WiFi.status() == WL_CONNECTED ? WiFi.localIP().toString().c_str() : "bagli degil");

    // Saat: UTC, SNTP. `zaman` modülün saatidir; toplayıcı `alindi_zaman` ekler (§11).
    configTime(0, 0, NTP_SUNUCU);
}

void loop() {
    const uint32_t cevrimBaslangic = millis();
    cevrimSayaci++;

    // ---- adım 9'un girdisi erken okunur: besleme durumu düşük güç kararını belirler ----
    const bool sebeke = sebekedeMi();
    if (sebeke) yedekte = false;
    else if (!yedekte) { yedekte = true; yedekBaslangicMs = millis(); }
    // Süperkap gerilimi ölçülmüyor; bütçe zamanla: 3 dk yedekten sonra yalnız kalp atışı
    // (07 §7.6: "termal dizi ile radyo aynı anda karşılanamaz").
    const bool dusukGuc = !sebeke && (millis() - yedekBaslangicMs) / 1000 >= YEDEK_DUSUK_GUC_S;
    if (!sebeke) WiFi.setTxPower(WIFI_POWER_8_5dBm);   // yedekte verici kısılır (modul.py: sinyal −4 dBm)
    else WiFi.setTxPower(WIFI_POWER_19_5dBm);

    // ---- adım 1–2: dünya ve senaryo — sahada fiziksel, aşağıdaki okumaların içinde ----

    // ---- adım 3 + 7: 30 sn pencere; her 2 sn akım alt örneği, her 6 sn termal alt kare ----
    double l1 = 0, l2 = 0, l3 = 0, notr = 0;
    uint32_t akimN = 0;
    for (int i = 0; i < TERMAL_PIKSEL; i++) kareToplam[i] = 0;
    altKareSayisi = 0;

    for (uint32_t alt = 0; alt < ALT_ADIM; alt++) {
        const uint32_t altBaslangic = millis();
        if (!dusukGuc) {
            const Akimlar a = akimOku();
            if (a.gecerli) { l1 += a.l1; l2 += a.l2; l3 += a.l3; notr += a.notr; akimN++; }
            if (alt % TERMAL_HER_N_ALT_ADIM == 0) termalAltKareEkle();   // alt 0,3,6,9,12 → 5 kare
        }
        // alt adımı 2 sn'ye tamamla (CT 4 × 100 ms + I²C okumaları ≈ 0,5 s sığar; yalnız
        // analizör Modbus zaman aşımı (ModbusMaster 2 s) alt adımı aşabilir → çevrim uzar,
        // toplayıcı bunu `zaman` aralığından görür)
        const uint32_t gecen = millis() - altBaslangic;
        if (gecen < AKIM_OKUMA_S * 1000) delay(AKIM_OKUMA_S * 1000 - gecen);
    }
    const bool akimGecerli = akimN > 0;
    if (akimGecerli) { l1 /= akimN; l2 /= akimN; l3 /= akimN; notr /= akimN; }

    // ---- adım 4: kabin havası ----
    float kabinC = NAN, kabinNem = NAN;
    if (!dusukGuc && kabinHazir) {
        kabinC = kabinSensoru.readTemperature();
        kabinNem = kabinSensoru.readHumidity();
    }

    // ---- adım 5: ark sayacı (olay bazlı, periyot yok) ----
    const uint32_t arkTetik = arkTetikOku();
    if (arkTetik) { arkSayaci = min<uint32_t>(arkSayaci + arkTetik, 1000); arkBekleyen = true; }

    // ---- adım 6: modülün saati ----
    char zaman[24];
    if (!zamanYaz(zaman, sizeof zaman)) {
        // sözleşme `zaman` ister; uydurulmaz. Wi-Fi yoksa SNTP de gelmez: bağlantıyı dene.
        Serial.println("zaman: SNTP yok, paket atlandi");
        if (WiFi.status() != WL_CONNECTED) WiFi.reconnect();
        return;
    }

    // ---- adım 7 (devam): kare + özet ----
    TermalOzet ozet{};
    const bool termalVar = !dusukGuc && termalKareBitir(ozet);

    // ---- adım 8: ölçüm satırları (sözleşme ①) ----
    Yazici y{yazBuf, sizeof yazBuf, false};
    y.yaz("{\"modul_id\":\"%s\",\"zaman\":\"%s\",\"olcumler\":[", MODUL_ID, zaman);
    bool ilk = true;
    if (!dusukGuc) {
        const char* akimKalite = akimGecerli ? "iyi" : "yok";
        olcumSatiri(y, ilk, "akim_l1", kirp((float)l1, ARALIK_AKIM_MIN, ARALIK_AKIM_MAX), "A", zaman, akimKalite);
        olcumSatiri(y, ilk, "akim_l2", kirp((float)l2, ARALIK_AKIM_MIN, ARALIK_AKIM_MAX), "A", zaman, akimKalite);
        olcumSatiri(y, ilk, "akim_l3", kirp((float)l3, ARALIK_AKIM_MIN, ARALIK_AKIM_MAX), "A", zaman, akimKalite);
        olcumSatiri(y, ilk, "akim_notr", kirp((float)notr, ARALIK_AKIM_MIN, ARALIK_AKIM_MAX), "A", zaman, akimKalite);
        if (termalVar) {
            olcumSatiri(y, ilk, "termal_maks", ozet.maks, "C", zaman, "iyi");
            olcumSatiri(y, ilk, "termal_ort", kirp(ozet.ortalama, ARALIK_TERMAL_MIN, ARALIK_TERMAL_MAX), "C", zaman, "iyi");
        }
        if (cevrimSayaci % CEVRE_CEVRIM == 0) {   // 60 sn'de bir
            const bool kabinOk = kabinHazir && !isnan(kabinC) && !isnan(kabinNem);
            // okuma yoksa değer null gider (kalite yok); NaN hiçbir yere sokulmaz
            olcumSatiri(y, ilk, "ortam_sicaklik", kabinOk ? kirp(kabinC, ARALIK_SICAKLIK_MIN, ARALIK_SICAKLIK_MAX) : 0.0f, "C", zaman, kabinOk ? "iyi" : "yok");
            olcumSatiri(y, ilk, "nem", kabinOk ? kirp(kabinNem, 0.0f, 100.0f) : 0.0f, "%", zaman, kabinOk ? "iyi" : "yok");
        }
    }
    if (arkBekleyen) olcumSatiri(y, ilk, "ark_olay", (float)arkSayaci, "olay", zaman, "iyi");
    y.yaz("],");

    if (termalVar) {
        y.yaz("\"termal_ozet\":{\"maks\":%.2f,\"maks_konum\":[%d,%d],\"bolge_ort\":[%.2f,%.2f,%.2f,%.2f]},",
              (double)ozet.maks, ozet.sutun, ozet.satir,
              (double)ozet.bolge[0], (double)ozet.bolge[1], (double)ozet.bolge[2], (double)ozet.bolge[3]);
        y.yaz("\"termal_kare\":[");
        for (int i = 0; i < TERMAL_PIKSEL; i++) y.yaz(i ? ",%.2f" : "%.2f", (double)kare[i]);
        y.yaz("],");
    } else {
        y.yaz("\"termal_ozet\":null,\"termal_kare\":null,");
    }

    // ---- adım 9: modül sağlığı ----
    int sinyal = WiFi.status() == WL_CONNECTED ? WiFi.RSSI() : -120;
    sinyal = sinyal < -120 ? -120 : (sinyal > 0 ? 0 : sinyal);
    y.yaz("\"modul_durum\":{\"besleme\":\"%s\",\"sinyal\":%d,\"yazilim_surumu\":\"%s\"}}",
          sebeke ? "sebeke" : "yedek", sinyal, YAZILIM_SURUMU);

    // ---- gönder: paket → saha gateway'i → toplama POST /paket (sözleşme ②) ----
    if (y.tasti) {
        Serial.println("paket tampona sigmadi, gonderilmedi");
    } else if (WiFi.status() == WL_CONNECTED) {
        HTTPClient http;
        http.begin(TOPLAMA_URL);
        http.addHeader("Content-Type", "application/json");
        const int kod = http.POST((uint8_t*)yazBuf, strlen(yazBuf));
        if (kod == 200 || kod == 201) arkBekleyen = false;   // ark satırı yerine ulaştı
        Serial.printf("POST /paket -> %d (%u bayt, kare %s, %s)\n", kod, (unsigned)strlen(yazBuf),
                      termalVar ? "var" : "yok", dusukGuc ? "dusuk guc" : (sebeke ? "sebeke" : "yedek"));
        http.end();
    } else {
        Serial.println("wifi yok, paket atlandi");
        WiFi.reconnect();
    }

    // çevrimi 30 sn'ye tamamla (alt adımlar zaten 30 sn tutar; pay için)
    const uint32_t gecen = millis() - cevrimBaslangic;
    if (gecen < PAKET_S * 1000) delay(PAKET_S * 1000 - gecen);
}

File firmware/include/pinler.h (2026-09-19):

// Pin atamaları — docs/track-a/03-pinout.md §3.1 ile birebir.
// Tek doğruluk kaynağı 03'tür; burada bir pin değişirse önce 03 değişir.
#pragma once

// I²C (paylaşımlı): MLX90640 0x33, SHT31 0x44 (ADDR → GND)
constexpr int PIN_SDA = 8;
constexpr int PIN_SCL = 9;
constexpr uint8_t I2C_ADRES_MLX = 0x33;
constexpr uint8_t I2C_ADRES_SHT = 0x44;
constexpr uint32_t I2C_HIZ_HZ = 400000;  // 03 §3.2: 768 değerlik kare için fast mode şart

// Akım kanalları — hepsi ADC1 (Wi-Fi aktifken ADC2 kullanılamaz, 03 §3.1)
constexpr int PIN_CT_L1 = 4;    // ADC1_CH3
constexpr int PIN_CT_L2 = 5;    // ADC1_CH4
constexpr int PIN_CT_L3 = 6;    // ADC1_CH5
constexpr int PIN_CT_N = 7;     // ADC1_CH6

// Modbus RTU hattı: UART1 ↔ MAX3485 (03 §3.3)
constexpr int PIN_UART_TX = 17;  // U1TXD → DI
constexpr int PIN_UART_RX = 18;  // U1RXD ← RO
constexpr int PIN_DE_RE = 21;    // yön: TX sırasında HIGH

// Besleme algılama: 5V_RAW (D1 öncesi) 100k/47k bölücüyle → ADC1_CH0 (03 §3.1, §3.4)
constexpr int PIN_VSENSE = 1;

// Genişleme payı (03 §3.6): boş bırakılır. GPIO10 (ADC1_CH9), GPIO11.
// Strapping pinleri GPIO0/3/45/46, USB 19/20, UART0 43/44 kullanılmaz (03 §3.1).

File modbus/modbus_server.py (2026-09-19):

# /modbus/modbus_server.py
"""
Grid Up Hackathon - İZ C: Modbus TCP Sunucu Servisi
Sözleşme ④ uyarınca canlı modül verilerini dış SCADA/RTU sistemlerine
5020 portu üzerinden sunar.
Başlangıç Adresi = 100 + (N - 1) * 20
Gerçek API'den (Sözleşme ⑤) beslenir; veri gelmediğinde register'lara sıfır yazılmaz,
son geçerli durum korunur.
"""

import os
import sys
import logging
import asyncio
import aiohttp

try:
    if sys.stdout.encoding != 'utf-8':
        sys.stdout.reconfigure(encoding='utf-8')
    if sys.stderr.encoding != 'utf-8':
        sys.stderr.reconfigure(encoding='utf-8')
except Exception:
    pass

from pymodbus.server import StartAsyncTcpServer
from pymodbus.datastore import ModbusSequentialDataBlock, ModbusSlaveContext, ModbusServerContext

logging.basicConfig(
    level=logging.INFO,
    format="%(asctime)s - [%(levelname)s] - %(message)s"
)

# Anomali seviyeleri ve besleme durumu haritalaması (Sözleşme ④)
SEVIYE_MAP = {"normal": 0, "izle": 1, "uyari": 2, "kritik": 3}
BESLEME_MAP = {"sebeke": 0, "yedek": 1}

API_URL = os.getenv("API_URL", "http://localhost:8080").rstrip("/")
MODBUS_PORT = int(os.getenv("MODBUS_PORT", "5020"))
MODBUS_HOST = os.getenv("MODBUS_HOST", "0.0.0.0")
POLL_INTERVAL = float(os.getenv("MODBUS_POLL_INTERVAL", "5.0"))

class ModbusService:
    def __init__(self, max_moduller=10):
        self.max_moduller = max_moduller
        # Her modül için 20 register kapsayan blok (Adres 100'den başlar)
        total_registers = 100 + (max_moduller * 20) + 10
        self.registers = [0] * total_registers

        # PyModbus Holding Registers (hr) veri alanı
        self.store = ModbusSlaveContext(hr=ModbusSequentialDataBlock(0, self.registers))
        self.context = ModbusServerContext(slaves=self.store, single=True)
        # Modüllerin son geçerli değerlerini saklama (veri gelmediğinde sıfır yazılmaması için)
        self.modul_hafizasi: dict[int, list[int]] = {}

    def update_modul_data(self, modul_index: int, modul_detay: dict, termal_ozet: dict | None = None):
        """
        Modül verilerini Sözleşme ④'teki kurallara göre register'lara yazar.
        modul_index: 1-indexed (Örn: Modül 1 -> adres 100, Modül 2 -> adres 120)
        Veri gelmediğinde/eksik olduğunda sıfır yazılmaz, önceki değer korunur.
        """
        base_addr = 100 + (modul_index - 1) * 20
        mevcut_degerler = self.modul_hafizasi.get(modul_index, [0] * 20)

        # 1. Uzun format son_olcumler haritası
        son_olcumler = modul_detay.get("son_olcumler") or []
        olcumler = {o["olcum_tipi"]: o["deger"] for o in son_olcumler if "olcum_tipi" in o and "deger" in o}

        # 2. Termal Maksimum Sıcaklık
        termal_maks = None
        if termal_ozet and "maks" in termal_ozet and termal_ozet["maks"] is not None:
            termal_maks = termal_ozet["maks"]
        elif "termal_maks" in olcumler:
            termal_maks = olcumler["termal_maks"]

        # Yeni değerleri hazırla (varsa güncelle, yoksa önceki değeri koru - Madde 20)
        yeni_degerler = list(mevcut_degerler)

        if "ortam_sicaklik" in olcumler and olcumler["ortam_sicaklik"] is not None:
            yeni_degerler[0] = int(round(float(olcumler["ortam_sicaklik"]) * 10)) & 0xFFFF
        if "nem" in olcumler and olcumler["nem"] is not None:
            yeni_degerler[1] = int(round(float(olcumler["nem"]) * 10)) & 0xFFFF
        if "akim_l1" in olcumler and olcumler["akim_l1"] is not None:
            yeni_degerler[2] = int(round(float(olcumler["akim_l1"]) * 10)) & 0xFFFF
        if "akim_l2" in olcumler and olcumler["akim_l2"] is not None:
            yeni_degerler[3] = int(round(float(olcumler["akim_l2"]) * 10)) & 0xFFFF
        if "akim_l3" in olcumler and olcumler["akim_l3"] is not None:
            yeni_degerler[4] = int(round(float(olcumler["akim_l3"]) * 10)) & 0xFFFF
        if "akim_notr" in olcumler and olcumler["akim_notr"] is not None:
            yeni_degerler[5] = int(round(float(olcumler["akim_notr"]) * 10)) & 0xFFFF
        if termal_maks is not None:
            yeni_degerler[6] = int(round(float(termal_maks) * 10)) & 0xFFFF

        # 3. Anomali Seviyesi
        if "acik_anomaliler" in modul_detay and modul_detay["acik_anomaliler"] is not None:
            acik_anomaliler = modul_detay["acik_anomaliler"]
            en_kotu_seviye = 0
            for a in acik_anomaliler:
                s = str(a.get("seviye") or "normal").lower()
                en_kotu_seviye = max(en_kotu_seviye, SEVIYE_MAP.get(s, 0))
            yeni_degerler[7] = en_kotu_seviye & 0xFFFF
        elif "seviye" in modul_detay and modul_detay["seviye"] is not None:
            seviye_str = str(modul_detay["seviye"]).lower()
            yeni_degerler[7] = SEVIYE_MAP.get(seviye_str, 0) & 0xFFFF

        # 4. Besleme Durumu
        if "besleme" in modul_detay and modul_detay["besleme"] is not None:
            besleme_str = str(modul_detay["besleme"]).lower()
            yeni_degerler[8] = BESLEME_MAP.get(besleme_str, 0) & 0xFFFF

        # 5. Sinyal (RSSI)
        if "sinyal" in modul_detay and modul_detay["sinyal"] is not None:
            yeni_degerler[9] = int(modul_detay["sinyal"]) & 0xFFFF

        if "ark_olay" in olcumler and olcumler["ark_olay"] is not None:
            yeni_degerler[10] = int(olcumler["ark_olay"]) & 0xFFFF

        # Datastore güncelle ve hafızayı tazele
        self.modul_hafizasi[modul_index] = yeni_degerler
        self.store.setValues(3, base_addr, yeni_degerler)
        logging.debug(f"Modül {modul_index} (Adres {base_addr}) register'ları güncellendi.")
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

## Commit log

2026-09-13 İZ A: review bulgularını düzelt (PR-Agent + Copilot çapraz doğrulaması)
    Otomatik review'lerdeki gerçek buglar; yanlış pozitifler bilinçli dokümante edilmiş
    tasarım sınırı olarak bırakıldı.
    toplama:
    - Dockerfile: PYTHONPATH=/app:/app/toplama eklendi. WORKDIR=/app altında
    'import toplama.uygulama' namespace pakete bakıyor ve container hiç ayağa
    kalkmıyordu (Copilot'un kritik bulgusu, konteyner düzeni simüle edilerek
    doğrulandı).
    - kayit.py: olcum insert'üne RETURNING 1 eklendi; sayım fetchall() ile yapılıyor.
    psycopg3'te executemany sonrası rowcount yalnızca son satırı sayar, bu da yazılan
    ölçüm sayısını ve yinelenen tespitini bozuyordu (P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
2026-09-14 İZ A: cad/ — Fusion modelleri (.f3d/.step), model ve projeksiyon script'leri, SVG üreteçleri; README bağlantısı
    [GridUp-Kutu-Montaj.f3d, GridUp-Kutu-Montaj.step, GridUp-Kutu.f3d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]
2026-09-14 İZ A: cad/ — GridUp-Pano.step eklendi (xref kutu + PCB dahil, 78 solid); export.py Pano STEP atlamıyor; README
    [GridUp-Pano.step]
2026-09-14 İZ A: pano yerleşimi — NH ayırıcı derinliği 141,5 mm (Eaton EBV 00, Pub. 10275 s.5), bara sistemi 185 mm + mesnet izolatörü (s=0 en iyimser); kapsama NH yüzünde 673×361 mm @ 235,5; Fusion arşivleri (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
    [GridUp-Kutu-Montaj.f3d, GridUp-Kutu-Montaj.step, GridUp-Kutu.f3d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]
2026-09-14 İZ A: pano — bara kesiti 2×(100×10) mm² (şartname EK-I/8 Tablo 8, 1600 kVA; modelde faz başına tek 100×10), plaka cebi 500–990; montaj plakası ayrı gövde 'Pano plaka' (JOIN birleşmiyordu, 8f2a650'de 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
    [GridUp-Kutu-Montaj.f3d, GridUp-Kutu-Montaj.step, GridUp-Kutu.f3d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]
2026-09-14 İZ A: pano — bara grubu gerçekçi standoff: mesnet izolatörü 50 mm (Socomec L 33–70 / UL 40–71) + 2×(100×10) + 10 mm ara parça = s 80 mm; NH ön yüzü Z −208,5, sensör→NH 155,5 mm, kapsama 444×239 mm (s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
    [GridUp-Kutu-Montaj.f3d, GridUp-Kutu-Montaj.step, GridUp-Kutu.f3d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]
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2026-09-14 İZ A: eda/ — 03 bağlantı şemasının KiCad karşılığı: gen_sch.py üreteci (semboller KiCad kütüphanesinden), GridUp-Modul.kicad_sch, ERC 0 hata/0 uyarı, netlist 03 §3.1 ile otomatik doğrulanmış (91 kont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
    [GridUp-Modul.kicad_sch]
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2026-09-14 İZ A: 03-baglanti-semasi.svg artık KiCad şematiğinden üretiliyor (elle SVG kaldırıldı): sinyal akışına göre yerleşim (CT üst / I²C alt → ESP32 → servis / RS-485 / anten / genişleme; besleme altta), a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
    [GridUp-Modul.kicad_sch]
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2026-09-15 İZ A: model/şema datasheet düzeltmeleri — RAC05-05SK/277 31,7 × 26,7 × 21,8 (LDO/D1/D2/bölücü kaydırıldı); süperkap 2× Eaton HV1030-2R7106-R (Ø10,5 × 31,5, 10 F / 2,7 V seri, 10 k dengeleme) + TPS610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
    [GridUp-Kutu-Montaj.f3d, GridUp-Kutu-Montaj.step, GridUp-Kutu.f3d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]
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2026-09-15 İZ A: 03 şema — lejant başlığı iki satıra bölündü (viewBox sağ sınırını 13 mm aşıyordu), RS-485 blok başlığı kısaltıldı; tüm metinler Arial metriğiyle ölçüldü, taşma 0 (en yakın 3,1 mm içeride)
    [GridUp-Modul.kicad_sch]
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2026-09-15 Etiket dosyası formatı: kör testin cevap anahtarı
    Defines the label file format the blind-test tool reads, and makes the fixture
    set emit one. This is a contract track A must satisfy: lead time is a
    subtraction between the moment the detector first opened an episode and the
    moment the injected fault became critical, and only the generator knows the
    second number. If it is not written down the metric cannot exist.
    The format carries, per injected scenario: modul_id, which of the seven
    scenarios of section 7.6 was injected, the onset, and the critical time. Plus
    the list of modules deliberately left clean, without which the false-alarm rate
    has no denominator and section 4.4 calls the set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
2026-09-15 Sözleşme ⑤: okuma API'si, kendi sürecinde
    Every endpoint in section 7.3 of the parent record plus the /gecisler one the
    İZ B record adds — eleven in total. Paths, query parameters and field names are
    the contract's and are served as written: track C builds against them, and a
    helpful rename here is a silent breakage there. A test asserts the full path
    list, so a dropped endpoint fails here rather than during integration.
    Served as its own process (python -m analiz.api, or `analiz sunucu`), per
    decision K1. The database is the only contact surface between components, and
    that holds inside track B too: a crashed API must not be able to stop the
    detector, and a long scan turn must not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
2026-09-15 Varsayılan tarama periyodu 10 sn → 30 sn
    Section 3.7 names 10 s and marks it adjustable. The T5 load test is why it is
    now 30: a turn at 100 modules takes ~19 s, so at a 10 s period the detector is
    permanently behind at the fleet size section 7.7 targets, while the same work
    fits inside 30 s with room to spare.
    Nothing is lost. Section 3.5 fixes the timescale of every event this system
    detects at minutes to hours — a loose terminal takes days, overload hours — so
    20 s of additional latency is invisible against them. The one event needing an
    instant response is the arc, and that is the TVOC-2's job (SIL-2,
    sub-millisecond); we relay its record, and relaying it 20 s later changes
    nothi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
2026-09-16 İZ A: 03 şema — TPS61099 bobini L1 4,7 → 2,2 µH (datasheet §7.3: 0,7 / 2,2 / 2,86 µH; 4,7 spesifikasyon dışıydı); şema, netlist ve SVG yeniden üretildi, ERC 0/0, netlist 103/103, metin taşması 0
    [GridUp-Modul.kicad_sch]
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2026-09-16 İZ B entegrasyon: modül durumu, saat kayması, kanıt karesi, ikili kare, API (8–13)
    - 8: modul_durum satırları pencereye alınır (ModulDurumu); katman 0
    besleme=yedek ve zayıf sinyal için modul_saglik üretir, eşikler
    Katman0Ayari'nda. Tarama döngüsü modul_durum varışlarını da "yeniden
    değerlendir" sinyali sayar.
    - 9: saat kayması kuralı tabloya göre yeniden yazıldı (ileri tarihli →
    kesin; min gecikme > eşik → kayma; min≈0, maks yüksek → geç veri, anomali
    değil). /saglik `veri_gecikmesi` metriğini verir.
    - 10: kanıt karesi değerlendirme anına ait olan kare (an'dan sonraki kare
    asla bağlanmaz; pencere dışı kare de bağlanmaz).
    - 11: anal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
2026-09-16 İZ A: 3B modeller bulutla eşitlendi ve doğrulandı — Fusion bulut belgeleri eski kalmıştı (PCB v2 32 gövde, Kutu v8 eski rakor sırası); model_pcb/model_kutu yeniden çalıştırılıp kaydedildi (PCB v3 37 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
    [GridUp-Kutu-Montaj.f3d, GridUp-Kutu-Montaj.step, GridUp-Kutu.f3d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]
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2026-09-17 İZ A: MLX90640 gövde çapı datasheet'e çekildi — model Ø9, datasheet Ø9,30 ±0,15 (REV 12 §15.2 Şekil 29) → Ø9,3 (maks. zarf kuralı, süperkap/RAC05 ile aynı ilke); IR pencere Ø15 olduğu için çakışma yo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
    [GridUp-Kutu-Montaj.f3d, GridUp-Kutu-Montaj.step, GridUp-Kutu.f3d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]
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2026-09-17 İZ A: SVG gözden geçirme turu 1 — 02: boost U7 + L MLX90640'ın arkasından X 46–49 / Y 31,5–38'e taşındı (sensör ekseninde parça yoktu ama çizimde dairenin içine düşüyordu), etiketlere zemin renkli ar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
    [GridUp-Kutu-Montaj.f3d, GridUp-Kutu-Montaj.step, GridUp-Kutu.f3d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]
2026-09-17 İZ A: 02 — boost U7 + L, Ø15 IR ekseni dairesinin dışına (X 43,5–46,5; daire 47,5'te biter, 1–1,5 mm pay); PCB v7 / Montaj v13 / Pano v17, f3d/step/views/02-04 SVG yeniden
    [GridUp-Kutu-Montaj.f3d, GridUp-Kutu-Montaj.step, GridUp-PCB.f3d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]
2026-09-17 İZ A: 02 — dengeleme dirençleri (R_bal) Ø15 IR ekseni dairesinin dışına (X 48–50 / Y 26–29,5); Fusion'da aynı adlı eski referans kopyaları (PCB v3/v4/v6) proj/export'u yanıltıyordu → son eşleşen kull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
    [GridUp-Kutu-Montaj.f3d, GridUp-Kutu-Montaj.step, GridUp-PCB.f3d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]
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2026-09-17 İZ A: 02 gözden geçirme kapanışı — M3 etiketi deliğin yanına; Pano modeli son PCB (R_bal) referansıyla yeniden kuruldu (v19, 04-yerleşim değişmedi); 5 SVG'de taşma 0
    [GridUp-Pano.f3d, GridUp-Pano.step]
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2026-09-17 İZ A: 03 — aynalı sembollerde (J1 iç ihtiyaç, J2–J5 CT) değer metni hizası aynalandığı için çerçeve dışına taşıyordu → justify right; F1 etiketleri J1 değeriyle ve PWR_FLAG ile çakışmasın diye sağa/y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
    [GridUp-Modul.kicad_sch]
2026-09-17 İZ A: 03 — V_bias notu '3V3/2 = 1,65 V (CT DC ofseti)'
    [GridUp-Modul.kicad_sch]
2026-09-17 İZ A: 03 — V_bias notu '3,3 V / 2 = 1,65 V'
    [GridUp-Modul.kicad_sch]
2026-09-17 İZ A: 03 — V_bias notu '3V3 / 2 = 1,65 V'
    [GridUp-Modul.kicad_sch]
2026-09-17 İZ A: 03 — güç sembollerinin (+3V3/+5V, ok yukarı) değer yazısı okun üstünde ortalı (KiCad varsayılanı; 'center' = justify düğümü yok); 'EN: RC + reset butonu' notu +3V3 okuyla çakışmasın diye yukarı
    [GridUp-Modul.kicad_sch]
2026-09-17 İZ A: 03 — atlama yayları gerçekten çiziliyor: kicad_pro 'hop_over_size_choice' 0 (kapalı) → 2; --draw-hop-over tek başına yetmiyordu, lejant iddiası boştaydı (3 kesişme: I²C ×2, DE_RE/U1RXD); DE_RE 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
    [GridUp-Modul.kicad_sch]
2026-09-17 İZ A: 03 — MLX90640 özel sembolü büyütüldü (±10,16, daire r 4; pin adları daireye binmiyor), U2 ref/val ve C2 kutunun soluna; SHT31 ADDR/RESET güç etiketleri ayrıldı (GND üstte, +3V3 altta)
    [GridUp-Modul.kicad_sch]
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2026-09-18 İZ A: 08 — 'Durum' notu: çizim karar kaydı §8 hedef mimarisi; bugün gerçek olan ve olmayan ayrıldı
    Kutu içleri gerçek koddan (main + PR #2), ama bazı bağlantılar henüz varsayımsal:
    - gerçek uçtan uca zincir: modul-sim → toplama → PostgreSQL → analiz → :8080 (main)
    - İZ C servisleri (alarm, modbus) API_URL=mock_api:8000/api okuyor, İZ B'nin :8080 API'sine bağlı değil
    - PR #2 docker-compose yalnız arayuz + mock_api + modbus + alarm; toplama/analiz/PostgreSQL yok
    - gateway ve pano donanımı yok (kavramsal, §7.4)
    Alt nota bu durum yazıldı; kaynak satırı kısaltıldı.
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2026-09-18 İZ A: temizlik dalı düzeltmeleri: modul-sim README senaryo adları koddaki gibi (faz_dengesizlik, nem_yuksek, ark_olay, sensor_ariza, modul_saglik), olcumler/termal_kare açıklaması, ek parametreler; t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
2026-09-19 Fix deployment and simulator paths
    Updated Docker and Compose build contexts to match the repo root layout, corrected copied file paths, and added a localhost fallback for the simulator when running outside the container. Also fixed repo-root import discovery for the simulator and tool configuration, refreshed package metadata generated files, and normalized source header comments to reflect the current project structure.
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2026-09-19 Add live module and multi-series UI updates
    This update refreshes module status badges in the hierarchy and header, keeps polling in sync, and adds range-based time-series queries with auto-bucket fallback. It also introduces multi-metric plotting for 3-phase current, richer metric labels, hover tooltips, and reticle positioning fixes. Tests cover status propagation, history-range requests, auto-expanding buckets, and multi-series rendering.
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
